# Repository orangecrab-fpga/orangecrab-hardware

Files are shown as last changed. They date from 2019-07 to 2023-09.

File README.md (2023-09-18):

# OrangeCrab
[OrangeCrab Web site](https://orangecrab-fpga.github.io/orangecrab-hardware/)

## ECP5 FPGA Feather development board.
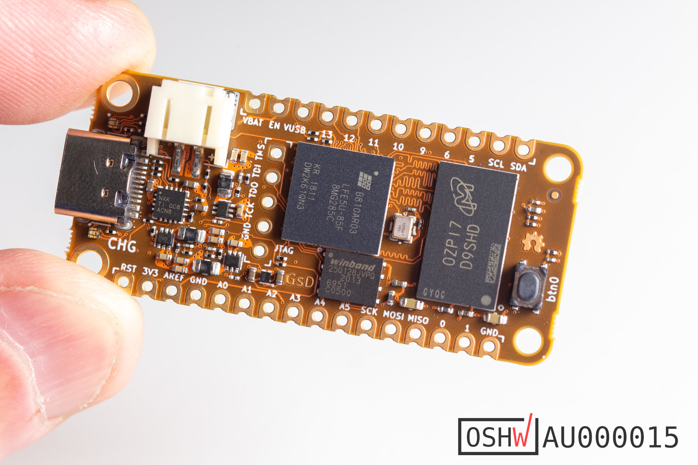
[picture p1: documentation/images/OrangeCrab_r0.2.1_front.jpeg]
Front Photo


## Latest Revision: 
* [OrangeCrab r0.2.1](hardware/orangecrab_r0.2.1/)

Previous Revisions:
* [OrangeCrab r0.2](hardware/orangecrab_r0.2/)
* [OrangeCrab r0.1](hardware/orangecrab_r0.1/)

---

## What is it?
There aren't many OSHW ECP5 boards available. Given that this FPGA is fully supported by an open source toolchain I decided to create one. In order to make use of the DDR3L support the ECP5 has, I've added some DDR3L memory. The board matches the feather format

## Hardware Overview
* Lattice ECP5-25F or ECP5-85F FPGA in csfBGA285 package
    * 24 K - Look Up Tables
    * 1008 Kb - Embedded Block RAM
    * 194 Kb - Distributed RAM
    * 28 - 18x18 Multipliers
    * PLLs: 2
    * Internal oscillator
    * Flexible I/O for DDR3 Memory Support
* DDR3L Memory
    * 128 Mbytes (1Gbit) or 512Mbytes (4Gbit)
    * x16 data width to FPGA
    * 1.35V low voltage operation
* USB-C connection
    * Full-speed (12Mbit) USB with direct connection to FPGA
* Non-volatile Storage
    * 128Mbit QSPI FLASH Memory 
        * Bootloader (First 4Mbits)
        * User Bitstream
        * User storage (Firmware/MSC backend/etc)
        * QSPI compatible
    * MicroSD socket
        * 4bit SD interface (CK, CMD, DAT0-3)
* Power supply
    * High efficiency DCDC for main supplies
    * Battery charger (100mA), with charge indicator LED
    * LiPo battery connector (PH type) (1-cell: 3.7-4.2V)
* 48MHz onboard oscillator
* Accessible 0.1" JTAG breakout
* User I/O
    * 1x Button 
    * 1x RGB LED
    * 20x I/O on 0.1" headers
* Analog System
    * Analog Mux
    * SAR ADC, external RC / input comparator of FPGA
    * Digital bypass
    * Internal channels for supply monitor
    * Battery voltage sensing
* Feather Format Board
    * Dimensions: 22.86mm x 50.8mm (0.9" x 2.0")
    * Castellated I/O edges
---

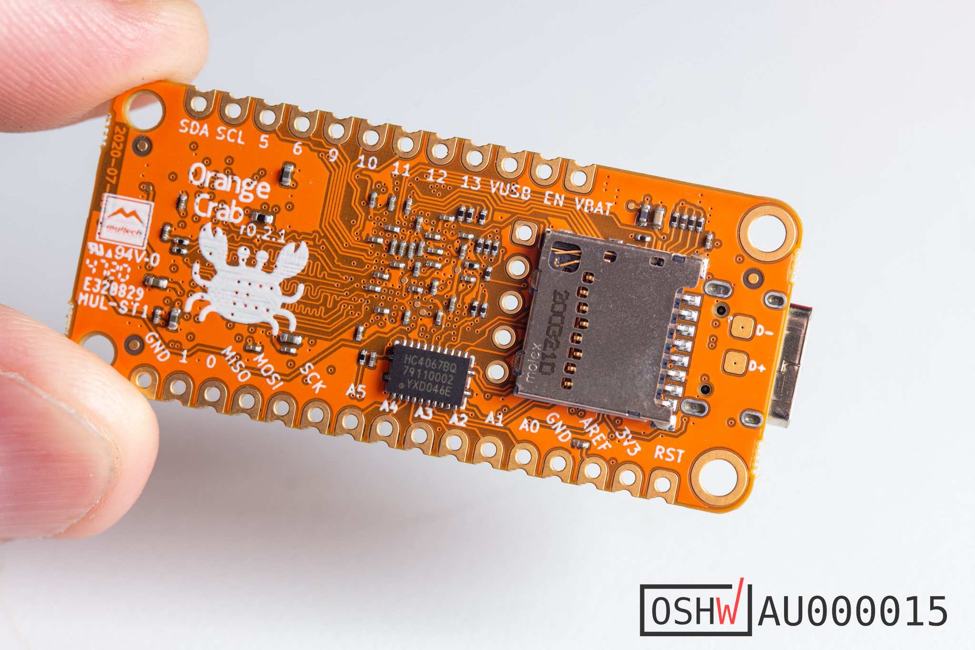
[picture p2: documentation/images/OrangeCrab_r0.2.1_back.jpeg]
Back Photo


## Example code
Example code for Verilog, Litex, And RiscV can be found here:

* [Orange Crab Examples](https://github.com/orangecrab-fpga/orangecrab-examples)

## Community

We have an OrangeCrab group on the 1BitSquared Discord 

 * https://discord.gg/c4Dnr3b

## Licence

 * Hardware in this repository is licensed under CERN OHL v1.2
 * Gateware/Software/Firmware in this repository is licensed under MIT unless otherwise indicated

 ## Open Source Hardware
This board is an OSHWA approved design: [AU000015](https://certification.oshwa.org/au000015.html)

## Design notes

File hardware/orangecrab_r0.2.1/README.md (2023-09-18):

# OrangeCrab r0.2.1
## ECP5 Feather development board.

Front Photo

	Hardware r0.2.1 has run through a production run and available at GroupGets, element14.
    
---

## What is it?
There aren't many OSHW ECP5 boards available. Given that this FPGA is fully supported by an open source toolchain I decided to create one. In order to make use of the DDR3L support the ECP5 has, I've added some DDR3L memory. The board matches the feather format

## Hardware Overview
* Lattice ECP5-25F or ECP5-85F FPGA in csfBGA285 package
    * 24 K - Look Up Tables
    * 1008 Kb - Embedded Block RAM
    * 194 Kb - Distributed RAM
    * 28 - 18x18 Multipliers
    * PLLs: 2
    * Internal oscillator
    * Flexible I/O for DDR3 Memory Support
* DDR3L Memory
    * 128 Mbytes (1Gbit) or 512Mbytes (4Gbit)
    * x16 data width to FPGA
    * 1.35V low voltage operation
* USB-C connection
    * Full-speed (12Mbit) USB with direct connection to FPGA
* Non-volatile Storage
    * 128Mbit QSPI FLASH Memory 
        * Bootloader (First 4Mbits)
        * User Bitstream
        * User storage (Firmware/MSC backend/etc)
        * QSPI compatible
    * MicroSD socket
        * 4bit SD interface (CK, CMD, DAT0-3)
* Power supply
    * High effeciency DCDC for main supplies
    * Battery charger (100mA), with charge indicator LED
    * LiPo battery connector (PH type) (1-cell: 3.7-4.2V)
* 48MHz onboard oscillator
* Accesible 0.1" JTAG breakout
* User I/O
    * 1x Button 
    * 1x RGB LED
    * 20x I/O on 0.1" headers
* Analog System
    * Analog Mux
    * SAR ADC, external RC / input comparator of FPGA
    * Digital bypass
    * Internal channels for supply monitor
    * Battery voltage sensing
* Feather Format Board
    * Dimensions: 22.86mm x 50.8mm (0.9" x 2.0")
    * Castellated I/O edges

---

Back Photo

## Licence

 * Hardware in this repository is licensed under CERN OHL v1.2
 * Gateware/Software/Firmware in this repository is licensed under MIT unless otherwise indicated

 ## Open Source Hardware
This board is an OSHWA approved design: [AU000015](https://certification.oshwa.org/au000015.html)

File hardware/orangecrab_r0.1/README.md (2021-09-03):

# Orange Crab r0.1

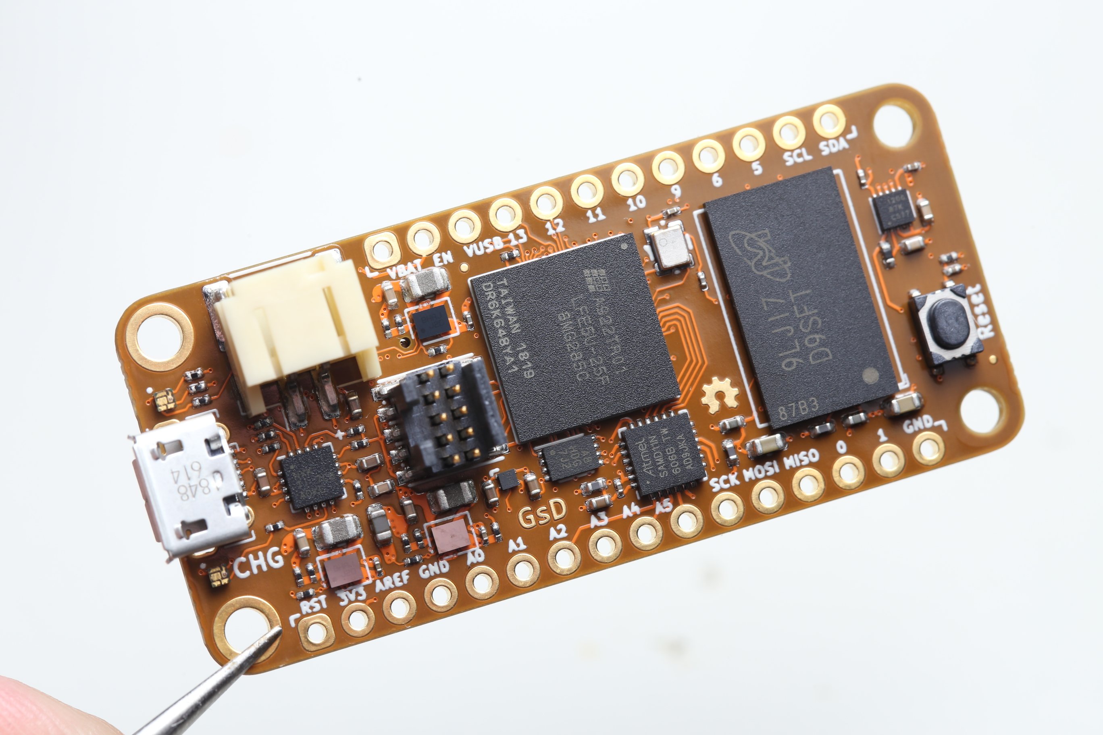
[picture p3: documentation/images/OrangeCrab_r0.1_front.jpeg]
Front


## ECP5 DDR3 memory in a Feather form-factor.

	Hardware r0.1 is not the latest hrdware version. There are some bugs listed below.

## What is it
Project goal: "Make a simple ECP5 breakout board with DDR3L memory". As that was the only design goal I also decide it might be nice to keep the overal size small and make it an adafruit feather compatible dev board.

## Hardware Overview
* Lattice ECP5 25 (With limited support for 45/85 variants)
* DDR3L Memory upto 1Gbit (64Mbit x16)
* Micro USB connection
* Full-speed (12Mbit) USB direct connection to FPGA
* Battery charger, with charge indicator LED (1-cell: 3.7-4.2V)
* Reset Button 
* 16Mbit QSPI FLASH Memory (Bitstream + User storage)
* 4bit MicroSD socket
* 48MHz Oscillator (Used by USB system)
* ATSAMD10/11 Co-processor planned mainly for the ADC/DAC
* Spare 3.3V I/O's broken out onto a 30pin low profile connector
  * 7 diff pairs
  * 1 single ended only

## Errata
 1. FLASH footprint only supports devices upto 16Mbit in size, This is enough for a bootloader and user gateware on the 25/45F parts, but not enough for a fully loaded 85F design.
 2. DDR3 traces are quite close, violating the recommended 6mil clearance. Tests appear to indicate this isn't a huge deal on this design.
 3. No firmware was ever written for the SAMD11 co-precessor, so A0-A5 don't do anything.
 4. LED resistor values are not tuned very well, resulting in very bright USB-Present LED.
 5. The button is tied directly to `PROGRAMN` pin on the FPGA, this means pressing the button resets the device. (Which is used to toggle between user/bootloader gateware)

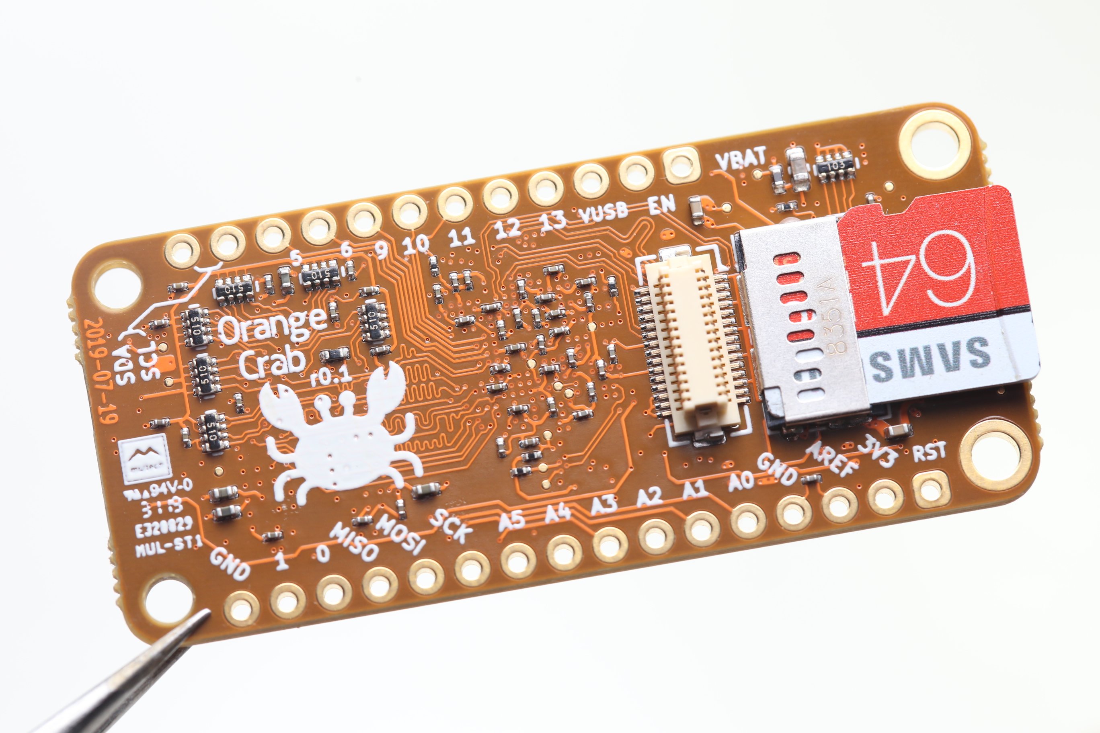
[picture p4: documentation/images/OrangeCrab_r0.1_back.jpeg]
Back Photo Back


## Licence

 * Hardware in this repository is licenced under CERN OHL v1.2
 * Gateware/Software/Firmware in this repository is licenced under MIT unless otherise indicated

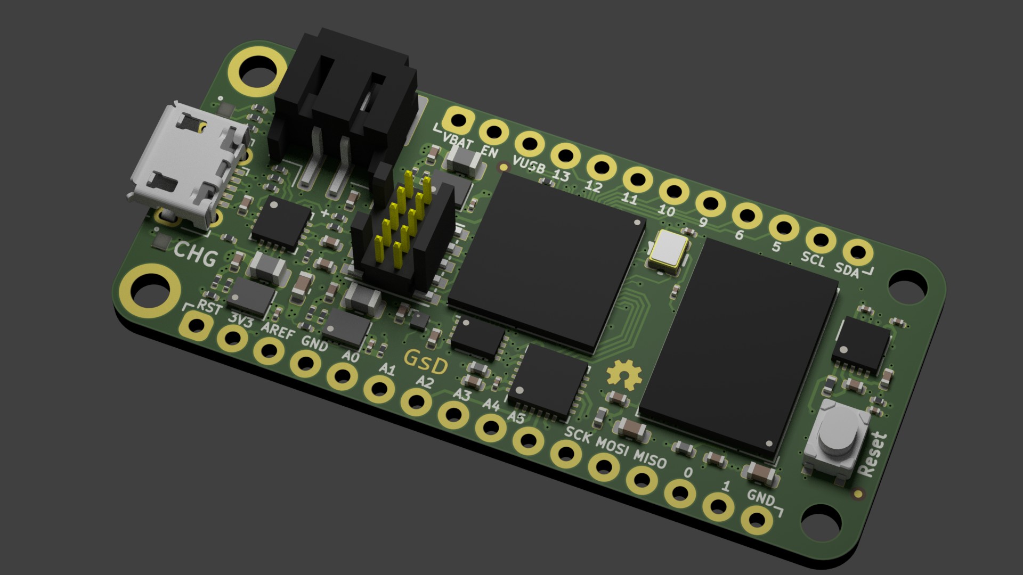
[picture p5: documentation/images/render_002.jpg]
Front Render


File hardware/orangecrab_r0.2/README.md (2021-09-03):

# OrangeCrab r0.2
## ECP5 Feather development board.

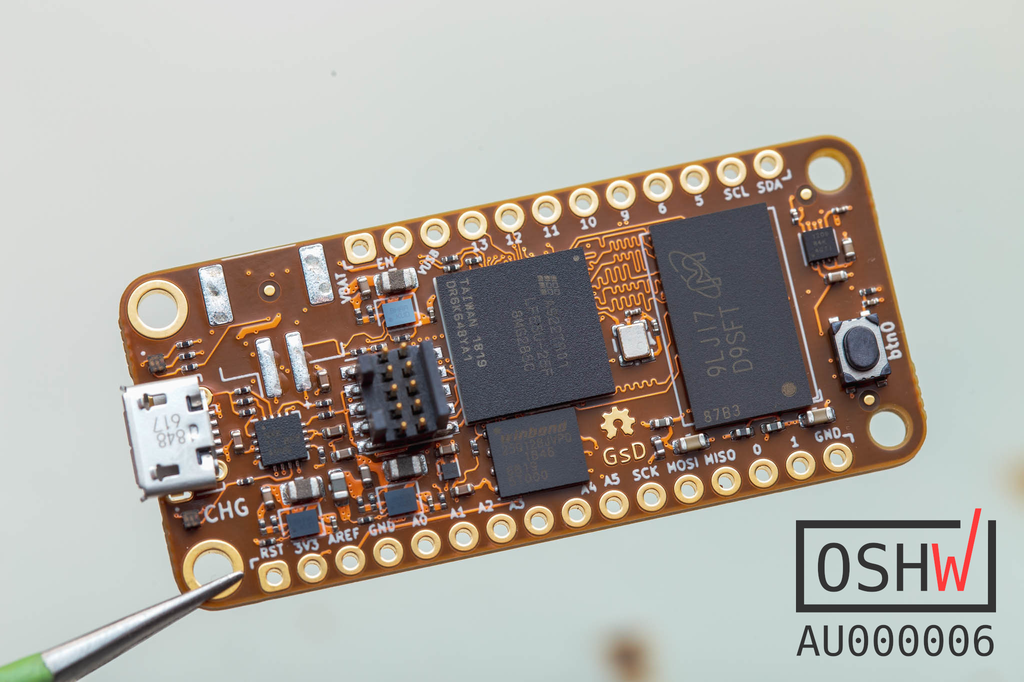
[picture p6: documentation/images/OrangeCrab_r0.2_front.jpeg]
Front Photo


	Hardware r0.2 will go though a short production run soon™
    
---

## What is it?
There aren't many OSHW ECP5 boards available. Given that this FPGA is fully supported by an open source toolchain I decided to create one. In order to make use of the DDR3L support the ECP5 has, I've added some DDR3L memory. The board matches the feather format

## Hardware Overview
* Lattice ECP5-25F FPGA in csfBGA285 package
    * 24 K - Look Up Tables
    * 1008 Kb - Embedded Block RAM
    * 194 Kb - Distributed RAM
    * 28 - 18x18 Multipliers
    * PLLs: 2
    * Internal oscillator
    * Flexible I/O for DDR3 Memory Support
* DDR3L Memory
    * 128 Mbytes (1Gbit)
    * 64M x16
    * 1.35V low voltage operation
* Micro USB connection
    * Full-speed (12Mbit) USB with direct connection to FPGA
* Non-volatile Storage
    * 128Mbit QSPI FLASH Memory 
        * Bootloader (First 4Mbits)
        * User Bitstream
        * User storage (Firmware/MSC backend/etc)
        * QSPI compatible
    * MicroSD socket
        * 4bit SD interface (CK, CMD, DAT0-3)
* Power supply
    * High effeciency DCDC for main supplies
    * Battery charger (100mA), with charge indicator LED
    * LiPo battery connector (PH type) (1-cell: 3.7-4.2V)
* 48MHz onboard oscillator
* Standard 0.05" JTAG connector
* User I/O
    * 1x Button 
    * 1x RGB LED
    * 20x I/O on 0.1" headers
* Analog System
    * Analog Mux
    * SAR ADC, external RC / input comparator of FPGA
    * Digital bypass
    * Internal channels for supply monitor
    * Battery voltage sensing
* Feather Format Board
    * Dimensions: 22.86mm x 50.8mm (0.9" x 2.0")

---

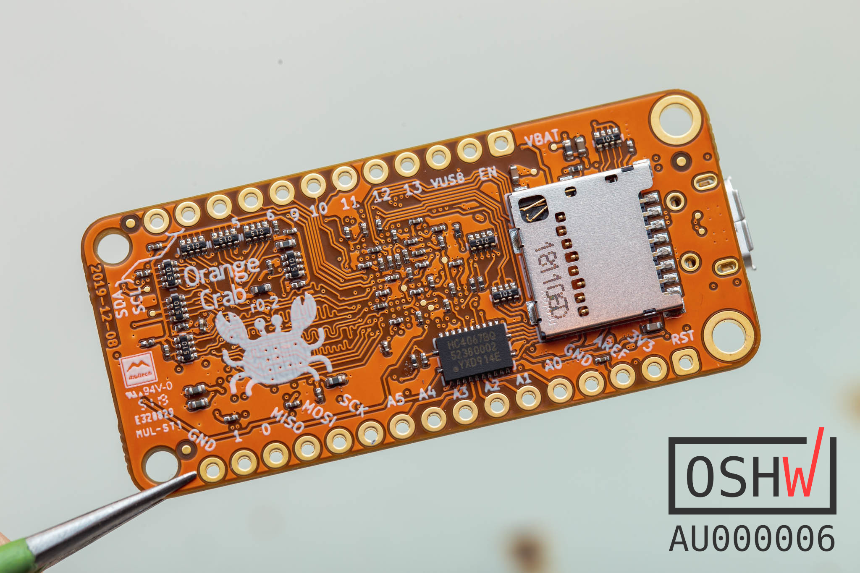
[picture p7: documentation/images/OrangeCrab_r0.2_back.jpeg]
Back Photo


## Licence

 * Hardware in this repository is licenced under CERN OHL v1.2
 * Gateware/Software/Firmware in this repository is licenced under MIT unless otherise indicated

 ## OSHW
This board is an OSHWA approved design: [AU000006](https://certification.oshwa.org/au000006.html)

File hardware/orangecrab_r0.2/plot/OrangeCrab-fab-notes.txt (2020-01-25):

Part number:        OrangeCrab-r0.2

General fabrication notes

    * Boards are to be panelised with tab/route, 5 by 1 pattern.
    * Board material is S1000-2
    * Orange solder mask (Colour reference: #FF8000) on both sides of board. All vias to be tented.
    * High DPI White LPI legend on both sides of board.
    * Pad finish is ENIG.
    * Finished board thickness is 1.6 mm.
    * Place UL mark and date code on legend on backside of board.

Impedances

    Control to within 10%.

    Layer 1 microstrip (ref to layer 2 Ground)
        121 μm trace = 50 ohm single ended

    Layer 3 microstrip (ref to layer 2 Ground / 4 Power)
        121 μm trace = 50 ohm single ended
        105 μm trace / 150 μm space = 100 ohm differential
        130 μm trace / 150 μm space = 90 ohm differential

    Layer 6 microstrip (ref to layer 5 Ground)
        121 μm trace = 50 ohm single ended
        105 μm trace / 150 μm space = 100 ohm differential

Suggested stackup Adjust to meet impedances
    1   35 μm (1 oz) copper         Signal
        0.075mm prepreg
    2   35 μm (1 oz) copper         Ground
        0.075mm prepreg
    3   35 μm (1oz) copper          Signal
        Core(s) and prepregs as needed for 1.6mm finished PCB thickness
    4   35 μm (1 oz) copper         Power
        0.075mm prepreg
    5   35 μm (1 oz) copper         Ground
        0.075mm prepreg
    6   35 μm (1 oz) copper         Signal

File naming
    OrangeCrab-Edge_Cuts.gbr        Board outline
    OrangeCrab-PTH.drl              Through-board plated holes
    OrangeCrab-NPTH.drl             Through-board unplated holes
    OrangeCrab-SilkTop.gbr          Front silkscreen
    OrangeCrab-MaskTop.gbr          Front solder mask
    OrangeCrab-CuTop.gbr            Layer 1 copper (Front)
    OrangeCrab-inner1.gbr           Layer 2 copper
    OrangeCrab-inner2.gbr           Layer 3 copper
    OrangeCrab-inner3.gbr           Layer 4 copper
    OrangeCrab-inner4.gbr           Layer 5 copper
    OrangeCrab-CuBottom.gbr         Layer 6 copper (Back)
    OrangeCrab-MaskBottom.gbr       Back solder mask
    OrangeCrab-SilkBottom.gbr       Back silkscreen

    OrangeCrab-PTH-drl_map.pdf      Drill Map Reference plated
    OrangeCrab-NPTH-drl_map.pdf     Drill Map Reference non-plated

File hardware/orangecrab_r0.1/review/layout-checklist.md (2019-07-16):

# Layout review checklist

## General

* [X] [Schematic review](schematic-checklist.md) complete and signed off, including pin swaps done during layout
* [X] Layout DRC 100% clean

## Decoupling

* [X] Decoupling caps as close to power pins as possible
* [X] Low inductance mounting used for decoupling (prefer ViP if available, otherwise "[]8" shaped side vias
   * No ViP available. Larger tracks used to help reduce inductance.

## DFM / yield enhancement

* [X] All design rules within manufacturer's capability
* [X] Minimize use of vias/traces that push fab limits
    * 0.15mm vias are un-avoidable. Design has been Checked by manufacturer
* [X] Controlled impedance specified in fab notes if applicable
    * Using values based on my suggested stackup and from ciPCB
* [-] Stackup verified with manufacturer and specified in fab notes
    * Still to be validated by Fab engineers.
* [X] Board finish specified in fab notes
* [X] If panelizing, add panel location indicators for identifying location-specific reflow issues
* [NA] (recommended) Layer number markers specified to ensure correct assembly
    * Lack of physical space :(
* [X] Fiducials present (on both sides of board) if targeting automated assembly
* [X] Fiducial pattern asymmetric to detect rotated or flipped boards
* [X] Soldermask/copper clearance on fiducials respected
* [X] Panelization specified if required
    * Fab has created panelisation

## Footprints

* [X] Confirm components are available in the selected package
* [X] Verify schematic symbol matches the selected package
* [X] Confirm pinout diagram is from top vs bottom of package
* [-] (recommended) PCB printed 1:1 on paper and checked against physical parts
    * TODO
* [X] 3D models obtained (if available) and checked against footprints
    * And rendered!
* [X] Soldermask apertures on all SMT lands and PTH pads

## Differential pairs
* [X] Routed differentially
* [X] Skew matched
* [-] Correct clearance to non-coupled nets
    * Tricky to do with space contraints. 

## High-speed signals

* [X] Sufficient clearance to potential aggressors
* [X] Length matched if required
* [X] Minimize crossing reference plane splits/slots or changing layers, use caps/stitching vias if unavoidable
* [NA] Confirm fab can do copper to edge of PCB for edge launch connectors
* [NA] Double-check pad width on connectors and add plane cutouts if needed to minimize impedance discontinuities

## Power
* [X] Minimal slots in planes from via antipads
* [X] Sufficient width for planes/traces for required current

## Sensitive analog
* [NA] Guard ring / EMI cages provided if needed
* [NA] Physically separated from high current SMPS or other noise sources
* [NA] Consider microphone effect on MLCCs if near strong sound sources

## Mechanical
* [X] LEDs, buttons, and other UI elements on outward-facing side of board
* [X] Keep-outs around PCB perimeter, card guides, panelization mouse-bites, etc respected
* [X] Stress-sensitive components (MLCC) sufficiently clear from V-score or mouse bite locations, and oriented to reduce bending stress
* [NA] Clearance around large ICs for heatsinks/fans if required
* [X] Clearance around pluggable connectors for mating cable/connector
* [X] Clearance around mounting holes for screws
* [NA] Plane keepouts and clearance provided for shielded connectors, magnetics, etc
* [X] Confirm PCB dimensions and mounting hole size/placement against enclosure or card rack design
* [X] Verify mounting hole connection/isolation
* [X] Components not physically overlapping/colliding
* [NA] Clearance provided around solder-in test points for probe tips

## Thermal

* [X] Thermal reliefs used for plane connections (unless via is used for heatsinking)
* [X] Solid connections used to planes if heatsinking
* [X] Ensure thermal balance on SMT chip components to minimize risk of tombstoning

## Solder paste

* [X] No uncapped vias in pads (except low-power QFNs where some voiding is acceptable)
* [ ] QFN paste prints segmented
* [ ] Small pads 100% size, larger pads reduced to avoid excessive solder volume

## Solder mask

* [X] Confirm SMD vs NSMD pad geometry
* [X] Adequate clearance around pads (typ. 50 um)

## Silkscreen

* [X] Text size within fab limits
* [X] Text not overlapping drills or component pads
* [X] Text removed entirely in, or moved outside of, high component/via density areas
* [X] Traceability markings (rev, date, name, etc) provided
* [NA] Silkscreen box provided for writing/sticking serial number
* [X] Text mirrored properly on bottom layer

## Flex specific
* [NA] Components oriented to reduce bending forces
* [ ] Teardrops on all wire-to-pad connections

## CAM production
* [ ] KiCAD specific: rerun DRC and zone fills before exporting CAM files to ensure proper results
* [ ] Export gerber/drill files at the same time to ensure consistency
* [ ] Visually verify final CAM files to ensure no obvious misalignments

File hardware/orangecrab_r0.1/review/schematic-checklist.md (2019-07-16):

# Schematic review checklist

## General

- [NA] CAD ERC 100% clean. If some errors are invalid due to toolchain quirks, each exception must be inspected and signed off as invalid.
- [X] Verify pin numbers of all schematic symbols against datasheet (if not yet board proven).
- [X] Schematic symbol matches chosen component package
- [X] Thermal pads are connected to correct power rail (may not always be ground)
- [x] Debug interfaces are not power gated in sleep mode

## Passive components
* [X] Power/voltage/tolerance ratings specified as required
* [X] Ceramic capacitors appropriately de-rated for C/V curve
* [X] Polarized components specified in schematic if using electrolytic caps etc

## Power supply

### System power input

* [NA] Fusing and/or reverse voltage protection at system power inlet
* [x] Check total input capacitance and add inrush limiter if needed

### Regulators

* [NA] Under/overvoltage protection configured correctly if used
* [X] Verify estimated power usage per rail against regulator rating
* [NA] Current-sense resistors on power rails after regulator output caps, not in switching loop
 * To reduce BOM this have been omitted, will cut traces during board bringup to validate power supplies.
* [NA] Remote sense used on low voltage or high current rails
* [X] Linear regulators are stable with selected output cap ESR
* [X] Confirm power rail sequencing against device datasheets

### Decoupling
* [X] Decoupling present for all ICs
* [X] Decoupling meets/exceeds vendor recommendations if specified
* [X] Bulk decoupling present at PSU

### General
* [X] All power inputs fed by correct voltage
* [NA] Check high-power discrete semiconductors and passives to confirm they can handle expected load
* [X] Analog rails filtered/isolated from digital circuitry as needed

## Signals

### Digital

* [X] Signals are correct logic level for input pin
* [X] Pullups on all open-drain outputs
* [NA] Pulldowns on all PECL outputs
* [X] Termination on all high-speed signals
* [NA] AC coupling caps on gigabit transceivers
* [X] TX/RX paired correctly for UART, SPI, MGT, etc
* [X] Differential pair polarity / pairing correct
* [X] Active high/low enable signal polarity correct
* [X] I/O banking rules met on FPGAs etc

### Analog

* [NA] RC time constant for attenuators sane given ADC sampling frequency
* [NA] Verify frequency response of RF components across entire operating range. Don't assume a "1-100 MHz" amplifier has the same gain across the whole range.

### Clocks

* [X] All oscillators meet required jitter / frequency tolerance. Be extra cautious with MEMS oscillators as these tend to have higher jitter.
* [NA] Correct load caps provided for discrete crystals
* [X] Crystals only used if IC has an integrated crystal driver
* [X] Banking / clock capable input rules met for clocks going to FPGAs

### Strap/init pins
* [ ] Pullup/pulldowns on all signals that need defined state at boot
* [X] Strap pins connected to correct rail for desired state
* [x] JTAG/ICSP connector provided for all programmable devices
    * GsD: SAMD has test pads exposed via test-points
* [x] Config/boot flash provided for all FPGAs or MPUs without internal flash
* [NA] Reference resistors correct value and reference rail

### External interface protection

* [NA] Power outputs (USB etc) current limited
* [NA] ESD protection on data lines going off board

### Debugging / reworkability

* [NA] Use 0-ohm resistors vs direct hard-wiring for strap pins when possible
* [X] Provide multiple ground clips/points for scope probes
* [x] Dedicated ground in close proximity to analog test points
* [X] Test points on all power rails
* [x] Test points on interesting signals which may need probing for bringup/debug
 * Added bottom test points to JTAG
 * DDR3 has termination on all Address lines, Upper byte traces are accesible on back layer.
 * Added USB Test pads

## Thermal

* [X] Power estimates for all large / high power ICs
    * ECP5 (@ 20% utilisation) 1/4W
* [NA] Thermal calculations for all large / high power ICs
* [NA] Specify heatsinks as needed

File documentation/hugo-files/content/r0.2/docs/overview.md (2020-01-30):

---
title: Overview
type: docs
rev: r0.2
---

# Overview

The OrangeCrab is a small pocket sized development board in the Adafruit feather format. While small in size it packs a punch! The standard version is equiped with a Lattice ECP5 FPGA, and DDR3L memory. Paired with the FPGA is a FLASH chip, with enough memory to store multiple bitstreams.

## FPGA
The FPGA used on the OrangeCrab is an ECP5 from Lattice Semiconductor. The ECP5 series is a medium tier, low power, low cost FPGA product line. This device supports various DDR3 memory interfaces, because of this the board features DDR3L memory. The ECP5 is also one of the platforms that is fully supported by the Open Source Synthesis flow.

## DDR3
There is DDR3L memory attached to the FPGA. The hardware is configured by default for DDR3L (1.35V). There are enough address lines wired to the memory to support upto 8Gbit parts. (Twin-die is not supported) The standard OrangeCrab configulation makes use of 1Gbit. This is connected to the FPGA using a 16-bit data bus. 

## USB
The micro usb connector is wired directly into the FPGA. Just as a microprocessor can emulate UART or SPI using standard I/O pins the FPGA can do the same for USB. By using some of the FPGA logic to create a USB core, we can use the I/O pins on the FPGA to act as a USB device. This will operate at USB 2.0 full-speed rates (12Mbit/s). Operating at High Speed rates (480Mbit/s) is not possible with the OrangeCrab hardware.

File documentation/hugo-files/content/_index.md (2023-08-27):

---
title: Introduction
type: docs
rev: r0.2
---

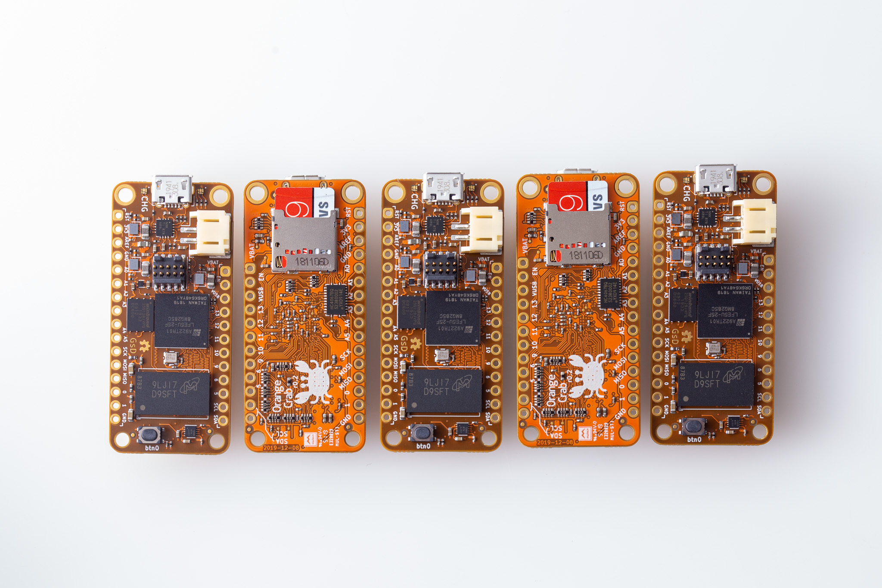
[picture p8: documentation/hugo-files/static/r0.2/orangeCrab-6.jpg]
OrangeCrab Photo


# Introduction

The OrangeCrab is a small pocket sized development board in the Adafruit feather format. While small in size it packs a punch! The standard version is equipped with a Lattice ECP5 FPGA, and DDR3L memory. Paired with the FPGA is a FLASH chip, with enough memory to store multiple bitstreams.

## FPGA
The FPGA used on the OrangeCrab is an ECP5 from Lattice Semiconductor. The ECP5 series is a medium tier, low power, low cost FPGA product line. This device supports various DDR3 memory interfaces, because of this the board features DDR3L memory. The ECP5 is also one of the platforms that is fully supported by the Open Source Synthesis flow.

## DDR3
There is DDR3L memory attached to the FPGA. The hardware is configured by default for DDR3L (1.35V). There are enough address lines wired to the memory to support upto 8Gbit parts. (Twin-die is not supported) The standard OrangeCrab configuration makes use of 1Gbit. This is connected to the FPGA using a 16-bit data bus. 

## USB
The micro usb connector is wired directly into the FPGA. Just as a microprocessor can emulate UART or SPI using standard I/O pins the FPGA can do the same for USB. By using some of the FPGA logic to create a USB core, we can use the I/O pins on the FPGA to act as a USB device. This will operate at USB 2.0 full-speed rates (12Mbit/s). Operating at High Speed rates (480Mbit/s) is not possible with the OrangeCrab hardware.

## Hardware Versions

There are currently 3 released version of the board:

{{< hint info >}}
### [Hardware r0.2.1]({{< relref "/docs/r0.2.1.md" >}})
Status: Currently produced design
        
#### Changes from r0.2:
- Changed USB micro-b to USB-C
- Swapped DCDC devices
- Added support for ECP5 85F-5G
- Added Castellated I/O pins 
{{< /hint >}}

{{< hint warning >}}
### [Hardware r0.2]({{< relref "/docs/r0.2.md" >}})
Status: Superseded

#### Changes from r0.1:
- Added FPGA I/O based ADC
- Add User Button and self-reset
- Larger FLASH 2MBytes -> 16MBytes
{{< /hint >}}

{{< hint warning >}}
### [Hardware r0.1]({{< relref "/docs/r0.1.md" >}})
Status: Prototype only

#### Standout Features:
- 2MByte FLASH 2x3mm USON part
- ATSAMD10/11 Co-processor planned mainly for the ADC/DAC (fw never written)
- Expansion port on the bottom of the feather breaking out extra I/O differential pairs.
{{< /hint >}}

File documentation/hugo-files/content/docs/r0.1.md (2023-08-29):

---
title: Introduction
type: docs
rev: r0.1
---

Front Photo

## Description

Initial version of the OrangeCrab, an electronics development board featuring a Lattice ECP5 FPGA, and DDR3 memory. Primarily designed to prototype RISCV SoC and evaluate custom peripherals.

## Technical details

* Lattice ECP5 25 (With limited support for 45/85 variants)
* DDR3L Memory upto 1Gbit (64Mbit x16)
* Micro USB connection
* Full-speed (12Mbit) USB direct connection to FPGA
* Battery charger, with charge indicator LED
* Reset Button 
* 16Mbit QSPI FLASH Memory (Bitstream + User storage)
* 4bit MicroSD socket
* 48MHz Oscillator (Used by USB system)
* ATSAMD10/11 Co-processor planned mainly for the ADC/DAC
* Spare 3.3V I/O's broken out onto a 30pin low profile connector
  * 7 diff pairs
  * 1 single ended only

## Photos
Front Photo
Back Photo

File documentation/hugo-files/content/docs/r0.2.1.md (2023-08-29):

---
title: Introduction
type: docs
rev: r0.2
---

Front Photo

## Description

Updated version of the OrangeCrab, an electronics development board featuring a Lattice ECP5 FPGA, and DDR3 memory. Primarily designed to prototype RISCV SoC and evaluate custom peripherals.

This updated version switched to USB-C, removed excessive DDR3 termination, changed the power supplies and added castellated edges to the I/O.

This version is in production by GroupGets, and available from GroupGets, 1BitSquared, and element14. 

## Technical details

Here are the main details for the OrangeCrab (25F/85F)
* Lattice ECP5-25F or ECP5-85F FPGA in csfBGA285 package
    * 24 K - Look Up Tables
    * 1008 Kb - Embedded Block RAM
    * 194 Kb - Distributed RAM
    * 28 - 18x18 Multipliers
    * PLLs: 2
    * Internal oscillator
    * Flexible I/O for DDR3 Memory Support
* DDR3L Memory
    * 128 Mbytes (1Gbit) or 512Mbytes (4Gbit)
    * x16 data width to FPGA
    * 1.35V low voltage operation
* USB-C connection
    * Full-speed (12Mbit) USB with direct connection to FPGA
* Non-volatile Storage
    * 128Mbit QSPI FLASH Memory 
        * Bootloader (First 4Mbits)
        * User Bitstream
        * User storage (Firmware/MSC backend/etc)
        * QSPI compatible
    * MicroSD socket
        * 4bit SD interface (CK, CMD, DAT0-3)
* Power supply
    * High effeciency DCDC for main supplies
    * Battery charger (100mA), with charge indicator LED
    * LiPo battery connector (PH type) (1-cell: 3.7-4.2V)
* 48MHz onboard oscillator
* Accesible 0.1" JTAG breakout
* User I/O
    * 1x Button 
    * 1x RGB LED
    * 20x I/O on 0.1" headers
* Analog System
    * Analog Mux
    * SAR ADC, external RC / input comparator of FPGA
    * Digital bypass
    * Internal channels for supply monitor
    * Battery voltage sensing
* Feather Format Board
    * Dimensions: 22.86mm x 50.8mm (0.9" x 2.0")
    * Castellated I/O edges

## Pinouts

### DDR3 (IOVCC=1.35V)

{{< columns >}}

| Name | Pad |
|--:|:--:|
| ADDR[0] | C4 |
| ADDR[1] | D2 |
| ADDR[2] | D3 |
| ADDR[3] | A3 |
| ADDR[4] | A4 |
| ADDR[5] | D4 |
| ADDR[6] | C3 |
| ADDR[7] | B2 |
| ADDR[8] | B1 |
| ADDR[9] | D1 |
| ADDR[10] | A7 |
| ADDR[11] | C2 |
| ADDR[12] | B6 |
| ADDR[13] | C1 |
| ADDR[14] | A2 |
| ADDR[15] | C7 |
| ODT | C13 |
| RESETn | L18 |
{.table-fill}

<---> <!-- magic separator, between columns -->

| Name | Pad |
|--:|:--:|
| BA[0] | D6 |
| BA[1] | B7 |
| BA[2] | A6 |
| RAS | C12 |
| CAS | D13 |
| WEn | B12 |
| CSn | A12 |
| DM[0] | D16 |
| DM[1] | G16 |
| DQ[0] | C17 |
| DQ[1] | D15 |
| DQ[2] | B17 |
| DQ[3] | C16 |
| DQ[4] | A15 |
| DQ[5] | B13 |
| DQ[6] | A17 |
| DQ[7] | A13 |
| DQ[8] | F17 |
{.table-fill}

<---> <!-- magic separator, between columns -->

| Name | Pad |
|--:|:--:|
| DQ[9] | F16 |
| DQ[10] | G15 |
| DQ[11] | F15 |
| DQ[12] | J16 |
| DQ[13] | C18 |
| DQ[14] | H16 |
| DQ[15] | F18 |
| DQS_n[0] | B15 |
| DQS_p[1] | G18 |
| CLK_p | J18 |
| CKE | D18 |
| *virtual_vccio[0] | K16 |
| *virtual_vccio[1] | D17 |
| *virtual_vccio[2] | K15 |
| *virtual_vccio[3] | K17 |
| *virtual_vccio[4] | B18 |
| *virtual_vccio[5] | C6 |
| *virtual_gnd[0] | L15 |
| *virtual_gnd[1] | L16 |
{.table-fill}

{{< /columns >}}

{{< hint info >}}
* Virtual VCCIO and GND are connected to VCCIO and GND on the PCB. They should be driven HIGH and LOW respectively to reduce SSO noise on the DDR3 I/O bank.
{{< /hint >}}

### General (IOVCC=3.3V)

{{< columns >}}

| Name | Pad |
|--:|:--:|
| GPIO0 | N17 |
| GPIO1 | M18 |
| GPIO5 | B10 |
| GPIO6 | B9 |
| GPIO9 | C8 |
| GPIO10 | B8 |
| GPIO11 | A8 |
| GPIO12 | H2 |
| GPIO13 | J2 |
| GPIOA0 | L4 |
| GPIOA1 | N3 |
| GPIOA2 | N4 |
| GPIOA3 | H4 |
{.table-fill}

<---> <!-- magic separator, between columns -->

| Name | Pad |
|--:|:--:|
| clk48 | A9 |
| rgb_led0_r | K4 |
| rgb_led0_g | M3 |
| rgb_led0_b | J3 |
| BTN | J17 |
| RSTn | V17 |
| USB_p | N1 |
| USB_n | M2 |
| USB_pu | N2 |
| QSPI_CSn | U17 |
| QSPI_CLK | U16 |
| QSPI_DQ[0] | U18 |
| QSPI_DQ[1] | T18 |
| QSPI_DQ[2] | R18 |
| QSPI_DQ[3] | N18 |
{.table-fill}

<---> <!-- magic separator, between columns -->

| Name | Pad |
|--:|:--:|
| SD_DAT[0] | J1 |
| SD_DAT[1] | K3 |
| SD_DAT[2] | L3 |
| SD_DAT[3] | M1 |
| SD_CMD | K2 |
| SD_CLK | K1 |
| SD_CD | L1 |
| ANA_MUX[0] | F4 |
| ANA_MUX[0] | F3 |
| ANA_MUX[0] | F2 |
| ANA_MUX[0] | H1 |
| ANA_SENSE_L | G3 |
| ANA_SENSE_H | H3 |
| ANA_CTRL[0] | G1 |
| ANA_CTRL[1] | F1 |
{.table-fill}

{{< /columns >}}

## Photos
Front Photo
Back Photo

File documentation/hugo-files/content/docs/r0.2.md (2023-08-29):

---
title: Introduction
type: docs
rev: r0.2
---

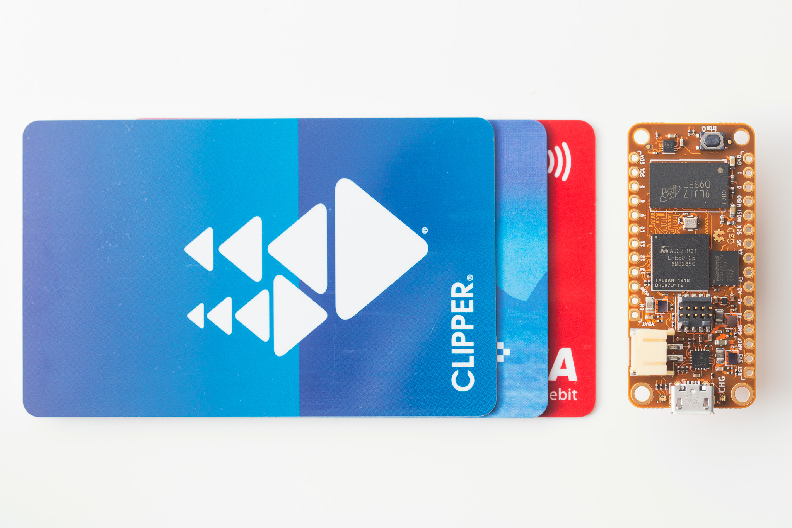
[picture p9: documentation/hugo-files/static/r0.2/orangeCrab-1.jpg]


## Description

Updated version of the OrangeCrab, an electronics development board featuring a Lattice ECP5 FPGA, and DDR3 memory. Primarily designed to prototype RISCV SoC and evaluate custom peripherals.

This updated version improved the multiboot experience by connecting an FPGA I/O to the reset line.

This version was produced as a small batch for a GroupGets campaign.

## Technical details

Here are the main details for the OrangeCrab (25F)
* Lattice ECP5-25F FPGA in csfBGA285 package
    * 24 K - Look Up Tables
    * 1008 Kb - Embedded Block RAM
    * 194 Kb - Distributed RAM
    * 28 - 18x18 Multipliers
    * PLLs: 2
    * Internal oscillator
    * Flexible I/O for DDR3 Memory Support
* DDR3L Memory
    * 128 Mbytes (1Gbit)
    * 64M x16
    * 1.35V low voltage operation
* Micro USB connection
    * Full-speed (12Mbit) USB with direct connection to FPGA
* Non-volatile Storage
    * 128Mbit QSPI FLASH Memory 
        * Bootloader (First 4Mbits)
        * User Bitstream
        * User storage (Firmware/MSC backend/etc)
        * QSPI compatible
    * MicroSD socket
        * 4bit SD interface (CK, CMD, DAT0-3)
* Power supply
    * High effeciency DCDC for main supplies
    * Battery charger (100mA), with charge indicator LED
    * LiPo battery connector (PH type)
* 48MHz onboard oscillator
* Standard 0.05" JTAG connector
* User I/O
    * 1x Button 
    * 1x RGB LED
    * 20x I/O on 0.1" headers
* Analog System
    * Analog Mux
    * SAR ADC, external RC / input comparator of FPGA
    * Digital bypass
    * Internal channels for supply monitor
    * Battery voltage sensing
* Feather Format Board
    * Dimensions: 22.86mm x 50.8mm (0.9" x 2.0")

## Pinouts

### DDR3 (IOVCC=1.35V)

{{< columns >}}

| Name | Pad |
|--:|:--:|
| ADDR[0] | C4 |
| ADDR[1] | D2 |
| ADDR[2] | D3 |
| ADDR[3] | A3 |
| ADDR[4] | A4 |
| ADDR[5] | D4 |
| ADDR[6] | C3 |
| ADDR[7] | B2 |
| ADDR[8] | B1 |
| ADDR[9] | D1 |
| ADDR[10] | A7 |
| ADDR[11] | C2 |
| ADDR[12] | B6 |
| ADDR[13] | C1 |
| ADDR[14] | A2 |
| ADDR[15] | C7 |
| ODT | C13 |
| RESETn | L18 |
{.table-fill}

<---> <!-- magic separator, between columns -->

| Name | Pad |
|--:|:--:|
| BA[0] | D6 |
| BA[1] | B7 |
| BA[2] | A6 |
| RAS | C12 |
| CAS | D13 |
| WEn | B12 |
| CSn | A12 |
| DM[0] | D16 |
| DM[1] | G16 |
| DQ[0] | C17 |
| DQ[1] | D15 |
| DQ[2] | B17 |
| DQ[3] | C16 |
| DQ[4] | A15 |
| DQ[5] | B13 |
| DQ[6] | A17 |
| DQ[7] | A13 |
| DQ[8] | F17 |
{.table-fill}

<---> <!-- magic separator, between columns -->

| Name | Pad |
|--:|:--:|
| DQ[9] | F16 |
| DQ[10] | G15 |
| DQ[11] | F15 |
| DQ[12] | J16 |
| DQ[13] | C18 |
| DQ[14] | H16 |
| DQ[15] | F18 |
| DQS_n[0] | B15 |
| DQS_p[1] | G18 |
| CLK_p | J18 |
| CKE | D18 |
| *virtual_vccio[0] | K16 |
| *virtual_vccio[1] | D17 |
| *virtual_vccio[2] | K15 |
| *virtual_vccio[3] | K17 |
| *virtual_vccio[4] | B18 |
| *virtual_vccio[5] | C6 |
| *virtual_gnd[0] | L15 |
| *virtual_gnd[1] | L16 |
{.table-fill}

{{< /columns >}}

{{< hint info >}}
* Virtual VCCIO and GND are connected to VCCIO and GND on the PCB. They should be driven HIGH and LOW respectively to reduce SSO noise on the DDR3 I/O bank.
{{< /hint >}}

### General (IOVCC=3.3V)

{{< columns >}}

| Name | Pad |
|--:|:--:|
| GPIO0 | N17 |
| GPIO1 | M18 |
| GPIO5 | B10 |
| GPIO6 | B9 |
| GPIO9 | C8 |
| GPIO10 | B8 |
| GPIO11 | A8 |
| GPIO12 | H2 |
| GPIO13 | J2 |
| GPIOA0 | L4 |
| GPIOA1 | N3 |
| GPIOA2 | N4 |
| GPIOA3 | H4 |
{.table-fill}

<---> <!-- magic separator, between columns -->

| Name | Pad |
|--:|:--:|
| clk48 | A9 |
| rgb_led0_r | K4 |
| rgb_led0_g | M3 |
| rgb_led0_b | J3 |
| BTN | J17 |
| RSTn | V17 |
| USB_p | N1 |
| USB_n | M2 |
| USB_pu | N2 |
| QSPI_CSn | U17 |
| QSPI_CLK | U16 |
| QSPI_DQ[0] | U18 |
| QSPI_DQ[1] | T18 |
| QSPI_DQ[2] | R18 |
| QSPI_DQ[3] | N18 |
{.table-fill}

<---> <!-- magic separator, between columns -->

| Name | Pad |
|--:|:--:|
| SD_DAT[0] | J1 |
| SD_DAT[1] | K3 |
| SD_DAT[2] | L3 |
| SD_DAT[3] | M1 |
| SD_CMD | K2 |
| SD_CLK | K1 |
| SD_CD | L1 |
| ANA_MUX[0] | F4 |
| ANA_MUX[0] | F3 |
| ANA_MUX[0] | F2 |
| ANA_MUX[0] | H1 |
| ANA_SENSE_L | G3 |
| ANA_SENSE_H | H3 |
| ANA_CTRL[0] | G1 |
| ANA_CTRL[1] | F1 |
{.table-fill}

{{< /columns >}}

## Photos
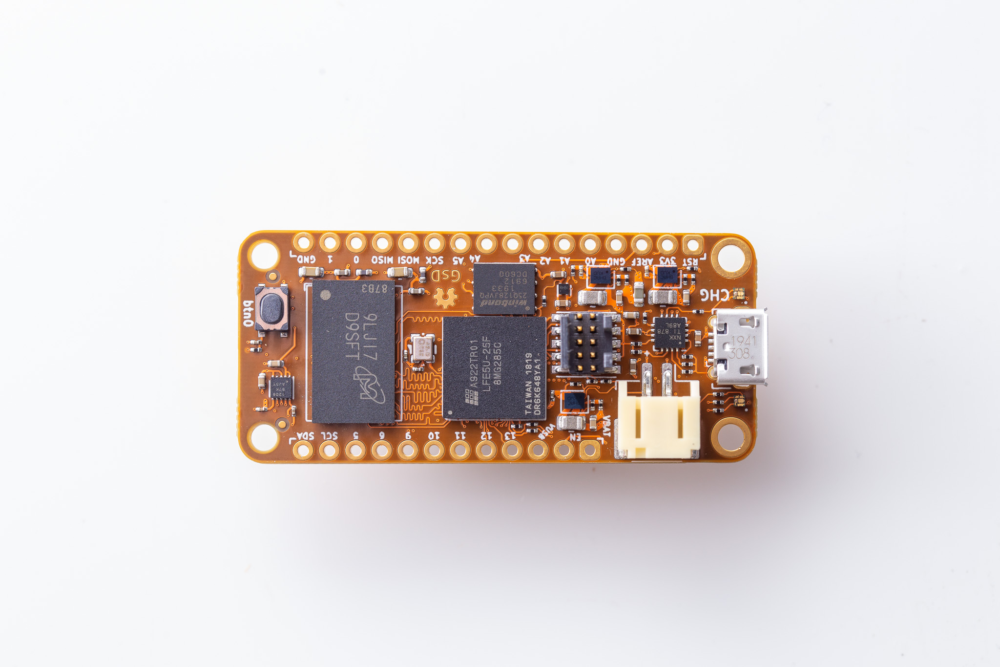
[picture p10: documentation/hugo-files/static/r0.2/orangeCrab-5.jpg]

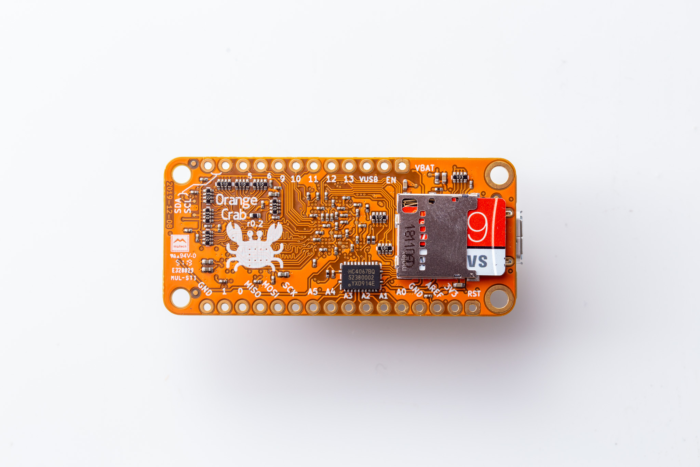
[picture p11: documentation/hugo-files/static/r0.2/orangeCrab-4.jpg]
Back Photo


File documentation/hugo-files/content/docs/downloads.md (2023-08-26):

---
title: Downloads
type: docs
rev: r0.2
---

# Downloads
---

## KiCad Sources
[OrangeCrab GitHub Repository](http://github.com/gregdavill/OrangeCrab)

## Other
 * [Interactive HTML Bill Of Materials](../r0.2/OrangeCrab-r0.2-ibom.html)

 * [Schematic (PDF)](https://github.com/gregdavill/OrangeCrab/raw/main/hardware/orangecrab_r0.2/Production/OrangeCrab-r0.2-sch.pdf)

 * [Board CAD model (STEP)](https://github.com/gregdavill/OrangeCrab/raw/main/hardware/orangecrab_r0.2/Production/OrangeCrab-r0.2.step)

 * [Production Gerbers (ZIP)](https://github.com/gregdavill/OrangeCrab/raw/main/hardware/orangecrab_r0.2/Production/OrangeCrab-r0.2-gerbers-20200126_122805.zip)

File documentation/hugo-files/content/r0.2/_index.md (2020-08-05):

---
title: Introduction
type: docs
rev: r0.2
---

# Introduction

The OrangeCrab is an electronics development board. It is FPGA based featuring an ECP5 from Lattice. The board follows the slim [feather board specification](https://learn.adafruit.com/adafruit-feather/feather-specification) from Adafruit. The FPGA is compatible with all opensource toolchains and is perfect for experimenting with RISC-V cores. There aren't many FPGA boards available that make use of the ECP5, but here are some distinct features that set this broad apart:

* Small Compact size (Take it anywhere!)
* Direct USB connection to the FPGA (Operate as a DFU, MSC, CDC, or composite device!)
* Onboard DDR3 Memory (1Gbit!)
* Preloaded DFU bootloader (No external programmer required!)
* It's Orange!

Front Photo

## Technical details

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

## Photos
Front Photo
Back Photo

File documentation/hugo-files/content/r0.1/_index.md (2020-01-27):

---
title: Introduction
type: docs
rev: r0.1
---

# Introduction

The OrangeCrab is an FPGA development board based around the Lattice ECP5 FPGA. The OrangeCrab features a direct USB connection to the FPGA and comes loaded with a DFU bootloader so you can get started without the need of an external programmer.

The OrangeCrab makes use of the logic inside the ECP5 to support DDR3L memory. In it's minimal configuration this adds 128Mbytes of memory to the FPGA. Example gateware is provided that creates a System-On-Chip inside the FPGA with this RAM memory mapped.

## Technical details

Here are the main details for the OrangeCrab

* Lattice ECP5 25 (With limited support for 45/85 variants)
* DDR3L Memory upto 1Gbit (64Mbit x16)
* Micro USB connection
* Full-speed (12Mbit) USB direct connection to FPGA
* Battery charger, with charge indicator LED
* Reset Button 
* 16Mbit QSPI FLASH Memory (Bitstream + User storage)
* 4bit MicroSD socket
* 48MHz Oscillator (Used by USB system)
* ATSAMD10/11 Co-processor planned mainly for the ADC/DAC
* Spare 3.3V I/O's broken out onto a 30pin low profile connector
  * 7 diff pairs
  * 1 single ended only

## Photos
Front Photo
Back Photo

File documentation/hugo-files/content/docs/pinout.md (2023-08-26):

---
title: Pinout
type: docs
rev: r0.2
---

# Pinout

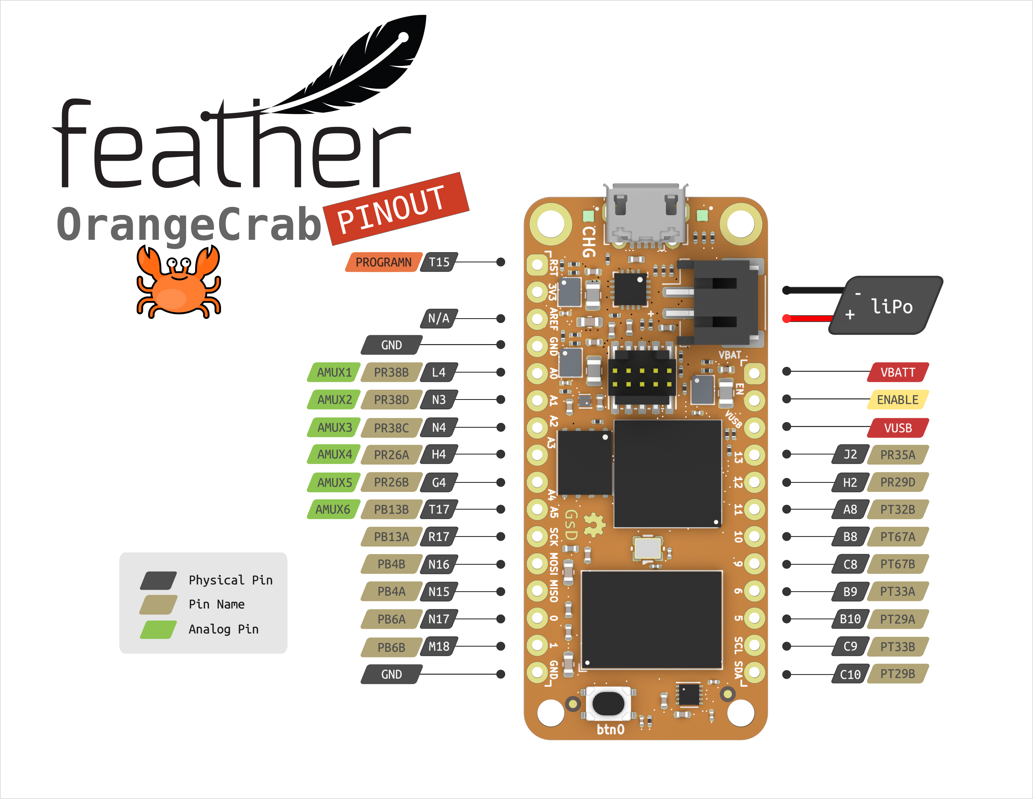
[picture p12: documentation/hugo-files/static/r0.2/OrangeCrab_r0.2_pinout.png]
Pinout

Click for larger version

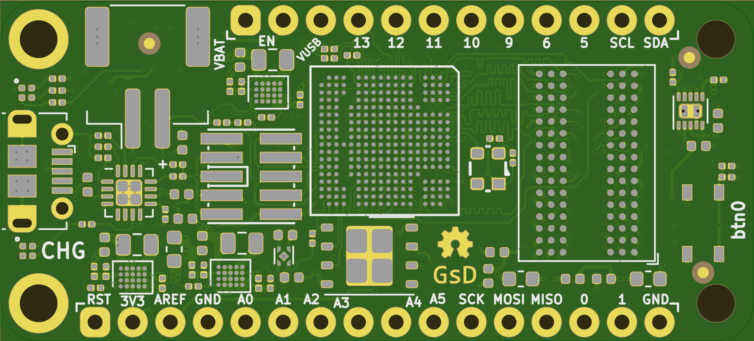
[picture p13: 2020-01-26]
hardware/orangecrab_r0.2/Production/OrangeCrab-Front.png

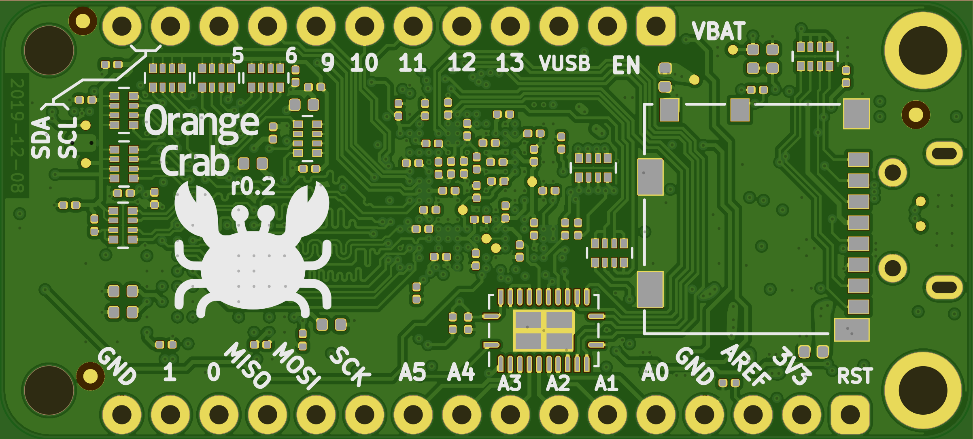
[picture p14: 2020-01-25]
hardware/orangecrab_r0.2/Production/OrangeCrab-Back.png

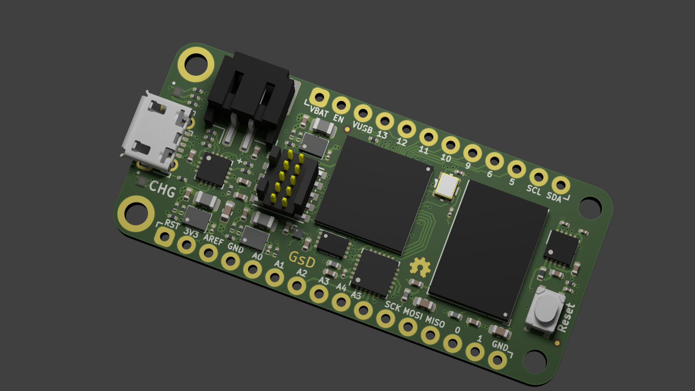
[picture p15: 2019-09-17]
documentation/images/render_001.png

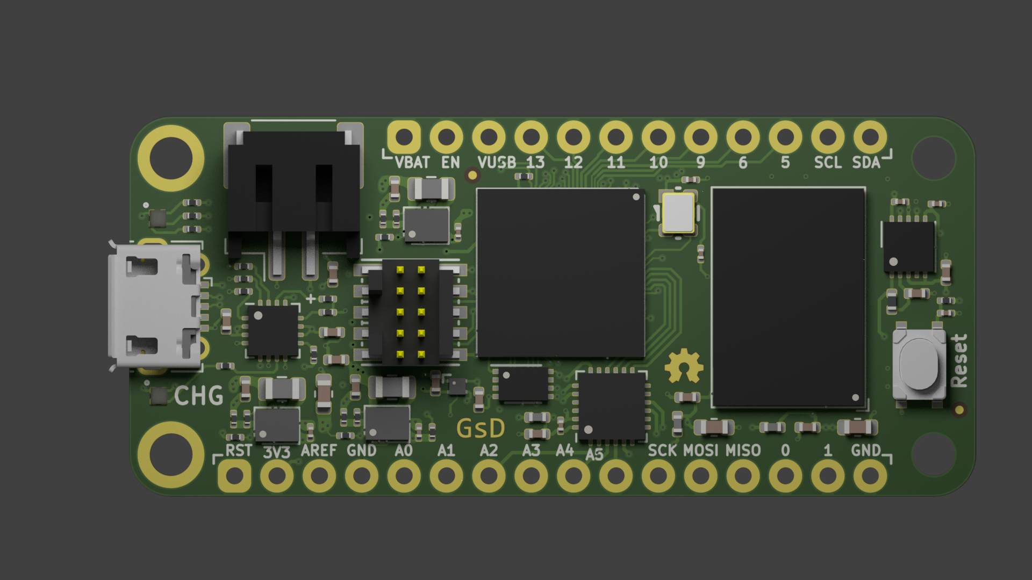
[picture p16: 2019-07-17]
documentation/images/top_render_001.png

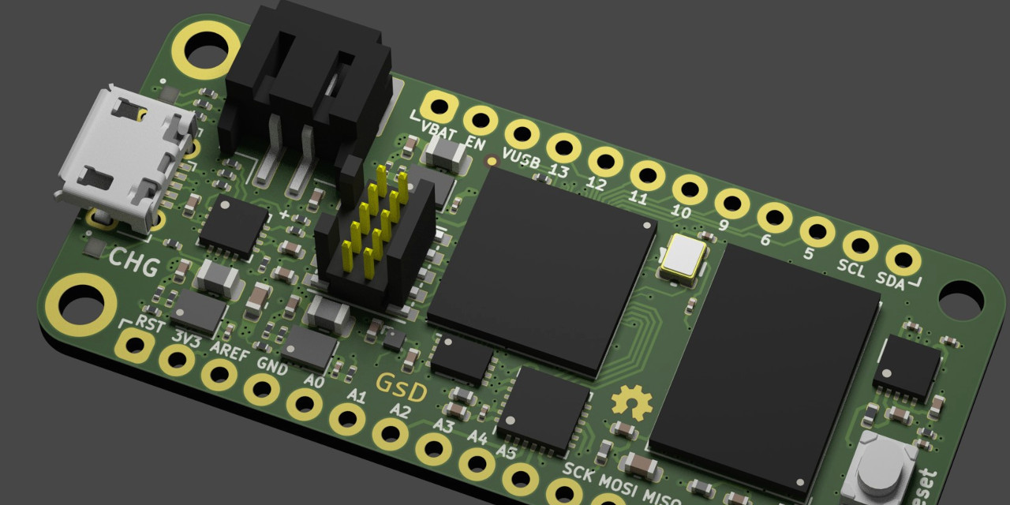
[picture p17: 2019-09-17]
documentation/images/render_003.jpg

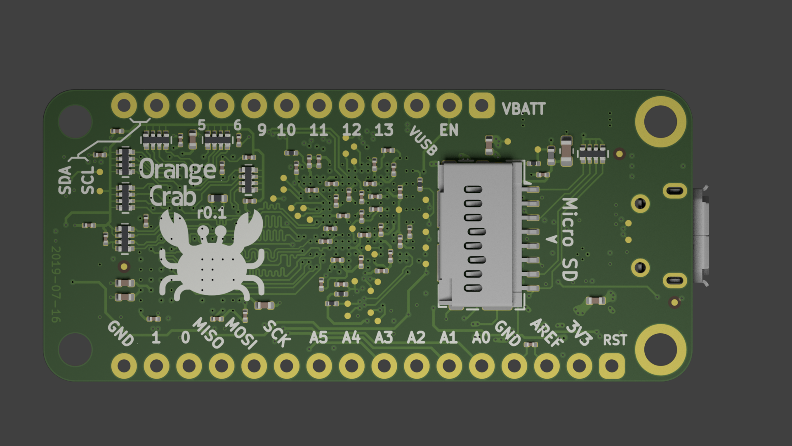
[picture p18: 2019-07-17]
documentation/images/bot_render_001.png

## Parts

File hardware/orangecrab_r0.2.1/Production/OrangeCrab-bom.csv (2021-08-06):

Item | Qty | Reference(s) | Value | LibPart | Footprint | Datasheet | Info | Mfg | Mfg_1 | PN | PN_1 | mfg_product-variant:85F/4G | pn_product-variant: 85F/4G
1 | 16 | C1, C19, C25, C48, C49, C52, C53, C56, C58, C60, C62, C63, C66, C67, C74, C76 | 10nF | Device:C | gkl_dipol:C_0201_0603Metric | ~ |  | Samsung Electro-Mechanics | YAGEO | CL03B103KP3NNNC | CC0201KRX5R7BB103
2 | 24 | C2, C4, C20, C26, C27, C28, C30, C31, C32, C33, C50, C51, C54, C55, C57, C59, C61, C64, C65, C68, C69, C70, C71, C75 | 100nF | Device:C | gkl_dipol:C_0201_0603Metric | ~ |  | Samsung Electro-Mechanics | YAGEO | CL03A104KQ3NNNC | CC0201KRX5R7BB104
3 | 7 | C3, C21, C22, C34, C35, C36, C37 | 1uF | Device:C | Capacitor_SMD:C_0402_1005Metric | ~ |  | Taiyo Yuden | YAGEO | JMK105C6105KV-F | CC0402KRX5R7BB105
4 | 3 | C5, C10, C18 | 10pF | Device:C | gkl_dipol:C_0201_0603Metric | ~ |  | Samsung Electro-Mechanics | YAGEO | CL03C100JA3GNNC | CC0201DRNPO8BN100
5 | 10 | C6, C7, C8, C9, C11, C14, C15, C16, C17, C29 | 10uF | Device:C | Capacitor_SMD:C_0402_1005Metric | ~ |  | Murata Electronics North America | YAGEO | GRM155R60J106ME15D | CC0402MRX5R5BB106
6 | 5 | C12, C13, C46, C47, C77 | 4.7uF | Device:C | Capacitor_SMD:C_0402_1005Metric | ~ | 10V, X5R | Murata Electronics North America | YAGEO | GRM155R61A475MEAAD | CC0402KRX5R6BB475
7 | 2 | C23, C24 | 22uF | Device:C | Capacitor_SMD:C_0603_1608Metric | ~ |  | Murata Electronics North America | YAGEO | GRM188R60J226MEA0D | CC0603MRX5R5BB226
8 | 2 | D1, D2 | LED_ARGB | Device:LED_ARGB | gkl_led:0404LED_RGB | ~ |  | OSRAM Opto Semiconductors Inc. | MEIHUA | LRTB R48G-P9Q7-1+R7S5-26+N5P-68-ZB | MHPA1010RGBDT
9 | 1 | FB1 | 600R | Device:Ferrite_Bead_Small | Inductor_SMD:L_0402_1005Metric | ~ |  | Murata Electronics North America | TDK | BLM15AG601SN1D | MMZ1005S601ET000
10 | 2 | FB2, FB3 | 600R | Device:L_Small | Inductor_SMD:L_0402_1005Metric | ~ |  | Murata Electronics North America | TDK | BLM15AG601SN1D | MMZ1005S601ET000
11 | 6 | FID1, FID2, FID3, FID4, FID5, FID6 | Fiducial | Mechanical:Fiducial | Fiducial:Fiducial_0.75mm_Mask1.5mm | ~ |  |  |  | DNP
12 | 2 | H1, H2 | MountingHole | Mechanical:MountingHole | MountingHole:MountingHole_2.2mm_M2_Pad | ~ |  |  |  | DNP
13 | 2 | H3, H4 | MountingHole | Mechanical:MountingHole | MountingHole:MountingHole_2.1mm | ~ |  |  |  | DNP
14 | 1 | J1 | Conn_01x12_Male | Connector:Conn_01x12_Male | gkl_conn:Feather_PinHeader_1x12 | ~ |  |  |  | DNP
15 | 1 | J2 | Conn_01x16_Male | Connector:Conn_01x16_Male | gkl_conn:Feather_PinHeader_1x16 | ~ |  |  |  | DNP
16 | 1 | J3 | USB_C_Receptacle_USB2.0 | Connector:USB_C_Receptacle_USB2.0 | Connector_USB:USB_C_Receptacle_HRO_TYPE-C-31-M-12 | https://www.usb.org/sites/default/files/documents/usb_type-c.zip |  | GCT | Jing Extension of the Electronic Co. | USB4105-GF-A | C167321
17 | 1 | J4 | MicroSd | Connector_Generic_MountingPin:Conn_01x09_MountingPin | gkl_conn:molex_microsd_1040310811 | ~ |  | Molex |  | 1040310811
18 | 1 | J5 | JST | Connector_Generic_MountingPin:Conn_01x02_MountingPin | gkl_conn:JST_PH_B2B-PH-SM4-TB_1x02-1MP_P2.00mm_Vertical | ~ |  | JST Sales America Inc. |  | S2B-PH-SM4-TB(LF)(SN)
19 | 1 | J6 | Conn_01x05_Male | Connector:Conn_01x05_Male | Connector_PinHeader_2.54mm:PinHeader_1x05_P2.54mm_Vertical | ~ |  |  |  | DNP
20 | 3 | L1, L2, L3 | 2.2uH | Device:L_Small | Inductor_SMD:L_0805_2012Metric | ~ |  | Murata Electronics | Sunltech Tech | LQM21PN2R2NGCD | SLM20122R2MIT
21 | 1 | OSC1 | KC2520B48.0000C10E00 | gkl_time:TYETBCSANF-32.000000 | gkl_time:Oscilator_2.5x2.0 |  |  | ECS Inc. | Yangxing Tech | ECS-2520MV-480-BN-TR | OT252048MJBA4SL
22 | 2 | R1, R2 | 1k | Device:R | gkl_dipol:R_0201_0603Metric | ~ |  | ‎Yageo‎ | UNI-ROYAL(Uniroyal Elec) | RC0201FR-071KL | 0201WMF1001TCE
23 | 8 | R3, R5, R6, R13, R48, R49, R50, R51 | 51R | Device:R | gkl_dipol:R_0201_0603Metric | ~ |  | ‎Yageo‎ | UNI-ROYAL(Uniroyal Elec) | RC0201FR-0751RL | 0201WMF510JTCE
24 | 6 | R4, R8, R23, R27, R30, R39 | 4.7k | Device:R | gkl_dipol:R_0201_0603Metric | ~ |  | ‎Yageo‎ | UNI-ROYAL(Uniroyal Elec) | RC0201FR-074K7L | 0201WMF4701TCE
25 | 12 | R7, R25, R26, R28, R32, R33, R40, R41, R42, R43, R44, R45 | 10k | Device:R | gkl_dipol:R_0201_0603Metric | ~ |  | ‎Yageo‎ | UNI-ROYAL(Uniroyal Elec) | RC0201FR-0710KL | 0201WMF1002TCE
26 | 2 | R9, R24 | 3.57k | Device:R | gkl_dipol:R_0201_0603Metric | ~ |  | ‎Yageo‎ | UNI-ROYAL(Uniroyal Elec) | RC0201FR-073K57L | 0201WMF3571TCE
27 | 1 | R10 | 56.2k | Device:R | gkl_dipol:R_0201_0603Metric | ~ |  | ‎Yageo‎ | UNI-ROYAL(Uniroyal Elec) | RC0201FR-0756K2L | 0201WMF5622TCE
28 | 1 | R11 | 3.09k | Device:R | gkl_dipol:R_0201_0603Metric | ~ |  | ‎Yageo‎ | UNI-ROYAL(Uniroyal Elec) | RC0201FR-073K09L | 0201WMF3091TCE
29 | 1 | R12 | 4.32k | Device:R | gkl_dipol:R_0201_0603Metric | ~ |  | ‎Yageo‎ | UNI-ROYAL(Uniroyal Elec) | RC0201FR-074K32L | 0201WMF4321TCE
30 | 3 | R14, R16, R46 | 5.1k | Device:R | gkl_dipol:R_0201_0603Metric | ~ |  | ‎Yageo‎ | UNI-ROYAL(Uniroyal Elec) | RC0201FR-075K1L | 0201WMF5101TCE
31 | 2 | R15, R35 | 120k | Device:R | gkl_dipol:R_0201_0603Metric | ~ |  | ‎Yageo‎ | UNI-ROYAL(Uniroyal Elec) | RC0201FR-07120KL | 0201WMF1203TCE
32 | 1 | R17 | 100k | Device:R | gkl_dipol:R_0201_0603Metric | ~ |  | ‎Yageo‎ | UNI-ROYAL(Uniroyal Elec) | RC0201FR-07100KL | 0201WMF1003TCE
33 | 2 | R18, R36 | DNP | Device:R | gkl_dipol:R_0201_0603Metric | ~ |  |  |  | DNP
34 | 1 | R19 | 240R | Device:R | Resistor_SMD:R_0402_1005Metric | ~ |  | ‎Yageo‎ | UNI-ROYAL(Uniroyal Elec) | RC0402FR-07240RL | 0402WGF2400TCE
35 | 3 | R20, R22, R31 | 1.5k | Device:R | gkl_dipol:R_0201_0603Metric | ~ |  | ‎Yageo‎ | UNI-ROYAL(Uniroyal Elec) | RC0201FR-071K5L | 0201WMF1501TCE
36 | 2 | R21, R29 | 20R | Device:R | gkl_dipol:R_0201_0603Metric | ~ |  | ‎Yageo‎ | UNI-ROYAL(Uniroyal Elec) | RC0201FR-0720RL | 0201WMF200JTCE
37 | 1 | R34 | 150k | Device:R | gkl_dipol:R_0201_0603Metric | ~ |  | ‎Yageo‎ | UNI-ROYAL(Uniroyal Elec) | RC0201FR-07150KL | 0201WMF1503TCE
38 | 1 | R37 | 360k | Device:R | gkl_dipol:R_0201_0603Metric | ~ |  | ‎Yageo‎ | UNI-ROYAL(Uniroyal Elec) | RC0201FR-07360KL | 0201WMF3603TCE
39 | 1 | R38 | 82k | Device:R | gkl_dipol:R_0201_0603Metric | ~ |  | ‎Yageo‎ | UNI-ROYAL(Uniroyal Elec) | RC0201FR-0782KL | 0201WMF8202TCE
40 | 1 | SW1 | SW_Push | Switch:SW_Push | gkl_misc:PTS_810_SMT_Switch | ~ |  | C&K | ALPS Electric | PTS810 SJM 250 SMTR LFS | SKRPACE010
41 | 3 | U1, U2, U7 | TLV62569DRL | Regulator_Switching:TLV62569DRL | Package_TO_SOT_SMD:SOT-563 | http://www.ti.com/lit/ds/symlink/tlv62569.pdf |  | Texas Instruments |  | TLV62569DRLR
42 | 1 | U3 | LFE5U-25F-8MG285C | gkl_lattice:ECP5U25-MG285 | gkl_housings_bga:csBGA285 |  |  | Lattice Semiconductor Corporation | Lattice Semiconductor Corporation | LFE5U-25F-8MG285C | LFE5U-25F-8MG285I | Lattice Semiconductor Corporation | LFE5U-85F-8MG285
43 | 1 | U4 | MT41K64M16TW-107_J-TR | gkl_mem:MT41K64M16TW-107_J-TR | Package_BGA:BGA-96_9.0x13.0mm_Layout2x3x16_P0.8mm |  |  | Micron Technology Inc. |  | MT41K64M16TW-107:J TR |  | Micron Technology Inc. | MT41K256M16TW
44 | 1 | U5 | BQ24232 | gkl_pmic:BQ24230 | Package_DFN_QFN:QFN-16-1EP_3x3mm_P0.5mm_EP1.75x1.75mm |  |  | Texas Instruments |  | BQ24232RGTR
45 | 1 | U6 | W25Q128JVP | gkl_mem:AT25SF081 | Package_SON:WSON-8-1EP_6x5mm_P1.27mm_EP3.4x4mm |  |  | Winbond Electronics |  | W25Q128JVPIQ
46 | 1 | U9 | 74HC4067BQ | 74xx:CD74HC4067M | Package_DFN_QFN:Texas_RGY_R-PVQFN-N24_EP2.05x3.1mm | http://www.ti.com/lit/ds/symlink/cd74hc4067.pdf |  | Nexperia USA Inc. |  | 74HC4067BQ\,118
47 | 1 | U10 | NCP115-2.5 | gkl_pmic:NCP167 | Package_SON:Texas_X2SON-4_1x1mm_P0.65mm | http://www.onsemi.com/pub/Collateral/NCP167-D.PDF |  | ON Semiconductor |  | NCP115CMX250TCG

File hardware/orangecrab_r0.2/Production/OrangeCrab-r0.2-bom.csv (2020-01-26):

Source: | /home/greg/projects/OrangeCrab/hardware/orangecrab_r0.2/OrangeCrab.sch
Date: | Sun 26 Jan 2020 12:26:21 ACDT
Tool: | Eeschema 5.1.5-52549c5~84~ubuntu18.04.1
Generator: | /usr/share/kicad/plugins/bom_csv_grouped_by_value.py
Component Count: | 154
Individual Components:
Item | Qty | Reference(s) | Value | LibPart | Footprint | Datasheet | Info | Mfg | PN | SN-DK
 |  | C1 | 10nF | Device:C | Capacitor_SMD:C_0201_0603Metric | ~ |  | Samsung Electro-Mechanics | CL03B103KP3NNNC
 |  | C2 | 10nF | Device:C | Capacitor_SMD:C_0201_0603Metric | ~ |  | Samsung Electro-Mechanics | CL03B103KP3NNNC
 |  | C3 | 10uF | Device:C | Capacitor_SMD:C_0603_1608Metric | ~ |  | Taiyo Yuden | LMK107BBJ106MALT
 |  | C4 | 100nF | Device:C | Capacitor_SMD:C_0201_0603Metric | ~ |  | Samsung Electro-Mechanics | CL03A104KQ3NNNC
 |  | C5 | 10nF | Device:C | Capacitor_SMD:C_0201_0603Metric | ~ |  | Samsung Electro-Mechanics | CL03B103KP3NNNC
 |  | C6 | 10uF | Device:C | Capacitor_SMD:C_0402_1005Metric | ~ |  | Murata Electronics North America | GRM155R60J106ME15D
 |  | C7 | 10uF | Device:C | Capacitor_SMD:C_0402_1005Metric | ~ |  | Murata Electronics North America | GRM155R60J106ME15D
 |  | C8 | 10uF | Device:C | Capacitor_SMD:C_0402_1005Metric | ~ | 6.3V, X5R | Murata Electronics North America | GRM155R60J106ME15D
 |  | C9 | 100nF | Device:C | Capacitor_SMD:C_0201_0603Metric | ~ |  | Samsung Electro-Mechanics | CL03A104KQ3NNNC
 |  | C10 | 0.22uF | Device:C | Capacitor_SMD:C_0201_0603Metric | ~ |  | Samsung Electro-Mechanics | CL03A224MQ3NNNC
 |  | C11 | 10uF | Device:C | Capacitor_SMD:C_0402_1005Metric | ~ | 6.3V, X5R | Murata Electronics North America | GRM155R60J106ME15D
 |  | C12 | 4.7uF | Device:C | Capacitor_SMD:C_0402_1005Metric | ~ | 10V, X5R | Murata Electronics North America | GRM155R61A475MEAAD
 |  | C13 | 4.7uF | Device:C | Capacitor_SMD:C_0402_1005Metric | ~ | 10V, X5R | Murata Electronics North America | GRM155R61A475MEAAD
 |  | C14 | 10nF | Device:C | Capacitor_SMD:C_0201_0603Metric | ~ |  | Samsung Electro-Mechanics | CL03B103KP3NNNC
 |  | C15 | 10uF | Device:C | Capacitor_SMD:C_0402_1005Metric | ~ |  | Murata Electronics North America | GRM155R60J106ME15D
 |  | C16 | 10uF | Device:C | Capacitor_SMD:C_0402_1005Metric | ~ |  | Murata Electronics North America | GRM155R60J106ME15D
 |  | C17 | 10uF | Device:C | Capacitor_SMD:C_0402_1005Metric | ~ |  | Murata Electronics North America | GRM155R60J106ME15D
 |  | C18 | 10uF | Device:C | Capacitor_SMD:C_0402_1005Metric | ~ |  | Murata Electronics North America | GRM155R60J106ME15D
 |  | C19 | 10nF | Device:C | Capacitor_SMD:C_0201_0603Metric | ~ |  | Samsung Electro-Mechanics | CL03B103KP3NNNC
 |  | C20 | 100nF | Device:C | Capacitor_SMD:C_0201_0603Metric | ~ |  | Samsung Electro-Mechanics | CL03A104KQ3NNNC
 |  | C21 | 1uF | Device:C | Capacitor_SMD:C_0402_1005Metric | ~ |  | Taiyo Yuden | JMK105C6105KV-F
 |  | C22 | 1uF | Device:C | Capacitor_SMD:C_0402_1005Metric | ~ |  | Taiyo Yuden | JMK105C6105KV-F
 |  | C23 | 22uF | Device:C | Capacitor_SMD:C_0603_1608Metric | ~ |  | Murata Electronics North America | GRM188R60J226MEA0D
 |  | C24 | 22uF | Device:C | Capacitor_SMD:C_0603_1608Metric | ~ |  | Murata Electronics North America | GRM188R60J226MEA0D
 |  | C25 | 10nF | Device:C | Capacitor_SMD:C_0201_0603Metric | ~ |  | Samsung Electro-Mechanics | CL03B103KP3NNNC
 |  | C26 | 100nF | Device:C | Capacitor_SMD:C_0201_0603Metric | ~ |  | Samsung Electro-Mechanics | CL03A104KQ3NNNC
 |  | C27 | 10nF | Device:C | Capacitor_SMD:C_0201_0603Metric | ~ |  | Samsung Electro-Mechanics | CL03B103KP3NNNC
 |  | C28 | 100nF | Device:C | Capacitor_SMD:C_0201_0603Metric | ~ |  | Samsung Electro-Mechanics | CL03A104KQ3NNNC
 |  | C29 | 10uF | Device:C | Capacitor_SMD:C_0402_1005Metric | ~ |  | Murata Electronics North America | GRM155R60J106ME15D
 |  | C30 | 100nF | Device:C | Capacitor_SMD:C_0201_0603Metric | ~ |  | Samsung Electro-Mechanics | CL03A104KQ3NNNC
 |  | C31 | 100nF | Device:C | Capacitor_SMD:C_0201_0603Metric | ~ |  | Samsung Electro-Mechanics | CL03A104KQ3NNNC
 |  | C32 | 100nF | Device:C | Capacitor_SMD:C_0201_0603Metric | ~ |  | Samsung Electro-Mechanics | CL03A104KQ3NNNC
 |  | C33 | 100nF | Device:C | Capacitor_SMD:C_0201_0603Metric | ~ |  | Samsung Electro-Mechanics | CL03A104KQ3NNNC
 |  | C34 | 1uF | Device:C | Capacitor_SMD:C_0402_1005Metric | ~ |  | Taiyo Yuden | JMK105C6105KV-F
 |  | C35 | 1uF | Device:C | Capacitor_SMD:C_0402_1005Metric | ~ |  | Taiyo Yuden | JMK105C6105KV-F
 |  | C36 | 1uF | Device:C | Capacitor_SMD:C_0402_1005Metric | ~ |  | Taiyo Yuden | JMK105C6105KV-F
 |  | C37 | 1uF | Device:C | Capacitor_SMD:C_0402_1005Metric | ~ |  | Taiyo Yuden | JMK105C6105KV-F
 |  | C38 | 10nF | Device:C | Capacitor_SMD:C_0201_0603Metric | ~ |  | Samsung Electro-Mechanics | CL03B103KP3NNNC
 |  | C39 | 100nF | Device:C | Capacitor_SMD:C_0201_0603Metric | ~ |  | Samsung Electro-Mechanics | CL03A104KQ3NNNC
 |  | C40 | 10nF | Device:C | Capacitor_SMD:C_0201_0603Metric | ~ |  | Samsung Electro-Mechanics | CL03B103KP3NNNC
 |  | C41 | 100nF | Device:C | Capacitor_SMD:C_0201_0603Metric | ~ |  | Samsung Electro-Mechanics | CL03A104KQ3NNNC
 |  | C42 | 10nF | Device:C | Capacitor_SMD:C_0201_0603Metric | ~ |  | Samsung Electro-Mechanics | CL03B103KP3NNNC
 |  | C43 | 100nF | Device:C | Capacitor_SMD:C_0201_0603Metric | ~ |  | Samsung Electro-Mechanics | CL03A104KQ3NNNC
 |  | C44 | 10nF | Device:C | Capacitor_SMD:C_0201_0603Metric | ~ |  | Samsung Electro-Mechanics | CL03B103KP3NNNC
 |  | C45 | 10nF | Device:C | Capacitor_SMD:C_0201_0603Metric | ~ |  | Samsung Electro-Mechanics | CL03B103KP3NNNC
 |  | C46 | 4.7uF | Device:C | Capacitor_SMD:C_0402_1005Metric | ~ | 10V, X5R | Murata Electronics North America | GRM155R61A475MEAAD
 |  | C47 | 4.7uF | Device:C | Capacitor_SMD:C_0402_1005Metric | ~ | 10V, X5R | Murata Electronics North America | GRM155R61A475MEAAD
 |  | C48 | 10nF | Device:C | Capacitor_SMD:C_0201_0603Metric | ~ |  | Samsung Electro-Mechanics | CL03B103KP3NNNC
 |  | C49 | 10nF | Device:C | Capacitor_SMD:C_0201_0603Metric | ~ |  | Samsung Electro-Mechanics | CL03B103KP3NNNC
 |  | C50 | 100nF | Device:C | Capacitor_SMD:C_0201_0603Metric | ~ |  | Samsung Electro-Mechanics | CL03A104KQ3NNNC
 |  | C51 | 100nF | Device:C | Capacitor_SMD:C_0201_0603Metric | ~ |  | Samsung Electro-Mechanics | CL03A104KQ3NNNC
 |  | C52 | 10nF | Device:C | Capacitor_SMD:C_0201_0603Metric | ~ |  | Samsung Electro-Mechanics | CL03B103KP3NNNC
 |  | C53 | 10nF | Device:C | Capacitor_SMD:C_0201_0603Metric | ~ |  | Samsung Electro-Mechanics | CL03B103KP3NNNC
 |  | C54 | 100nF | Device:C | Capacitor_SMD:C_0201_0603Metric | ~ |  | Samsung Electro-Mechanics | CL03A104KQ3NNNC
 |  | C55 | 100nF | Device:C | Capacitor_SMD:C_0201_0603Metric | ~ |  | Samsung Electro-Mechanics | CL03A104KQ3NNNC
 |  | C56 | 10nF | Device:C | Capacitor_SMD:C_0201_0603Metric | ~ |  | Samsung Electro-Mechanics | CL03B103KP3NNNC
 |  | C57 | 100nF | Device:C | Capacitor_SMD:C_0201_0603Metric | ~ |  | Samsung Electro-Mechanics | CL03A104KQ3NNNC
 |  | C58 | 10nF | Device:C | Capacitor_SMD:C_0201_0603Metric | ~ |  | Samsung Electro-Mechanics | CL03B103KP3NNNC
 |  | C59 | 100nF | Device:C | Capacitor_SMD:C_0201_0603Metric | ~ |  | Samsung Electro-Mechanics | CL03A104KQ3NNNC
 |  | C60 | 10nF | Device:C | Capacitor_SMD:C_0201_0603Metric | ~ |  | Samsung Electro-Mechanics | CL03B103KP3NNNC
 |  | C61 | 100nF | Device:C | Capacitor_SMD:C_0201_0603Metric | ~ |  | Samsung Electro-Mechanics | CL03A104KQ3NNNC
 |  | C62 | 10nF | Device:C | Capacitor_SMD:C_0201_0603Metric | ~ |  | Samsung Electro-Mechanics | CL03B103KP3NNNC
 |  | C63 | 10nF | Device:C | Capacitor_SMD:C_0201_0603Metric | ~ |  | Samsung Electro-Mechanics | CL03B103KP3NNNC
 |  | C64 | 100nF | Device:C | Capacitor_SMD:C_0201_0603Metric | ~ |  | Samsung Electro-Mechanics | CL03A104KQ3NNNC
 |  | C65 | 100nF | Device:C | Capacitor_SMD:C_0201_0603Metric | ~ |  | Samsung Electro-Mechanics | CL03A104KQ3NNNC
 |  | C66 | 10nF | Device:C | Capacitor_SMD:C_0201_0603Metric | ~ |  | Samsung Electro-Mechanics | CL03B103KP3NNNC
 |  | C67 | 10nF | Device:C | Capacitor_SMD:C_0201_0603Metric | ~ |  | Samsung Electro-Mechanics | CL03B103KP3NNNC
 |  | C68 | 100nF | Device:C | Capacitor_SMD:C_0201_0603Metric | ~ |  | Samsung Electro-Mechanics | CL03A104KQ3NNNC
 |  | C69 | 100nF | Device:C | Capacitor_SMD:C_0201_0603Metric | ~ |  | Samsung Electro-Mechanics | CL03A104KQ3NNNC
 |  | C70 | 100nF | Device:C | Capacitor_SMD:C_0201_0603Metric | ~ |  | Samsung Electro-Mechanics | CL03A104KQ3NNNC
 |  | C71 | 100nF | Device:C | Capacitor_SMD:C_0201_0603Metric | ~ |  | Samsung Electro-Mechanics | CL03A104KQ3NNNC
 |  | C74 | 10nF | Device:C | Capacitor_SMD:C_0201_0603Metric | ~ |  | Samsung Electro-Mechanics | CL03B103KP3NNNC
 |  | C75 | 100nF | Device:C | Capacitor_SMD:C_0201_0603Metric | ~ |  | Samsung Electro-Mechanics | CL03A104KQ3NNNC
 |  | C76 | 10nF | Device:C | Capacitor_SMD:C_0201_0603Metric | ~ |  | Samsung Electro-Mechanics | CL03B103KP3NNNC
 |  | C77 | 4.7uF | Device:C | Capacitor_SMD:C_0402_1005Metric | ~ | 10V, X5R | Murata Electronics North America | GRM155R61A475MEAAD
 |  | D1 | LED_ARGB | Device:LED_ARGB | gkl_led:0404LED_RGB | ~ |  | ‎Wurth Electronics Inc.‎ | 150044M155260
 |  | D2 | LED_ARGB | Device:LED_ARGB | gkl_led:0404LED_RGB | ~ |  | ‎Wurth Electronics Inc.‎ | 150044M155260
 |  | FB1 | 600R | Device:Ferrite_Bead_Small | Inductor_SMD:L_0402_1005Metric | ~ |  | Murata Electronics North America | BLM15AG601SN1D
 |  | FB2 | 600R | Device:L_Small | Inductor_SMD:L_0402_1005Metric | ~ |  | Murata Electronics North America | BLM15AG601SN1D
 |  | FB3 | 600R | Device:L_Small | Inductor_SMD:L_0402_1005Metric | ~ |  | Murata Electronics North America | BLM15AG601SN1D
 |  | FID1 | Fiducial | Mechanical:Fiducial | Fiducial:Fiducial_0.75mm_Mask1.5mm | ~
 |  | FID2 | Fiducial | Mechanical:Fiducial | Fiducial:Fiducial_0.75mm_Mask1.5mm | ~
 |  | FID3 | Fiducial | Mechanical:Fiducial | Fiducial:Fiducial_0.75mm_Mask1.5mm | ~
 |  | FID4 | Fiducial | Mechanical:Fiducial | Fiducial:Fiducial_0.75mm_Mask1.5mm | ~
 |  | FID5 | Fiducial | Mechanical:Fiducial | Fiducial:Fiducial_0.75mm_Mask1.5mm | ~
 |  | FID6 | Fiducial | Mechanical:Fiducial | Fiducial:Fiducial_0.75mm_Mask1.5mm | ~
 |  | H1 | MountingHole | Mechanical:MountingHole | MountingHole:MountingHole_2.2mm_M2_Pad | ~
 |  | H2 | MountingHole | Mechanical:MountingHole | MountingHole:MountingHole_2.2mm_M2_Pad | ~
 |  | H3 | MountingHole | Mechanical:MountingHole | MountingHole:MountingHole_2.1mm | ~
 |  | H4 | MountingHole | Mechanical:MountingHole | MountingHole:MountingHole_2.1mm | ~
 |  | J1 | Conn_01x12_Male | Connector:Conn_01x12_Male | gkl_conn:Feather_PinHeader_1x12 | ~
 |  | J2 | Conn_01x16_Male | Connector:Conn_01x16_Male | gkl_conn:Feather_PinHeader_1x16 | ~
 |  | J3 | USB_B_Micro | Connector:USB_B_Micro | Connector_USB:USB_Micro-B_Molex-105017-0001 | ~ |  | Molex | 1050170001
 |  | J4 | MicroSd | Connector_Generic_MountingPin:Conn_01x09_MountingPin | gkl_conn:molex_microsd_1040310811 | ~ |  | Molex | 1040310811
 |  | J5 | JST | Connector_Generic_MountingPin:Conn_01x02_MountingPin | gkl_conn:JST_PH_B2B-PH-SM4-TB_1x02-1MP_P2.00mm_Vertical | ~ |  | JST Sales America Inc. | S2B-PH-SM4-TB(LF)(SN)
 |  | J6 | JTAG | Connector_Generic:Conn_02x05_Odd_Even | gkl_conn:FTSH-105-XX-X-DV | ~ |  | Samtec Inc. | FTSH-105-01-F-DV-K-TR
 |  | L1 | 0.47uH | Device:L_Small | Inductor_SMD:L_0805_2012Metric | ~ |  | Samsung Electro-Mechanics | CIGT201210UHR47MNE
 |  | L2 | 0.47uH | Device:L_Small | Inductor_SMD:L_0805_2012Metric | ~ |  | Samsung Electro-Mechanics | CIGT201210UHR47MNE
 |  | L3 | 0.47uH | Device:L_Small | Inductor_SMD:L_0805_2012Metric | ~ |  | Samsung Electro-Mechanics | CIGT201210UHR47MNE
 |  | OSC1 | KC2520B48.0000C10E00 | gkl_time:TYETBCSANF-32.000000 | gkl_time:Oscilator_2.5x2.0 |  |  | Kyocera International Inc. Electronic Components | KC2520B48.0000C10E00
 |  | R1 | 100k | Device:R | Resistor_SMD:R_0201_0603Metric | ~ |  | ‎Yageo‎ | RC0201FR-07100KL
 |  | R2 | 31.6k | Device:R | Resistor_SMD:R_0201_0603Metric | ~ |  | ‎Yageo‎ | RC0201FR-0731K6L
 |  | R3 | 50R | Device:R | Resistor_SMD:R_0201_0603Metric | ~ |  | ‎Yageo‎ | RC0201FR-0750RL
 |  | R4 | 4.7k | Device:R | Resistor_SMD:R_0201_0603Metric | ~ |  | ‎Yageo‎ | RC0201FR-074K7L
 |  | R5 | 100k | Device:R | Resistor_SMD:R_0201_0603Metric | ~ |  | ‎Yageo‎ | RC0201FR-07100KL
 |  | R6 | 50R | Device:R | Resistor_SMD:R_0201_0603Metric | ~ |  | ‎Yageo‎ | RC0201FR-0750RL
 |  | R7 | 10k | Device:R | Resistor_SMD:R_0201_0603Metric | ~ |  | ‎Yageo‎ | RC0201FR-0710KL
 |  | R8 | 4.7k | Device:R | Resistor_SMD:R_0201_0603Metric | ~ |  | ‎Yageo‎ | RC0201FR-074K7L
 |  | R9 | 3.57k | Device:R | Resistor_SMD:R_0201_0603Metric | ~ |  | ‎Yageo‎ | RC0201FR-073K57L
 |  | R10 | 56.2k | Device:R | Resistor_SMD:R_0201_0603Metric | ~ |  | ‎Yageo‎ | RC0201FR-0756K2L
 |  | R11 | 3.06k | Device:R | Resistor_SMD:R_0201_0603Metric | ~ |  | ‎Yageo‎ | RC0201FR-073K09L
 |  | R12 | 4.32k | Device:R | Resistor_SMD:R_0201_0603Metric | ~ |  | ‎Yageo‎ | RC0201FR-074K32L
 |  | R13 | 100k | Device:R | Resistor_SMD:R_0201_0603Metric | ~ |  | ‎Yageo‎ | RC0201FR-07100KL
 |  | R14 | 100k | Device:R | Resistor_SMD:R_0201_0603Metric | ~ |  | ‎Yageo‎ | RC0201FR-07100KL
 |  | R15 | 267k | Device:R | Resistor_SMD:R_0201_0603Metric | ~ |  | ‎Yageo‎ | RC0201FR-07267KL
 |  | R16 | 147k | Device:R | Resistor_SMD:R_0201_0603Metric | ~ |  | ‎Yageo‎ | RC0201FR-07147KL
 |  | R17 | 100k | Device:R | Resistor_SMD:R_0201_0603Metric | ~ |  | ‎Yageo‎ | RC0201FR-07100KL
 |  | R18 | 100k | Device:R | Resistor_SMD:R_0201_0603Metric | ~ |  | ‎Yageo‎ | RC0201FR-07100KL
 |  | R19 | 240R | Device:R | Resistor_SMD:R_0402_1005Metric | ~ |  | ‎Yageo‎ | RC0402FR-07240RL
 |  | R20 | 1.5k | Device:R | Resistor_SMD:R_0201_0603Metric | ~ |  | ‎Yageo‎ | RC0201FR-071K5L
 |  | R21 | 20R | Device:R | Resistor_SMD:R_0201_0603Metric | ~ |  | ‎Yageo‎ | RC0201FR-0720RL
 |  | R22 | 1.5k | Device:R | Resistor_SMD:R_0201_0603Metric | ~ |  | ‎Yageo‎ | RC0201FR-071K5L
 |  | R23 | 4.7k | Device:R | Resistor_SMD:R_0201_0603Metric | ~ |  | ‎Yageo‎ | RC0201FR-074K7L
 |  | R24 | 3.57k | Device:R | Resistor_SMD:R_0201_0603Metric | ~ |  | ‎Yageo‎ | RC0201FR-073K57L
 |  | R25 | 100k | Device:R | Resistor_SMD:R_0201_0603Metric | ~ |  | ‎Yageo‎ | RC0201FR-07100KL
 |  | R26 | 10k | Device:R | Resistor_SMD:R_0201_0603Metric | ~ |  | ‎Yageo‎ | RC0201FR-0710KL
 |  | R27 | 4.7k | Device:R | Resistor_SMD:R_0201_0603Metric | ~ |  | ‎Yageo‎ | RC0201FR-074K7L
 |  | R28 | 10k | Device:R | Resistor_SMD:R_0201_0603Metric | ~ |  | ‎Yageo‎ | RC0201FR-0710KL
 |  | R29 | 20R | Device:R | Resistor_SMD:R_0201_0603Metric | ~ |  | ‎Yageo‎ | RC0201FR-0720RL
 |  | R30 | 4.7k | Device:R | Resistor_SMD:R_0201_0603Metric | ~ |  | ‎Yageo‎ | RC0201FR-074K7L
 |  | R31 | 1.5k | Device:R | Resistor_SMD:R_0201_0603Metric | ~ |  | ‎Yageo‎ | RC0201FR-071K5L
 |  | R32 | 10k | Device:R | Resistor_SMD:R_0201_0603Metric | ~ |  | ‎Yageo‎ | RC0201FR-0710KL
 |  | R33 | 10k | Device:R | Resistor_SMD:R_0201_0603Metric | ~ |  | ‎Yageo‎ | RC0201FR-0710KL
 |  | RN1 | 50R | Device:R_Pack04 | Resistor_SMD:R_Array_Convex_4x0402 | ~ |  | Stackpole Electronics Inc | RAVF104DJT51R0
 |  | RN2 | 50R | Device:R_Pack04 | Resistor_SMD:R_Array_Convex_4x0402 | ~ |  | Stackpole Electronics Inc | RAVF104DJT51R0
 |  | RN3 | 50R | Device:R_Pack04 | Resistor_SMD:R_Array_Convex_4x0402 | ~ |  | Stackpole Electronics Inc | RAVF104DJT51R0
 |  | RN4 | 50R | Device:R_Pack04 | Resistor_SMD:R_Array_Convex_4x0402 | ~ |  | Stackpole Electronics Inc | RAVF104DJT51R0
 |  | RN5 | 50R | Device:R_Pack04 | Resistor_SMD:R_Array_Convex_4x0402 | ~ |  | Stackpole Electronics Inc | RAVF104DJT51R0
 |  | RN6 | 50R | Device:R_Pack04 | Resistor_SMD:R_Array_Convex_4x0402 | ~ |  | Stackpole Electronics Inc | RAVF104DJT51R0
 |  | RN7 | 10K | Device:R_Pack04 | Resistor_SMD:R_Array_Convex_4x0402 | ~ |  | Stackpole Electronics Inc | RAVF104DJT10K0
 |  | RN8 | 50R | Device:R_Pack04 | Resistor_SMD:R_Array_Convex_4x0402 | ~ |  | Stackpole Electronics Inc | RAVF104DJT51R0
 |  | RN9 | 10K | Device:R_Pack04 | Resistor_SMD:R_Array_Convex_4x0402 | ~ |  | Stackpole Electronics Inc | RAVF104DJT10K0
 |  | RN10 | 50R | Device:R_Pack04 | Resistor_SMD:R_Array_Convex_4x0402 | ~ |  | Stackpole Electronics Inc | RAVF104DJT51R0
 |  | SW1 | SW_Push | Switch:SW_Push | gkl_misc:PTS_810_SMT_Switch | ~ |  | C&K | PTS810 SJM 250 SMTR LFS
 |  | U1 | FAN53541 | gkl_pmic:FAN53541 | Package_CSP:WLCSP-20_1.934x2.434mm_Layout4x5_P0.4mm |  |  | ON Semiconductor | FAN53541UCX
 |  | U2 | FAN53541 | gkl_pmic:FAN53541 | Package_CSP:WLCSP-20_1.934x2.434mm_Layout4x5_P0.4mm |  |  | ON Semiconductor | FAN53541UCX
 |  | U3 | LFE5U-25F-8MG285C | gkl_lattice:ECP5U25-MG285 | gkl_housings_bga:csBGA285 |  |  | Lattice Semiconductor Corporation | LFE5U-25F-8MG285C | LFE5UM-25F-6MG285C-ND
 |  | U4 | MT41K64M16TW-107_J-TR | gkl_mem:MT41K64M16TW-107_J-TR | Package_BGA:BGA-96_9.0x13.0mm_Layout2x3x16_P0.8mm |  |  | Micron Technology Inc. | MT41K64M16TW-107:J TR
 |  | U5 | BQ24232 | gkl_pmic:BQ24230 | Package_DFN_QFN:QFN-16-1EP_3x3mm_P0.5mm_EP1.75x1.75mm |  |  | Texas Instruments | BQ24232RGTR
 |  | U6 | W25Q128JVP | gkl_mem:AT25SF081 | Package_SON:WSON-8-1EP_6x5mm_P1.27mm_EP3.4x4mm |  |  | Winbond Electronics- | W25Q128JVPIQ TR
 |  | U7 | FAN53541 | gkl_pmic:FAN53541 | Package_CSP:WLCSP-20_1.934x2.434mm_Layout4x5_P0.4mm |  |  | ON Semiconductor | FAN53541UCX
 |  | U8 | TPS51206 | gkl_pmic:TPS51206 | gkl_housings_dfn:WSON-10-1EP_2x2mm_P0.4mm |  |  | Texas Instruments | TPS51206DSQR
 |  | U9 | 74HC4067BQ | 74xx:CD74HC4067M | Package_DFN_QFN:Texas_RGY_R-PVQFN-N24_EP2.05x3.1mm | http://www.ti.com/lit/ds/symlink/cd74hc4067.pdf |  | Nexperia USA Inc. | 74HC4067BQ\,118
 |  | U10 | NCP115-2.5 | gkl_pmic:NCP167 | Package_SON:Texas_X2SON-4_1x1mm_P0.65mm | http://www.onsemi.com/pub/Collateral/NCP167-D.PDF |  | ON Semiconductor | NCP115CMX250TCG
Collated Components:
Item | Qty | Reference(s) | Value | LibPart | Footprint | Datasheet | Info | Mfg | PN | SN-DK
1 | 25 | C1, C2, C5, C14, C19, C25, C27, C38, C40, C42, C44, C45, C48, C49, C52, C53, C56, C58, C60, C62, C63, C66, C67, C74, C76 | 10nF | Device:C | Capacitor_SMD:C_0201_0603Metric | ~ |  | Samsung Electro-Mechanics | CL03B103KP3NNNC
2 | 1 | C3 | 10uF | Device:C | Capacitor_SMD:C_0603_1608Metric | ~ |  | Taiyo Yuden | LMK107BBJ106MALT
3 | 26 | C4, C9, C20, C26, C28, C30, C31, C32, C33, C39, C41, C43, C50, C51, C54, C55, C57, C59, C61, C64, C65, C68, C69, C70, C71, C75 | 100nF | Device:C | Capacitor_SMD:C_0201_0603Metric | ~ |  | Samsung Electro-Mechanics | CL03A104KQ3NNNC
4 | 9 | C6, C7, C8, C11, C15, C16, C17, C18, C29 | 10uF | Device:C | Capacitor_SMD:C_0402_1005Metric | ~ | 6.3V, X5R | Murata Electronics North America | GRM155R60J106ME15D
5 | 1 | C10 | 0.22uF | Device:C | Capacitor_SMD:C_0201_0603Metric | ~ |  | Samsung Electro-Mechanics | CL03A224MQ3NNNC
6 | 5 | C12, C13, C46, C47, C77 | 4.7uF | Device:C | Capacitor_SMD:C_0402_1005Metric | ~ | 10V, X5R | Murata Electronics North America | GRM155R61A475MEAAD
7 | 6 | C21, C22, C34, C35, C36, C37 | 1uF | Device:C | Capacitor_SMD:C_0402_1005Metric | ~ |  | Taiyo Yuden | JMK105C6105KV-F
8 | 2 | C23, C24 | 22uF | Device:C | Capacitor_SMD:C_0603_1608Metric | ~ |  | Murata Electronics North America | GRM188R60J226MEA0D
9 | 2 | D1, D2 | LED_ARGB | Device:LED_ARGB | gkl_led:0404LED_RGB | ~ |  | ‎Wurth Electronics Inc.‎ | 150044M155260
10 | 1 | FB1 | 600R | Device:Ferrite_Bead_Small | Inductor_SMD:L_0402_1005Metric | ~ |  | Murata Electronics North America | BLM15AG601SN1D
11 | 2 | FB2, FB3 | 600R | Device:L_Small | Inductor_SMD:L_0402_1005Metric | ~ |  | Murata Electronics North America | BLM15AG601SN1D
12 | 6 | FID1, FID2, FID3, FID4, FID5, FID6 | Fiducial | Mechanical:Fiducial | Fiducial:Fiducial_0.75mm_Mask1.5mm | ~
13 | 2 | H1, H2 | MountingHole | Mechanical:MountingHole | MountingHole:MountingHole_2.2mm_M2_Pad | ~
14 | 2 | H3, H4 | MountingHole | Mechanical:MountingHole | MountingHole:MountingHole_2.1mm | ~
15 | 1 | J1 | Conn_01x12_Male | Connector:Conn_01x12_Male | gkl_conn:Feather_PinHeader_1x12 | ~
16 | 1 | J2 | Conn_01x16_Male | Connector:Conn_01x16_Male | gkl_conn:Feather_PinHeader_1x16 | ~
17 | 1 | J3 | USB_B_Micro | Connector:USB_B_Micro | Connector_USB:USB_Micro-B_Molex-105017-0001 | ~ |  | Molex | 1050170001
18 | 1 | J4 | MicroSd | Connector_Generic_MountingPin:Conn_01x09_MountingPin | gkl_conn:molex_microsd_1040310811 | ~ |  | Molex | 1040310811
19 | 1 | J5 | JST | Connector_Generic_MountingPin:Conn_01x02_MountingPin | gkl_conn:JST_PH_B2B-PH-SM4-TB_1x02-1MP_P2.00mm_Vertical | ~ |  | JST Sales America Inc. | S2B-PH-SM4-TB(LF)(SN)
20 | 1 | J6 | JTAG | Connector_Generic:Conn_02x05_Odd_Even | gkl_conn:FTSH-105-XX-X-DV | ~ |  | Samtec Inc. | FTSH-105-01-F-DV-K-TR
21 | 3 | L1, L2, L3 | 0.47uH | Device:L_Small | Inductor_SMD:L_0805_2012Metric | ~ |  | Samsung Electro-Mechanics | CIGT201210UHR47MNE
22 | 1 | OSC1 | KC2520B48.0000C10E00 | gkl_time:TYETBCSANF-32.000000 | gkl_time:Oscilator_2.5x2.0 |  |  | Kyocera International Inc. Electronic Components | KC2520B48.0000C10E00
23 | 7 | R1, R5, R13, R14, R17, R18, R25 | 100k | Device:R | Resistor_SMD:R_0201_0603Metric | ~ |  | ‎Yageo‎ | RC0201FR-07100KL
24 | 1 | R2 | 31.6k | Device:R | Resistor_SMD:R_0201_0603Metric | ~ |  | ‎Yageo‎ | RC0201FR-0731K6L
25 | 2 | R3, R6 | 50R | Device:R | Resistor_SMD:R_0201_0603Metric | ~ |  | ‎Yageo‎ | RC0201FR-0750RL
26 | 5 | R4, R8, R23, R27, R30 | 4.7k | Device:R | Resistor_SMD:R_0201_0603Metric | ~ |  | ‎Yageo‎ | RC0201FR-074K7L
27 | 5 | R7, R26, R28, R32, R33 | 10k | Device:R | Resistor_SMD:R_0201_0603Metric | ~ |  | ‎Yageo‎ | RC0201FR-0710KL
28 | 2 | R9, R24 | 3.57k | Device:R | Resistor_SMD:R_0201_0603Metric | ~ |  | ‎Yageo‎ | RC0201FR-073K57L
29 | 1 | R10 | 56.2k | Device:R | Resistor_SMD:R_0201_0603Metric | ~ |  | ‎Yageo‎ | RC0201FR-0756K2L
30 | 1 | R11 | 3.06k | Device:R | Resistor_SMD:R_0201_0603Metric | ~ |  | ‎Yageo‎ | RC0201FR-073K09L
31 | 1 | R12 | 4.32k | Device:R | Resistor_SMD:R_0201_0603Metric | ~ |  | ‎Yageo‎ | RC0201FR-074K32L
32 | 1 | R15 | 267k | Device:R | Resistor_SMD:R_0201_0603Metric | ~ |  | ‎Yageo‎ | RC0201FR-07267KL
33 | 1 | R16 | 147k | Device:R | Resistor_SMD:R_0201_0603Metric | ~ |  | ‎Yageo‎ | RC0201FR-07147KL
34 | 1 | R19 | 240R | Device:R | Resistor_SMD:R_0402_1005Metric | ~ |  | ‎Yageo‎ | RC0402FR-07240RL
35 | 3 | R20, R22, R31 | 1.5k | Device:R | Resistor_SMD:R_0201_0603Metric | ~ |  | ‎Yageo‎ | RC0201FR-071K5L
36 | 2 | R21, R29 | 20R | Device:R | Resistor_SMD:R_0201_0603Metric | ~ |  | ‎Yageo‎ | RC0201FR-0720RL
37 | 8 | RN1, RN2, RN3, RN4, RN5, RN6, RN8, RN10 | 50R | Device:R_Pack04 | Resistor_SMD:R_Array_Convex_4x0402 | ~ |  | Stackpole Electronics Inc | RAVF104DJT51R0
38 | 2 | RN7, RN9 | 10K | Device:R_Pack04 | Resistor_SMD:R_Array_Convex_4x0402 | ~ |  | Stackpole Electronics Inc | RAVF104DJT10K0
39 | 1 | SW1 | SW_Push | Switch:SW_Push | gkl_misc:PTS_810_SMT_Switch | ~ |  | C&K | PTS810 SJM 250 SMTR LFS
40 | 3 | U1, U2, U7 | FAN53541 | gkl_pmic:FAN53541 | Package_CSP:WLCSP-20_1.934x2.434mm_Layout4x5_P0.4mm |  |  | ON Semiconductor | FAN53541UCX
41 | 1 | U3 | LFE5U-25F-8MG285C | gkl_lattice:ECP5U25-MG285 | gkl_housings_bga:csBGA285 |  |  | Lattice Semiconductor Corporation | LFE5U-25F-8MG285C | LFE5UM-25F-6MG285C-ND
42 | 1 | U4 | MT41K64M16TW-107_J-TR | gkl_mem:MT41K64M16TW-107_J-TR | Package_BGA:BGA-96_9.0x13.0mm_Layout2x3x16_P0.8mm |  |  | Micron Technology Inc. | MT41K64M16TW-107:J TR
43 | 1 | U5 | BQ24232 | gkl_pmic:BQ24230 | Package_DFN_QFN:QFN-16-1EP_3x3mm_P0.5mm_EP1.75x1.75mm |  |  | Texas Instruments | BQ24232RGTR
44 | 1 | U6 | W25Q128JVP | gkl_mem:AT25SF081 | Package_SON:WSON-8-1EP_6x5mm_P1.27mm_EP3.4x4mm |  |  | Winbond Electronics- | W25Q128JVPIQ TR
45 | 1 | U8 | TPS51206 | gkl_pmic:TPS51206 | gkl_housings_dfn:WSON-10-1EP_2x2mm_P0.4mm |  |  | Texas Instruments | TPS51206DSQR
46 | 1 | U9 | 74HC4067BQ | 74xx:CD74HC4067M | Package_DFN_QFN:Texas_RGY_R-PVQFN-N24_EP2.05x3.1mm | http://www.ti.com/lit/ds/symlink/cd74hc4067.pdf |  | Nexperia USA Inc. | 74HC4067BQ\,118
47 | 1 | U10 | NCP115-2.5 | gkl_pmic:NCP167 | Package_SON:Texas_X2SON-4_1x1mm_P0.65mm | http://www.onsemi.com/pub/Collateral/NCP167-D.PDF |  | ON Semiconductor | NCP115CMX250TCG

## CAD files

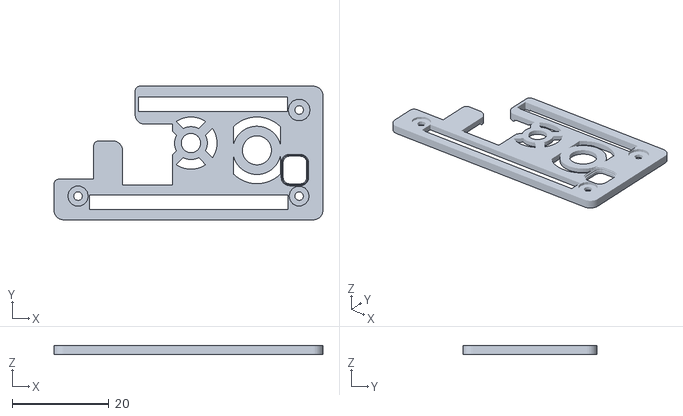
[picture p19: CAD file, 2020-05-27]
enclosure/Orange_Crabe_Case_Top_v4.stl
55.6 x 27.7 x 1.80

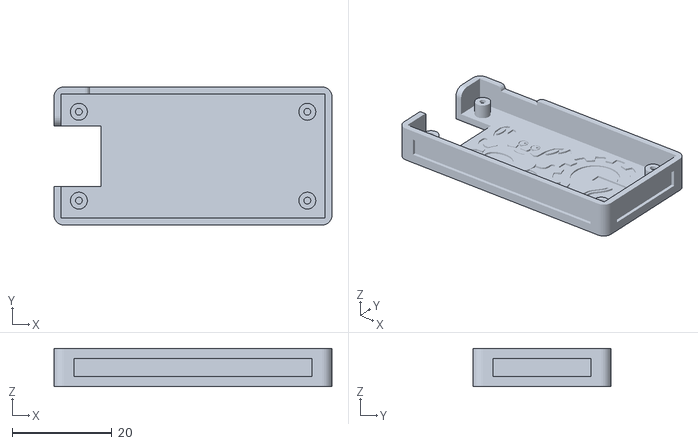
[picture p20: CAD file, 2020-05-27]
enclosure/Orange_Crab_Case_Bottom_v3.stl
55.6 x 27.7 x 7.67

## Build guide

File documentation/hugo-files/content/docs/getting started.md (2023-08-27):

---
title: Getting Started
type: docs
rev: r0.2
---

# Getting Started

First time using an FPGA? This guide should cover everything you need to get the example verilog project built and loaded up on the OrangeCrab.

## Toolchain Setup
---

This guide will make use of the Open Source FPGA toolchain. It is possible to build and install these from scratch, but the whole process takes around 30 minutes, and can be a bit tricky if you're just getting started. 

It's advised to use an automated build from [YosysHQ/oss-cad-suite-build](https://github.com/YosysHQ/oss-cad-suite-build)

The guide will use Ubuntu Linux for a command reference.

---

Grab the [latest](https://github.com/YosysHQ/oss-cad-suite-build/releases/latest) build for your platform, extract them somewhere on your PC, and add the `oss-cad-suite/bin` folder to your path:

```
$ tar -xvf oss-cad-suite-linux-x64-[version].tgz
$ export PATH=$(pwd)/oss-cad-suite/bin:$PATH
```

```
 - MacOS:              export PATH=[path-to-bin]:$PATH
 - Linux:              export PATH=[path-to-bin]:$PATH
 - Windows Powershell: $ENV:PATH = "[path-to-bin];" + $ENV:PATH
 - Windows cmd.exe:    PATH=[path-to-bin];%PATH%
```

Check that they've been correctly installed by running:

```
$ yosys -V
Yosys 0.32+63 (git sha1 de54cf1a0, clang 10.0.0-4ubuntu1 -fPIC -Os)$ nextpnr-ecp5 -V
"nextpnr-ecp5" -- Next Generation Place and Route (Version nextpnr-0.6-46-ge08471df)
```

{{< hint warning >}}
The above steps only set the PATH variable for the current terminal session. Depending on your platform there are options to ensure the tools are kept in your path. 
{{< /hint >}}

---

On linux based systems you may also need to add a udev rule to enable user access to the usb device, once added you'll need to reload the rules or un-plug and reconnect the OrangeCrab for it to take effect
```
$ echo "ATTRS{idVendor}==\"1209\", ATTRS{idProduct}==\"5af0\", MODE=\"0666\", GROUP=\"plugdev\", TAG+=\"uaccess\"" | sudo tee /etc/udev/rules.d/99-orangecrab.rules
$ sudo udevadm trigger
```

You can check the connection and permissions using `dfu-util`

```
$ dfu-util --list
dfu-util 0.11-dev

Copyright 2005-2009 Weston Schmidt, Harald Welte and OpenMoko Inc.
Copyright 2010-2021 Tormod Volden and Stefan Schmidt
This program is Free Software and has ABSOLUTELY NO WARRANTY
Please report bugs to http://sourceforge.net/p/dfu-util/tickets/

Found DFU: [1209:5af0] ver=0101, devnum=53, cfg=1, intf=0, path="1-1", alt=0, name="0x00080000 Bitstream", serial="UNKNOWN"
Found DFU: [1209:5af0] ver=0101, devnum=53, cfg=1, intf=0, path="1-1", alt=1, name="0x00100000 RISC-V Firmware", serial="UNKNOWN"
```

## Build Verilog Example
---
Download the [example](https://github.com/orangecrab-fpga/orangecrab-examples) repository. We'll build the verilog/blink example to test that everything is working.

```
$ git clone https://github.com/orangecrab-fpga/orangecrab-examples
$ cd OrangeCrab-examples/verilog/blink
$ make

    ... snip ...

Info: [ 81336,  81410) |* 
Info: [ 81410,  81484) | 
Info: [ 81484,  81558) | 
Info: [ 81558,  81632) |* 
ecppack --compress --freq 38.8 --input blink_out.config --bit blink.bit
cp blink.bit blink.dfu
dfu-suffix -v 1209 -p 5af0 -a blink.dfu
dfu-suffix (dfu-util) 0.11

Copyright 2011-2012 Stefan Schmidt, 2013-2014 Tormod Volden
This program is Free Software and has ABSOLUTELY NO WARRANTY
Please report bugs to http://sourceforge.net/p/dfu-util/tickets/

Suffix successfully added to file
```

{{< hint info >}}
If you have an OrangeCrab with a ECP5-85F installed then add the DENSITY flag when making

```bash
$ make DENSITY=85F
```
{{< /hint >}}

**🥳 Congratulations you've successfully compiled gateware for the ECP5 on the orangecrab!**

## Upload Verilog Example
---

Next, while holding the button on the OrangeCrab, plug it in. This enters the bootloader and enables you to upload new gateware. 
The LED should be smoothly fading through different colours.

```
$ make dfu
dfu-util -D blink.dfu
dfu-util 0.11

Copyright 2005-2009 Weston Schmidt, Harald Welte and OpenMoko Inc.
Copyright 2010-2016 Tormod Volden and Stefan Schmidt
This program is Free Software and has ABSOLUTELY NO WARRANTY
Please report bugs to http://sourceforge.net/p/dfu-util/tickets/

Match vendor ID from file: 1209
Match product ID from file: 5af0
Opening DFU capable USB device...
ID 1209:5af0
Run-time device DFU version 0101
Claiming USB DFU Interface...
Setting Alternate Setting #0 ...
Determining device status: state = dfuIDLE, status = 0
dfuIDLE, continuing
DFU mode device DFU version 0101
Device returned transfer size 4096
Copying data from PC to DFU device
Download	[=========================] 100%        99314 bytes
Download done.
state(7) = dfuMANIFEST, status(0) = No error condition is present
state(8) = dfuMANIFEST-WAIT-RESET, status(0) = No error condition is present
Done!
```

You should now see the LED blinking through colours!

**🥳 Congratulations you've successfully loaded this gateware onto the ECP5 on the OrangeCrab!**

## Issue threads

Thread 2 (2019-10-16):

Swap Flash footprint

gregdavill, 2019-10-16:
The Flash on r0.1 boards is too small to fit a dual-boot 85F bitstream on without compression. Since compression doesn't give you a guaranteed size it's difficult to say if we can work around this on r0.1

Additionally we are at the maximum Flash density for the package chosen, USON8 2x3, which is 16Mb

By switching the feetprint from USON to WSON or SOIC-8 we can support 128Mb devices, which additionally opens support for devices supporting DDR QSPI, which can be very useful as program space for an SoC.

gregdavill, 2019-12-08:
Complete in the new r0.2 design files.

Closed 2019-12-08.

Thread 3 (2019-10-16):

DDR3 Layout Changes

gregdavill, 2019-10-16:
A design review of the DDR3L layout was performed (Unfortunately after I'd ordered r0.1 prototypes). It identified some points that should be easy to address.

> The pinout of the DDR3 IC schematic symbol is confusing.
One pin represents 9(!) pads in the real package

I want to avoid having hundreds of GND/PWR connections on the schematic, so I'm thinking if we re-name the pins using "KiPart" notation GND [9] to denote 9 physical pins are connected to the 1 schematic pin.

 > The tracerouting is too tight. The space between RAM_A0 and RAM_A3 is only 3.54 mil (see the attachment "tight_tracerouting.png")
The document "TN-46-14: Hardware Tips for Point-to-Point System Design Introduction" suggests space between address traces at least 6 mil.
(Please take a look at the "Trace Width (S3) Design Guidelines" chapter)

To achieve this spacing we can route signals on L1 and L3, which share L2 as a reference ground plane.

> The power delivery network could be optimized. (see the attachment "power_delivery_network.png")
The trace shown in the attachment is to narrow, and could be at least 1.5 times wider.
The same rule could/should be applied to all the power/ground nets on the top layer.

This can be done a new hardware rev.

Additionally adding 3 more address pins means we can support upto 8Gb DDR3L chips, right now due to address routing we only support 1Gb parts.

gregdavill, 2019-10-16:
In summary:

- [ ] Update DDR3L schematic symbol
- [ ] Reroute all DDR3L Signals with 6mil minimum trace spacing. (Okay to use different layers that reference the same plane)
- [ ] Increase all Power and ground traces on the top layer to reduce resistance/inductance.
- [ ] Add 3 more address lines, potentially move control signals to different I/O block to accommodate.

gregdavill, 2019-12-08:
I've done most of these changes on the r0.2 design files.

The 6mil clearance will need to be checked manually, as the traces neck down to 3.5mil clearance at the FPGA end. There might be violations of the clearance in some places, I attempted to swap to 6mil clearance when performing length matching.

gregdavill, 2020-01-28:
All of this has been implemented in r0.2 hardware: https://github.com/gregdavill/OrangeCrab/commit/53f69f118d76b69a3f14699b70452e668943a0a0

Closed 2020-01-28.

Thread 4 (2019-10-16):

ECP5 Reset tests

gregdavill, 2019-10-16:
The ECP5 has two different resets mechanisms.

- Power on Reset
- Device Refresh

Using device refresh we can make use of the ECP5's "multi-boot" feature to load "User gateware" and "Bootloader gateware". We need to investigate if the two different reset mechanisms result in switching between these different gatewares in the same manner.

Ideally I'd like the reset button to reset the User gateware when pressed, and then invoke the Bootloader when held down (2-3s).

If required we can make use of the Microchip ARM processor on board as a "FPGA supervisor".

et-tommythorn, 2019-12-01:
FWIW, I find it too easy to accidentally reset. I have seen lower profile/harder to press switches but I don’t know if they are small enough. Or just make the switch a user button instread.

gregdavill, 2019-12-02:
I wonder if we just make it a user accessible button...

The loaded gateware can determine if it's been held for awhile and trigger a reset.
Worst case power cycling the USB cable while holding it down can force a DFU mode.

gregdavill, 2019-12-08:
r0.2 design now includes this button as a user_button. So it's accessible to the gateware.

It will be used by the bootloader to determine if the bootloader should stay active of the user gateware will run.

Closed 2019-12-08.

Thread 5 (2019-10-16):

User/Charge LED brightness

gregdavill, 2019-10-16:
Brightness for all the LEDs needs to be tuned.

Currently the charge LED is much brighter than the user LED.

gregdavill, 2020-01-28:
Fixed in: https://github.com/gregdavill/OrangeCrab/commit/53f69f118d76b69a3f14699b70452e668943a0a0

Closed 2020-01-28.

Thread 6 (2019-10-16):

Example gateware

gregdavill, 2019-10-16:
To get people up and running quickly some examples should be included.

- [x] Gateware controlled RGB LED pulse/cycle.
- [x] SoC Controlled RGB LED pulse/cycle.
- [x] SoC with DDR3L memory mapped terminal over USB CDC.
- [x] Bootloader

tommythorn, 2019-10-16:
FWIW, my project #0 is the simplest possible "blink LED" (optionally with button controlled speed).
Project #1 is RS232 In/Out example (typically map lower case to upper case and visa versa).

My point being that building on this is easy.  The trivial examples are valuable to pipe clean flow.  I find that most dev kits neglect the simple stuff and rush into very complicated examples with a lot of setup.

I hope to contribute simple examples :)

olofk, 2019-10-16:
I would love to see OrangeCrab in project [LED to Believe](https://github.com/fusesoc/blinky) as well

gregdavill, 2019-10-16:
I agree, but maybe my "basic" example is still to advanced. A simple blink LED is a good idea!

It may be difficult to change the speed with the onboard button, as it designed for reset only...

gregdavill, 2019-10-16:
@olofk I should be able to do that! ^_^

gregdavill, 2020-02-24:
Example projects and code are in a new repo: https://github.com/gregdavill/OrangeCrab-examples

I've already put up a few completely standalone applications for the SoC and pure verilog.

Closed 2021-08-06.

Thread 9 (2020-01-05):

Wrong value for DDR IO regulator in the CSV BOM

smunaut, 2020-01-05:
See:
https://github.com/gregdavill/OrangeCrab/blob/01f993c3d79f494dfd4e837c9e83c070aad83b74/hardware/orangecrab_r0.1/bom/OrangeCrab.csv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

This should be 147k to set the regulator to 1.35v and be consistent with the schematic.

gregdavill, 2020-01-05:
Yes, 147k is the correct value.

On Commit: 215b7bc I changed the schematic and ibom to reflect this, but did not regenerate the csv file.

Running Micron DDR3L parts at 1.5V is possible according to the datasheet, but the timing might be different. In my limited testing I could not get the standard LiteDRAM to work when the DDR3 was running at 1.5V

gregdavill, 2020-01-06:
This has been fixed in 1321707

Also updated some part numbers and swaped to the non-SerDes ECP5.

Closed 2020-01-06.

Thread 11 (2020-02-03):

Better Docs

gregdavill, 2020-02-03:
I've started working on some Docs, but these need to be improved/extended.

https://gregdavill.github.io/OrangeCrab/r0.2/

- [ ] Geting started guide, (tool-chain install to first blinky?)
- [ ] What Next (example projects/ideas)
- [ ] Step-by-Step Guide to installing Linux on the Crab.
- [ ] Get microPython/Circuit python working. (Branch from Fomu port?)

Docs are setup to use Hugo, source files are held in master, but get published to gh-pages branch. Is there a way to have them auto-generate on a new commit to master?

Anything else I'm missing?

gregdavill, 2020-07-10:
Getting Started guide now up: https://gregdavill.github.io/OrangeCrab/r0.2/docs/getting-started/

dramoz, 2021-08-13:
Hi,

@gregdavill the link to  https://gregdavill.github.io is broken.

Regards,
Danilo.

gregdavill, 2021-08-14:
Whoops, this was a byproduct of moving the repo that I'd forgot would happen.

I'm still keen on having all the OrangeCrab repos in their own org, so I've setup a redirect from the old URL to the new one.

shenki, 2021-11-29:
While Greg works on that redirect, here's the current location of the documents:

 https://orangecrab-fpga.github.io/orangecrab-hardware/r0.2/docs/getting-started/

gregdavill, 2021-11-29:
Doh. I did have this fixed. But then I started to move my blog over to my personal github.io page.

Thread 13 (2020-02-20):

Readme has space in 'Orange Crab"

CarlFK, 2020-02-20:
I care because I am writing up promo material.

I'm assuming no space because this has no space:

https://github.com/gregdavill/OrangeCrab/blob/master/documentation/hugo-files/content/r0.1/_index.md

gregdavill, 2020-02-22:
Thanks Carl. Yep that should be changed to not have a space, just to remain consistent.

Everywhere else I've not used a space, and kept it one word.

gregdavill, 2020-03-02:
Fixed in: https://github.com/gregdavill/OrangeCrab/commit/76b73c0cee7ae94dbd78d5746ec94f7d27d54ec4

Closed 2020-03-02.

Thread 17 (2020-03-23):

RISC-V and 128MB memory

salmansheikh, 2020-03-23:
Do you think this board/FPGA could fit a RISC-V and a memory controller to use the 128MB memory?

gregdavill, 2020-03-23:
Yep, that's exactly how I've been using it!

I've been using LiteX (https://github.com/enjoy-digital/litex) + LiteDRAM (https://github.com/enjoy-digital/litedram).
This makes it easy to create a Vexriscv + Memory Mapped DDR3 memory controller + cache.

I'll be publishing an example of how this all works.

salmansheikh, 2020-03-24:
Cool thanks.

salmansheikh, 2020-03-24:
You mention 0.2 going under a short production run soon. Does that mean you will be willing to sell assembled boards? I could make pcbs but soldering those bga and other chips at home is a challenge to say the least.

gregdavill, 2020-03-24:
Ahh, yes.

You can now join a groupbuy for boards here: https://groupgets.com/campaigns/710-orangecrab
The boards will be fully assembled by a assembly house in the US.

salmansheikh, 2020-03-25:
That's a little pricey..

On Tue, Mar 24, 2020 at 7:09 PM Gregory Davill <notifications@github.com>
wrote:

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

--
Even a Smile is charity :)
- Prophet Muhammad

Closed 2020-03-24.

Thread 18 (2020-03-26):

USB-C instead of micro USB

jmi2k, 2020-03-26:
**Pros:**

* It's the new standard, and as time passes, Type C cables will be more common than micro USB
* It has better mechanical properties than micro USB
* Reversible!

**Cons:**

* It can confuse users, as the board is wired to make use of at most USB 1.1 (even High Speed is not possible according to the docs). Although not related, people usually assume Type-C => USB 3.0.
* microUSB cables are cheaper (though that might change).

Feather format allows for Type-C connectors to be used instead of micro USB, so it would remain Feather-compatible.

rowanG077, 2020-03-26:
USB 3.0 is possible using the ECP5-5G variant.

gregdavill, 2020-03-26:
It's a good idea. Swapping in a USB2.0 only USBC connector would be a quite easy change, and not effect any other hardware one the board.

While USB3.0 is technically possible with the SERDES that the ECP5/ECP5-5G has (3.2Gbits/5Gbits) I've not seen this working yet. So I'm hesitant to rush to put that in a r0.3 hardware version.
That said @enjoy-digital is making good progress on that front here: https://github.com/enjoy-digital/usb3_pipe

Routing SERDES into the USB3 lines does not automatically guarantee we can operate in alternate modes (DisplayPort/HDMI) that's another can of worms using the USB billboard system, and might mean we need to include a dedicated USBC PD controller.

jmi2k, 2020-03-26:
I was more concerned about the connector itself more than the protocol. It's awesome to see that you like the idea of putting an Type-C connector while keeping the underlying USB 2.0 system, and I would love to receive my board with it.

About the protocol, I prefer a simple and clean board design (as there are alternative boards which already offer more capabilities, including USB 3.0). In fact, I was astonished when I saw the schematics because there is little hidden: it's a FPGA attached to some DRAM and little else. It's a really understandable system. However I can understand the appeal of a full-featured USB-C connector...

gregdavill, 2020-03-26:
I am open to changing it. Unfortunately, at-least at the time of writing this, we already have the design locked in for the group-buy. So it's not possible to alter those designs as they're already in the pipeline.

So this change would likely come on a r0.3 board release.

jmi2k, 2020-03-26:
It's fine, I hope there is a group-buy for r0.3 too

gregdavill, 2020-09-21:
Implemented in r0.2.1: https://github.com/gregdavill/OrangeCrab/issues/25

ddiss, 2024-09-01:
> While USB3.0 is technically possible with the SERDES that the ECP5/ECP5-5G has (3.2Gbits/5Gbits) I've not seen this working yet. So I'm hesitant to rush to put that in a r0.3 hardware version. That said @enjoy-digital is making good progress on that front here: https://github.com/enjoy-digital/usb3_pipe

Not sure whether this is still of interest, but @ktemkin proposed an alternative USB3 LFPS implementation using the ECP5 SerDes:
https://lab.ktemkin.com/post/serdes-lfps/

Closed 2020-09-21.

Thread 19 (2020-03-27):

DDR3/board gets hot when running an SoC using LiteDRAM.

gregdavill, 2020-03-27:
@pdp7 has commented on the prototype r0.2 board he's got:

> the crab gets quite hot to the touch when running litex vexriscv... is that expected?

I've noticed this too with my testing, the SDRAM seems to run ~10-20°C above ambient. This can make for a very toasty board, although this shouldn't cause any part failures. I'm curious if this is just normal for DDR3L, or if LiteDRAM is keeping the bus in an active state during times of inactivity.

I will throw a unit under a thermal camera to see exactly where the heat is coming from, I suspect the DDR3/ECP5 I/O drivers, the memory has On-Device-Termination. Which pulls the DQ pins to VDD/2 via ~60Ohms. And also all the Address and Control lines have 50Ohm termination to VDD/2. I suspect this is what's heating up.

Lots of devices make use DDR memory, and they're not burning hot while idle, so maybe there is a way we can tri-state the bus while idle in LiteDRAM to avoid this power wastage/heat.

benvanik, 2020-05-27:
Reading FPGA-TN-02032 section 4.11.9 it looks like the termination pull-up is dynamically disabled when a particular I/O is acting as a receiver and tri-stated:
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

In theory then if the LiteDRAM controller can set the bus to tri-state things should get better.

gregdavill, 2020-05-28:
Adding this here because it is related.

On @benvanik's suggestion I took the Vtt resistors off, and replaced the Vref LDO with a resistor divider. Everything still works and timing looks identical. I'll want to do actual SI measurements on the hardware samples before any new hardware changes are locked in for the next revision.

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

I'm still interested in finding out if there is any gateware changes that can aid with reducing power.

gregdavill, 2020-07-19:
I've done some current measurements.

A stock OrangeCrab board running a 48MHz VexRiscv takes around 300mA at the USB connection (1.5W)
Removing the VTT resistors saves 50mA (1.25W)
Turning off ODT saves another 50mA (1W, When combined with removing VTT resistors)

tommythorn, 2020-07-19:
Impressive drop. Do we know how much of that remaining 1W is consumed by the DRAM itself?

gregdavill, 2020-07-19:
Somewhat strange, if I disable the virtual VCC/GND the current drops by another 60mA. Maybe they're wired up incorrectly...

Which puts us at 140mA, Over half of what we started with.
I'm still not sure what the exact implications of disabling the ODT and virtual power pins.

Micron App notes suggests VTT and ODT can be pretty safely be disabled on systems that only have 1-2 DRAM chips. But I can hook a board upto my scope to look at how the eye is effected by these changes.
Lattice recommends adding the virtual power pins on DQS groups to assist in reducing IO switching noise.

gregdavill, 2020-07-19:
Once ODT is off, I'm pretty sure most of the power draw is the ECP5.

Here is what it looks like under thermal with all my changes so far.
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

The ECP5 here is at about 37C.

gregdavill, 2020-07-19:
In combination to the above steps, setting `DIFFRESISTOR=OFF` on the DQ Strobe and `TERMINATION=OFF` on the DQ groups results in 72mA from the USB. 360mW!!

benvanik, 2020-07-19:
Wow, that's impressive! I'm interested to see what the scope says!

gregdavill, 2020-08-30:
This issues has been resolved with some more investigation: https://github.com/enjoy-digital/litedram/issues/216
LiteDRAM now has an attribute to disable ODT, and we need to assign all the bits in the virtual `vccio` pins.

I'll leave this open until I've fixed the example SoC.

gregdavill, 2020-09-21:
Fixed in:
https://github.com/gregdavill/OrangeCrab-examples/commit/724265e2f07b8e275beb11e865124c5a43d4e126
https://github.com/gregdavill/OrangeCrab-test-sw/commit/712ef2183bd9de65db1b64eaf57bd19eb8191829

tommythorn, 2020-09-22:
If I understand correctly, you got the 360 mW reduction through both HW rework and litedram fixes. Are the litedram changes sufficient by themselves (for a r0.1/r0.2 board) or how much is left on the table?

gregdavill, 2020-09-22:
I think most of the improvements have come from gateware changes.

But I can certainly run a comparison between r01, r0.2, r0.2.1.
r0.2.1 does not have any VTT populated, so loading the same gateware onto these 3 subjects should be a good test.

Closed 2020-09-21.

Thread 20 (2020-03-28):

PWM control of LED in Linux

pdp7, 2020-03-28:
Please tell me if I should create this issue somewhere else.

I remember you controlled the LED with PWM driver in Linux.

Could you share the commands you used?

thanks!

gregdavill, 2020-03-29:
You need to add the `rgb-led` to the board capabilities, on this line: https://github.com/litex-hub/linux-on-litex-vexriscv/blob/master/make.py#L223

Then the 3 PWM drivers should be in the device tree, and accessed using these commands:
https://github.com/litex-hub/linux-on-litex-vexriscv/issues/44#issuecomment-539389442

pdp7, 2020-03-29:
@gregdavill does this mean I will have to load everything over UART?

Or is there a branch with your flash changes that I can use?

I have not been able to get SD card boot to work yet (I've tried different cards but no luck getting past Liftoff).

pdp7, 2020-03-29:
Not sure if this is the right place to post...
but it seems to stale at 0%
```
pdp7@x1:~/dev/enjoy/linux-on-litex-vexriscv$ lxterm --images=images.json /dev/ttyACM0 --speed=1e6 --no-crc
[LXTERM] Starting....

        __   _ __      _  __
       / /  (_) /____ | |/_/
      / /__/ / __/ -_)>  <
     /____/_/\__/\__/_/|_|
   Build your hardware, easily!

 (c) Copyright 2012-2020 Enjoy-Digital
 (c) Copyright 2007-2015 M-Labs

 BIOS built on Mar 30 2020 00:40:08
 BIOS CRC passed (5c9339f0)

 Migen git sha1: --------
 LiteX git sha1: --------

--=============== SoC ==================--
CPU:       VexRiscv @ 48MHz
ROM:       32KB
SRAM:      4KB
L2:        8KB
MAIN-RAM:  131072KB

--========== Initialization ============--
Initializing SDRAM...
SDRAM now under software control
Read leveling:
m0, b0: |11100000| delays: 01+-01
best: m0, b0 delays: 01+-01
m1, b0: |11100000| delays: 01+-01
best: m1, b0 delays: 01+-01
SDRAM now under hardware control
Memtest OK
Memspeed Writes: 82Mbps Reads: 131Mbps

--============== Boot ==================--
Booting from serial...
Press Q or ESC to abort boot completely.
sL5DdSMmkekro
[LXTERM] Received firmware download request from the device.
[LXTERM] Uploading buildroot/Image to 0x40000000 (5082532 bytes)...
|>                    | 0%

```

gregdavill, 2020-04-01:
This branch should work.
https://github.com/gregdavill/linux-on-litex-vexriscv/tree/orangecrab

Right now it's just setup for serial boot, but good to confirm that works first before adding FLASH back in. This should have a PWM enabled RGB led driver available in Linux.

pdp7, 2020-04-02:
@gregdavill thanks, I was able to load images.json with lxterm and boot Linux.

I ran this:
```
root@buildroot:~# cd /sys/class/pwm/pwmchip0
root@buildroot:/sys/devices/platform/soc/f0004000.pwm/pwm/pwmchip0# ls
device     export     npwm       subsystem  uevent     unexport
root@buildroot:/sys/devices/platform/soc/f0004000.pwm/pwm/pwmchip0# echo 0 > exp
ort
root@buildroot:/sys/devices/platform/soc/f0004000.pwm/pwm/pwmchip0# cd pwm0/
root@buildroot:/sys/devices/platform/soc/f0004000.pwm/pwm/pwmchip0/pwm0# ls
capture     duty_cycle  enable      period      polarity    uevent
root@buildroot:/sys/devices/platform/soc/f0004000.pwm/pwm/pwmchip0/pwm0# echo 10
0 > period
root@buildroot:/sys/devices/platform/soc/f0004000.pwm/pwm/pwmchip0/pwm0# echo 50
 > duty_cycle
root@buildroot:/sys/devices/platform/soc/f0004000.pwm/pwm/pwmchip0/pwm0# echo 1
> enable
root@buildroot:/sys/devices/platform/soc/f0004000.pwm/pwm/pwmchip0/pwm0# echo 75
 > duty_cycle
root@buildroot:/sys/devices/platform/soc/f0004000.pwm/pwm/pwmchip0/pwm0# echo 25
 > duty_cycle
root@buildroot:/sys/devices/platform/soc/f0004000.pwm/pwm/pwmchip0/pwm0# echo 0
> enable
root@buildroot:/sys/devices/platform/soc/f0004000.pwm/pwm/pwmchip0/pwm0#
```

but I see no change in the LEDs on board.  I am using a buildroot that I built using the linux-on-litex-vexriscv instructions.  This is the kernel:
```
Linux buildroot 5.0.13 #1 Fri Feb 14 22:37:08 CET 2020 riscv32 GNU/Linux
```
any suggestions?

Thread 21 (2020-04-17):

STL for case?

titanous, 2020-04-17:
Is there an STL for the OrangeCrab case that's listed on GroupGets? If so, can you add it to the repository?

gregdavill, 2020-05-27:
These are now added: 80cbdda

https://github.com/gregdavill/OrangeCrab/tree/master/enclosure

Closed 2020-05-27.

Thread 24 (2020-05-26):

UDQS/LDQS nets are switched on the SDRAM

benvanik, 2020-05-26:
I noticed these two differential signals were swapped in the r0.2 schematic. I've never done a DDR design and was wondering if there was a reason for this or if it snuck in during layout?

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

gregdavill, 2020-05-26:
Yes, they were switched to improve routing, You'll notice that Upper Data (UDM, UDQS) is actually paired with D0-D7 bits on the FPGA end.

Ideally these nets should be renamed, to match what they're actually connected to.

krystian-hebel, 2023-11-16:
DQSs are connected properly (although signal name is wrong), but DMs are not. As a result, when bytes are written one at a time and read back in group of 4 bytes, they are swapped. We discovered this in [this function](https://github.com/Dasharo/neorv32/blob/6e0197ea210247cbffa77e3d9da7f2c56fd36899/sw/bootloader/bootloader.c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), with debug lines added - `recv` is the data from `PRINT_GETC()` and `signature` is what the function returns:

```
Awaiting neorv32_exe.bin...
recv: 0x000000fe
recv: 0x000000ca
recv: 0x00000088
recv: 0x00000047
signature: 0x8847feca

ERR_EXE
```

The problem is somewhat hidden with cache enabled, because all accesses are at least 4 bytes long in that case.

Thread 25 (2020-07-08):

r0.2.1 DFM changes

gregdavill, 2020-07-08:
With the production run of `r0.2` boards complete. I've got some ideas for adjusting the designs to improve the test workflow, and optimise the BOM (With the goal of reducing the total unit cost)

These are ideas slated for `r0.2.1`, There shall be _no_ electrical/pin changes to the FPGA/DDR3.
With my versioning convention any gateware/examples for `r0.2` should work on `r0.2.1`.

To improve the testing procedures:
 - [x] Add larger test-points for USB connection, enabling the tests/programming to occur without plugging USB in.
 - [x] Add test-points for JTAG, so we avoid plugging in the JTAG connection every time.

BOM optimisations:
 - [x] Evaluate swapping DCDC regulators from WLCSP to DFN/SOT (Lower cost, lower assembly cost)
 - [x] Remove JTAG connector in favor of through-hole 0.05"/0.1" footprint (The Samtec 0.05" JTAG connector is quite expensive)
 - [x] Alter RGB LEDs used. (Ensure R,G,B mapping is kept identical)
 - [x] Remove VTT resistors, as they're not required for the scope of this design.
 - [x] Remove DDR VREF LDO, for 1-2 SDRAM chips a simple resistor divider is acceptable.

Other nice changes:
 - [x] USB-C? (Likely making use of a USB 2.0 type-C connector, see #18 )
 - [x] Panelisation changes to avoid any rough tabs left on board edges
 - [x] Castellated edges?

Feel free to add any extra comments or suggestions to this issue.

gregdavill, 2020-09-21:
These boards pass the same self-test that we ran on r0.2 boards! They look great too!

    Note: production boards will be in the standard Orange Colour.
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

Will need to update docs with information about various version numbers to avoid confusion.

gregdavill, 2020-09-22:
Design files are up: https://github.com/gregdavill/OrangeCrab/tree/main/hardware/orangecrab_r0.2.1

Closed 2021-08-06.

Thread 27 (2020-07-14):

SPI flash bootloader protection

DurandA, 2020-07-14:
Hi @gregdavill,

I just got my hands on OrangeCrab and am looking to use the internal SPI flash within a LiteX SoC to store the BIOS + firmware.

I was wondering if the r0.2 as sold by GroupGets has the [W25Q128JVPIQ SPI flash](https://www.winbond.com/resource-files/w25q128jv%20spi%20revc%2011162016.pdf) preconfigured with block/sector lock in order to protect the first 4Mbits of the bootloader.

gregdavill, 2020-07-14:
No, the flash hasn't been locked. That is probably something we should have done, but totally slipped my mind when setting up the production test suite.

When I update the boot-loader. Which we can setup as a .dfu update, I think it will likely unlock/lock those bits. To prevent accidental overwriting of that area.

DurandA, 2020-07-15:
Thanks for the answer. Feel free to close this issue or keep it open until you update the bootloader.

Btw, the board is awesome!

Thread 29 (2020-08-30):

U5 has symbol for bq24232, but BOM/layout for bq24230

gregdavill, 2020-08-30:
These two parts are functionally similar, but not drop in replacements.

The bq24232 has a Termination Disable, TD, pin. On the bq24230 this pin is used for Current Limit ILIM.

The schematic should be updated with the correct part number and correct pin labelling.

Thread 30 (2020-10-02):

r0.2.1: VBATT voltage divider

gregdavill, 2020-10-02:
## Issue
Voltage divider resistors were changed to 100k to reduce static power draw.

But this changes the current into the ADC circuit. Because of this different readings of the battery/charger are observed compared to the r0.2 boards.

## Suggested action
 - [ ] Change R32 and R33 to 10k

Closed 2020-10-06.

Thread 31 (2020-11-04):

rpc-hw-fix: Changes required for testing RPC-DRAM

gregdavill, 2020-11-04:
RPC DRAM from Etron reduces the pin count of DRAM interfaces by offering a serial Address/Cmd interface.

It's available in both a standard 96 ball DDR3 package, and a WLCSP. The current OrangeCrab boards should be capable of supporting the 96-ball package with some hw changes.

There is a small errata with the RPC part:
> The CS# pin (ball D-3, which is UDM for a DDR3) needs a 50 ohm termination resistor located near the dram and the other end connected to VDDQ
> Without the resistor you may get some pretty bad signal integrity / overshoot & undershoot that may possibly cause some problems

## Hardware Changes:
 - Set VDD_DRAM to 1.5V:
   - R32 <= 100k
 - Attach 51R termination between CS# (UDM pin on DDR3) and VDDQ
   - PN: RC0402FR-0751RL

### 51R suggested placement location
Note: flipped board view. (viewed from back of PCB):
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

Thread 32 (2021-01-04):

Missing pullup on PROGRAMN

gregdavill, 2021-01-04:
## Summary
Hardware revision r0.2 didn't have an external resistor on the PROGRAMN pin.
This pin is driven by the FPGA to reset the device into the bootloader.

## Observed Behavior

There has been 2-3 reports of users experiencing the the bootloader not loading their programs. Instead the device just sits with the LED on WHITE. Entering the bootloader can be done at anytime by pressing `btn0`. This behaviour indicates that the device in cycling in/out of the bootloader, since the bootloader only checks the button state once on power-up.

This seems to be related to this pin on some boards the internal resistance isn't strong enough to counteract the weak-pulldown of an I/O pin it's connected to.

## Proposed Fix

### New hardware

 - r0.2.1 features an external pull-up resistor.

### Existing r0.2 hardware

 - In gateware define the I/O pin connected to the `PROGRAMN` pin as a `HIGH` value.

```diff
diff --git a/nmigen/blink.py b/nmigen/blink.py
index a966594..cf1803c 100644
--- a/nmigen/blink.py
+++ b/nmigen/blink.py
@@ -23,6 +23,10 @@ class Blink(Elaboratable):
             blue_led.o.eq(self.count[25]),
         ]

+        # Ensure FPGA PROGRAMN pin is released.
+        program = platform.request('program')
+        m.d.sync += program.o.eq(0)
+
         return m
```
Note: in nMigen the `program` pin defined in the platform file is marked as active low, nMigen internally negates the values we assign to it.

tommythorn, 2021-01-05:
Might make a good addition to the r0.2 Errata (which I'd suggest including in the README.md lest it gets missed)

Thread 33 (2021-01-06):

OrangeCrab r0.2 DDR3 gets hot even if .pcf does not use it

tambewilliam, 2021-01-06:
Please find attached zipped .dfu file.

Below is the content of the .pcf file that was used to build the attached zipped .dfu file.

LOCATE COMP "clk48mhz_i" SITE "A9"; IOBUF PORT "clk" IO_TYPE=LVCMOS33; FREQUENCY PORT "clk48mhz" 48 MHZ;

FREQUENCY NET "clk24mhz" 24 MHZ;
FREQUENCY NET "clk96mhz" 96 MHZ;

LOCATE COMP "usr_btn_n" SITE "J17"; IOBUF PORT "usr_btn_n" IO_TYPE=SSTL135_I;

LOCATE COMP "led_red_n"   SITE "K4"; IOBUF PORT "led_red_n"   IO_TYPE=LVCMOS33;
LOCATE COMP "led_green_n" SITE "M3"; IOBUF PORT "led_green_n" IO_TYPE=LVCMOS33;
LOCATE COMP "led_blue_n"  SITE "J3"; IOBUF PORT "led_blue_n"  IO_TYPE=LVCMOS33;

LOCATE COMP "usb_d_p" SITE "N1"; IOBUF PORT "usb_d_p" IO_TYPE=LVCMOS33;
LOCATE COMP "usb_d_n" SITE "M2"; IOBUF PORT "usb_d_n" IO_TYPE=LVCMOS33;
LOCATE COMP "usb_pullup" SITE "N2"; IOBUF PORT "usb_d_n" IO_TYPE=LVCMOS33;

LOCATE COMP "sdcard_clk" SITE "K1"; IOBUF PORT "sdcard_clk" IO_TYPE=LVCMOS33;
LOCATE COMP "sdcard_di" SITE "K2"; IOBUF PORT "sdcard_di" IO_TYPE=LVCMOS33;
LOCATE COMP "sdcard_do" SITE "J1"; IOBUF PORT "sdcard_do" IO_TYPE=LVCMOS33;
LOCATE COMP "sdcard_dat1" SITE "K3"; IOBUF PORT "sdcard_dat1" IO_TYPE=LVCMOS33;
LOCATE COMP "sdcard_dat2" SITE "L3"; IOBUF PORT "sdcard_dat2" IO_TYPE=LVCMOS33;
LOCATE COMP "sdcard_cs_n" SITE "M1"; IOBUF PORT "sdcard_cs_n" IO_TYPE=LVCMOS33;

[orangecrab02.zip](https://github.com/gregdavill/OrangeCrab/files/5773583/orangecrab02.zip)

gregdavill, 2021-01-22:
I tested this code on some boards here and didn't notice any significant heat from the DDR3.

Maybe a slight 5C increase, but that's likely heat from the FPGA itself spreading into the board.

tambewilliam, 2021-01-23:
Perhaps my board has failed; because the heat is definitely coming from the DDR3 spreading quickly on PCB and can be felt while holding the board by the edges.

Would you be interested in looking at it if I shipped it to you ?

gregdavill, 2021-01-24:
Yeah, I'd be interested to take a look.

Send me an email `greg.davill@gmail.com`
I can ship you a new one.

gregdavill, 2021-03-26:
Just to wrap up this issue, here is a summary

I received the 'failed' board. It appeared that VCC_DRAM was ~2.8V. This should be 1.35V for DDR3L (or 1.5V for DDR3). It's supplied by one of the DCDC regulators.

Upon inspection of the regulator under a microscope a small crack extending through the WLCSP die was observed. This is presumed to be the culprit. of the fault.

A higher VCC_DRAM will not adversely effect the ECP5, as it's IO pins are all rated to 3.3V. However it was stressing the DDR3 part, leading to the DDR3 part becoming hot while powered, even if not being used.

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

Closed 2021-03-26.

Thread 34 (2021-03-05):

Duplicate filled zone

daglem, 2021-03-05:
Not really an issue, but one of the two identical "Zone Outline [GND] on B.Cu" may be removed.

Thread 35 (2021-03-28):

RISC-V with custom gateware

fdarling, 2021-03-28:
Are there any examples of programming an OrangeCrab using the soft RISC-V core, but with custom "gateware" for hardware accelerated peripherals? My goal is to largely program using C/assembly, but to also extend the CPU core using Verilog.

In the RISC-V blinky example, I am confused as to where the RISC-V core actually resides. Is it part of the bootloader, which simply runs the (assembly) program stored in flash rather than reconfiguring the FPGA? Or is there a RISC-V core being pulled into the blinky example that becomes part of "custom" FPGA configuration which then runs the assembly code?

I'd appreciate it if you'd shed some light on this!

tommythorn, 2021-03-29:
You don't say which blinky example (there are many), but assuming it's https://github.com/gregdavill/OrangeCrab-examples/tree/main/riscv/blink then you are right, it's executed by the RISC-V core that's part of the initial FPGA configuration.  However for example https://github.com/gregdavill/OrangeCrab-examples/tree/main/verilog/blink is a standalone logic design that would override the initial design.

If you want to extend the firmware core, then I *think* the sources are in https://github.com/gregdavill/OrangeCrab-test-sw (it's actually not clear as it appears to be a test fixture and I haven't tried it).

boxfire, 2021-09-10:
I started from the bootloader to do this: https://github.com/gregdavill/foboot/tree/OrangeCrab

boxfire, 2021-09-10:
And also: https://github.com/gregdavill/linux-on-litex-vexriscv/tree/orangecrab

francis2tm, 2022-01-17:
Hey @fdarling, I'm exactly in your situation. I pretend to add a custom peripheral into a SoC with a RISC-V core. It seems orangecrab's repos are not centrailized. So far, I've found the CircuitPython SoC (https://github.com/orangecrab-fpga/orangecrab-examples), but it seems that it doesn't have support for common peripherals like SPI, I2C etc. Whereas the SoC from https://github.com/gregdavill/OrangeCrab-test-sw/tree/main/hw looks like it is more complete. However, it is hard to know which one is more complete/updated and if they both run at maximum frequency (which is 48MHz right?) in order to use it as a baseline. Which orangecrab SoC should I start on? @gregdavill  any thoughts?

Thanks in advance

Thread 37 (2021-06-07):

dfu bootloader v3.1 does not exit cleanly

gregdavill, 2021-06-07:
Reported on the 1BitSquared/OrangeCrab discord channel:

## Summary ##
When `dfu-util` completes it throws an error

## Current Behavior ##
```
Copying data from PC to DFU device
Download    [=========================] 100%        99405 bytes
Download done.
DFU state(7) = dfuMANIFEST, status(0) = No error condition is present
dfu-util: unable to read DFU status after completion (LIBUSB_ERROR_NO_DEVICE)
```

## Expected Behavior ##

`dfu-util` should completes without error and exit cleanly

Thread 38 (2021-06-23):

Question: what version is SD interface?

ralphhipps, 2021-06-23:
any plans for 4.0 or 7.0?

gregdavill, 2021-06-23:
The SD interface is implemented in FPGA fabric, so it's not technically limited to a specific version.
However the I/O is rated at 3.3V only, which does limit the speeds at which you can acquire, that basically limits the interface to `HS` 25MHz, and means you can't use the `UHS-I` or higher speeds (Which require switching I/O to 1.8V)

Closed 2021-08-06.

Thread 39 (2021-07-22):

Documentation for r0.2.1

nicolasnoble, 2021-07-22:
I got a pair of boards from https://1bitsquared.com/products/orangecrab and what I received are in fact r0.2.1 boards, which I can't find documentation for. When connecting the boards through USB, they start the default blinking bitstream, but no usb device appears in my kernel logs, even though I'm using a data USB-C cable. I'm not too sure how to proceed without documentation about them to troubleshoot what's going on.

gregdavill, 2021-07-23:
Hey @nicolasnoble, The docs are identical to the r0.2 board, except for a connector change for the USB/JTAG, and some changes to the DC/DC circuits.

If you hold down the button while connecting the USB then the DFU bootloader will appear.

dramoz, 2021-08-14:
@gregdavill I think you should acknowledge this in the [README.md](https://github.com/orangecrab-fpga/orangecrab-hardware/blob/d53c08cea15ff8d6b18bcf5d190d7da70abeee98/README.md) file and the [OrangeCrab Web site](https://orangecrab-fpga.github.io/orangecrab-hardware/) to avoid confusions. I have to figure out the same issue.

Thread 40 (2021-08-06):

r0.2.1: R15,R35 BOM error

gregdavill, 2021-08-06:
There is currently an error in the BOM of the production files for the r0.2.1.
https://github.com/gregdavill/OrangeCrab/blob/main/hardware/orangecrab_r0.2.1/Production/OrangeCrab-bom.csv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

`R15` and `R35` are listed as:

```
R15 R35 | 2 | 120k | gkl_dipol:R_0201_0603Metric | ~ | RC0201FR-07267KL | ‎Yageo‎ | UNI-ROYAL(Uniroyal Elec) | 0201WMF2673TCE |   |   |  
```

Note the value is `120K`, but has part numbers for a `267K` part.

These resistors are used in the DCDC feedback path. The incorrect part placement has the effect of reducing 1.1v and 1.35v rails down to 0.8v and 0.9v respectively.

Closed 2021-08-06.

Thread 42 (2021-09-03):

doc: Specify battery connector voltage

gregdavill, 2021-09-03:
Current info on the README doesn't specify that the battery connector is for 1S LiPo cell.

Closed 2021-09-03.

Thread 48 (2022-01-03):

Problems with 85F

japm48, 2022-01-03:
I am having some issues with the OrangeCrab variant 85F. When I program it I get the following:
```
$ dfu-util -D blink_reset.dfu
Match vendor ID from file: 1209
Match product ID from file: 5af0
dfu-util: More than one DFU capable USB device found! Try `--list' and specify the serial number or disconnect all but one device
```
(Note: using latest `dfu-util` version 0.11, provided by `oss-cad-suite-build`)

This is the corresponding device list:
```
$ dfu-util --list
Found DFU: [1209:5af0] ver=0101, devnum=7, cfg=1, intf=0, path="3-2", alt=1, name="0x00100000 RISC-V Firmware", serial="UNKNOWN"
Found DFU: [1209:5af0] ver=0101, devnum=7, cfg=1, intf=0, path="3-2", alt=0, name="0x00080000 Bitstream", serial="UNKNOWN"
```
If I select the "alternative 0" (`dfu-util -a 0 -D blink_reset.dfu`) everything works fine (modulo the error message in #37).

Litex/nmigen/etc., all assume that there is only one "device" (`1209:5af0`), so I understand this is not intended by design. If so, is this fixed in the last DFU bootloader? I may have received a unit with an outdated version.

Possibly useful: [lsusb output](https://gist.github.com/japm48/301fd54eb6b20712e8c57aa57a85dc58).

Also, apparently, the 25F and 85F bitstreams are incompatible, but `dfu-util` will happily a bitstream, but the FPGA is stuck doing nothing until reset into DFU mode. This is especially frustrating as the toolchains hardcode `25F` in them (I'll probably post some PRs once this is sorted out).
I would suggest using a separate USB PID, but of course, it is already too late and I understand PIDs are a scarce resource; so maybe there is a way to still convince `dfu-util` to refuse to upload it? (maybe `iSerialNumber` or in the `iProduct` string).

gregdavill, 2022-01-05:
This seems like a combination of 2 issues, which I'll cover separately

## Alt interfaces
The Alt interfaces were actually added to newer boot loaders. The idea is that you can load a bitstream to one section of FLASH, and if your bitstream requires firmware or other data then this can be loaded to the second section.
However this creates the issue you've described, where you get an error asking to specify an alt interface.

This should be fixed upstream where required, basically just ensuring that `--alt 0` is passed, which will be backwards compatible with the older bootloaders. I'll take a look over LiteX/Amaranth(nmigen) implementations to fix this.

## 25F / 85F bitstream compatibility
Correct. Bitstreams generated for the 25F will not load onto the 85F, and vise-versa. I'd not considered this when we introduced the 85F OrangeCrabs.

Ideally at a minimum there should be a mechanism to alert the user that a compiled bitstream is not compatible with the board they're trying to load it onto.
There are a few ways to achieve this:
 - Assign a new PID for 85F bootloader
 - Add device type in USB descriptor
 - Add check to the bootlaoder

As you mention adding a new PID has drawbacks. We're using PIDs from pid-codes, so there isn't any extra cost, but I'd like to avoid getting new PIDs if not required.

We can add info about which FPGA is supproted in the USB descriptors, `dfu-util` lets us target alt section by name, not just number. So that might be a solution. But this would require further upstream changes.

Part of the bitstream header contains the device IDCODE, this is checked by the FPGA when it's loading and if it doesn't match the device then an error is generated. We can use this same code, the bootloader can check that the bitstream being downloaded is compatible. If it's not then it can present
```
errTARGET: File is not targeted for use by this device.
```
This should have the effect of showing this or a similar message from dfu-util. Indicating to the user that an error has occurred with the device type.

japm48, 2022-01-05:
Great, thanks for the detailed explanation!

> Part of the bitstream header contains the device IDCODE, this is checked by the FPGA when it's loading and if it doesn't match the device then an error is generated. We can use this same code, the bootloader can check that the bitstream being downloaded is compatible.

Interesting.

----

Just another question: what would you suggest for flashing the bootloader? Apparently `fomu-flash` only works on RPi.

stevecheckoway, 2022-11-29:
For future users reading this issue, in the `Makefile`s for the [orangecrab-examples](https://github.com/orangecrab-fpga/orangecrab-examples), you need to change the `dfu` target to be
```make
dfu: ${PROJ}.dfu
	dfu-util -a 0 -D $<
```
and you need to change the `%_out.config` target to be
```make
%_out.config: %.json
	nextpnr-ecp5 --json $< --textcfg $@ --85k --package CSFBGA285 --lpf ..$(PATH_SEP)orangecrab_${VERSION}.pcf
```

The two changes are adding `-a 0` as an argument to `dfu-util` and changing `--25k` to `--85k` to generate the correct bitstream for the LFE5U-85F.

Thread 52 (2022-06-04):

USB Data signals (USB_D+, USB_D-) are not connected to a pin pair on ECP5

francis2tm, 2022-06-04:
Hey!
I was checking ECP5's [datasheet](https://www.google.com/url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) and on 4.1 Signal Descriptions it says:

> PIO A and B are grouped as a pair, and PIO C and D are group as a pair. Each pair
supports true LVDS differential input buffer. Only PIO A and B pair supports true
LVDS differential output buffer.

I wonder why the USB data signals (differential) are not connected to a pin pair (for instance, to PR44C and PR44D)?

Thanks in advance

gregdavill, 2022-06-04:
Yes you're right differential output buffers are only on PIO A/B pairs. But this doesn't matter, and isn't actually possible for Full-Speed USB signals for two reasons.
 - Against popular belief, Full Speed USB is not always a differential signal. EOP symbol is low on both D+/D-. So even if USB signals were on an A/B pair you would need to use pins in single ended mode.
 - Even without the differential buffer in the PIO, adding an inverter in the FPGA fabric works,but potentially adds some skew to the signals. This would only be an issue with signals in the 200-400Mbit/s range. USB FS being 12Mbit/s this works perfectly.

Here is a photo of the low level USB signalling which shows these EOP.
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

francis2tm, 2022-06-04:
Makes sense! Thanks for the clarification

Closed 2022-06-04.

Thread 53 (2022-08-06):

LiteDRAM's ECP5 IOs

francis2tm, 2022-08-06:
Hello,
I was checking your FPGA-DDR connections and it raised me 2 questions:

1. I can see that there're multiple pads that are used by LiteDRAM as "VCCIO", these pins are connected to P1.35V. The same happens to 2 GND pads. What's really the purpose of these pins? Why are these VCCIO pins connected to K16 D17 K15 K17 B18 C6 specifically? Could the VCCIO (and the GND pins) be connected to other pads of the FPGA?
2. Besides all the differential pairs that need to be connected to a "A" and "B" or a "C" and "D" pins of the FPGA, is there any constraint to consider when choosing which pads of the FPGA will be attributed to each DDR signal?
Thanks in advance!

gregdavill, 2022-08-07:
Lattice recommends assigning spare I/Os in each bank to "Virtual I/O power". Basically configuring an I/O as an output, and tying it to 1.35V results in an additional BGA ball used to power the other switching I/Os on that bank, same is true for GND. I never ran any simulations based on the speed of the LiteDRAM controller to determine if these pins actually are required for a functional design.

Yes. Checkout Lattices app notes for DDR interfaces with the ECP5. There are a few constrains around the DQS groups, the strobes are on fixed pins, and only a handful of I/O around them can be paired with that strobe. Address/Command signals don't have any restrictions.

francis2tm, 2022-08-09:
Thanks for the useful pointers!

Closed 2022-08-09.

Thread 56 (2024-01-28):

Error compiling Verilog examples with Yosys 0.37 on Mac OS

frantic0, 2024-01-28:
Hello,

I have been trying to compile and upload with the latest [Yosys 0.37+34 oss-cad-suite-darwin-x64-20240127.tgz](https://github.com/YosysHQ/oss-cad-suite-build/releases/download/2024-01-27/oss-cad-suite-darwin-x64-20240127.tgz) on Mac OS Sonoma 14.2

I can successfully compile and upload the blink verilog examples but not the pll, pwm_rainbow, usb_acm_device examples, which are of interest.

I am adding the result of the make on pll. Any ideas of what is not working?

Thank you

```
$ make
ecppll -i 48 -o 100 -f pll.v
Pll parameters:
Refclk divisor: 12
Feedback divisor: 25
clkout0 divisor: 6
clkout0 frequency: 100 MHz
VCO frequency: 600
yosys -s "plltest.ys"

 /----------------------------------------------------------------------------\
 |                                                                            |
 |  yosys -- Yosys Open SYnthesis Suite                                       |
 |                                                                            |
 |  Copyright (C) 2012 - 2020  Claire Xenia Wolf <claire@yosyshq.com>         |
 |                                                                            |
 |  Permission to use, copy, modify, and/or distribute this software for any  |
 |  purpose with or without fee is hereby granted, provided that the above    |
 |  copyright notice and this permission notice appear in all copies.         |
 |                                                                            |
 |  THE SOFTWARE IS PROVIDED "AS IS" AND THE AUTHOR DISCLAIMS ALL WARRANTIES  |
 |  WITH REGARD TO THIS SOFTWARE INCLUDING ALL IMPLIED WARRANTIES OF          |
 |  MERCHANTABILITY AND FITNESS. IN NO EVENT SHALL THE AUTHOR BE LIABLE FOR   |
 |  ANY SPECIAL, DIRECT, INDIRECT, OR CONSEQUENTIAL DAMAGES OR ANY DAMAGES    |
 |  WHATSOEVER RESULTING FROM LOSS OF USE, DATA OR PROFITS, WHETHER IN AN     |
 |  ACTION OF CONTRACT, NEGLIGENCE OR OTHER TORTIOUS ACTION, ARISING OUT OF   |
 |  OR IN CONNECTION WITH THE USE OR PERFORMANCE OF THIS SOFTWARE.            |
 |                                                                            |
 \----------------------------------------------------------------------------/

 Yosys 0.37+34 (git sha1 80511ced7, x86_64-apple-darwin21.4-clang++ 14.0.0-1ubuntu1.1 -fPIC -Os)

-- Executing script file `plltest.ys' --
ERROR: Can't open script file `plltest.ys' for reading: No such file or directory
make: *** [plltest.json] Error 1
```

`

jrsa, 2024-04-28:
install gnu make with `brew install make` and then build using `gmake` instead of `make`

frantic0, 2024-04-28:
Thank you @jrsa

not sure why, but the makefile entry for generating the .ys files wasn't working for me.

I was able to build it with `make` by changing the makefile and replacing the following
```
%.ys: $(VERILOG_FILES)
 	$(file >$@)
 	$(foreach V,$(VERILOG_FILES),$(file >>$@,read_verilog $V))
 	$(file >>$@,synth_ecp5 -top $(TOP_MODULE)) \
 	$(file >>$@,write_json "$(basename $@).json") \
```
with this
```
%.ys: $(VERILOG_FILES)
	@echo "Generating Yosys script $@"
	@echo "read_verilog $(VERILOG_FILES)" > $@
	@echo "synth_ecp5 -top $(TOP_MODULE)" >> $@
	@echo "write_json $(basename $@).json" >> $@
```

jrsa, 2024-04-28:
it's most likely because something in the original makefile is only supported by GNU make, and not by BSD make which is what ships with OS X

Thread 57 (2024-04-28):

Restoration of DFU bootloader

jrsa, 2024-04-28:
I made the regrettable mistake of overwriting the DFU bootloader by leaving out the "offset" parameter when invoking `dfu-util` and I am trying to restore it via JTAG with an FT2232H breakout board, and the `ecpprog` tool. I have the 25F variant, revision 0.2.1.

I tried flashing the bootloader bitstream from [here](https://github.com/gregdavill/foboot/releases/tag/v3.0) and get the following output:
```
ecpprog -I B  foboot-v3.0-orangecrab-r0.2-25F.bit  -a
init..
IDCODE: 0x41111043 (LFE5U-25)
ECP5 Status Register: 0x00200100
reset..
flash ID: 0xEF 0x40 0x18
file size: 266307
erase 64kB sector at 0x000000..
erase 64kB sector at 0x010000..
erase 64kB sector at 0x020000..
erase 64kB sector at 0x030000..
erase 64kB sector at 0x040000..
programming..  266307/266307
verify..       266307/266307  VERIFY OK
rebooting ECP5...
Bye.
```
That seems... good. However after the device resets there is a red breathing pattern on the RGB LED and no DFU device shows up. I am assuming the red LED indicates an error with the bootloader. The result is the same whether I plug in the device with the button pressed or not. I am successfully able to load the blink example in this manner so I think my process for uploading a bitstream to flash is OK. My only other idea is that I am using the wrong bitstream for the hardware I have, but I don't see any on github that might be a closer match.

jrsa, 2024-04-29:
I also tried this bitstream with the same result
[https://github.com/orangecrab-fpga/production-test-sw/blob/main/prebuilt/foboot-v3.1-orangecrab-r0.2-25F.bit](https://github.com/orangecrab-fpga/production-test-sw/blob/main/prebuilt/foboot-v3.1-orangecrab-r0.2-25F.bit)

gregdavill, 2024-05-07:
That should be all that's needed to load the bootloader via JTAG.

Are you holding the button when connecting USB? That's needed to "stay" in the bootloader, otherwise it tries to run the user application.

jrsa, 2024-05-12:
yes @gregdavill I am pressing `btn0` and then inserting the USB-C. The RGB LED blinks red immediately after the cable is inserted. I looked through what I believe to be the bootloader source [here](https://github.com/gregdavill/foboot/blob/4f24c432a84b1f2ddadfc2001b087afb6176b0dc/sw/src/main.c#L49) to see why the red blinking occurs (I am assuming that I see the results of `rgb_mode_error`)
I see several calls once inside the dfu handling code, but I am assuming that is not getting reached because it never enumerates on USB. I believe USB is physically working because I am able to load and run the CDC ACM verilog example. The line I linked above is the only other `rgb_mode_error` which seems to indicate failing to reboot to the CPU (the LED state is set right before doing so). Is it possible the firmware is trying to reboot from flash memory, and failing, because I haven't written any firmware to flash? Not entirely sure how this is supposed to work, but I was expecting if this bitstream was loaded, that would be enough to do DFU bitstream uploading.

CCampbell71, 2024-12-14:
@jrsa did you figure this out? I'm planning on building a board from scratch and want to ensure i can get the bootloader functioning

jrsa, 2024-12-14:
@CCampbell71 I gave up since I have other ECP5 dev boards, but I'm guessing I bricked mine somehow while trying to fix this issue (which of course originated with _my_ mistake) Good luck with the build!

CCampbell71, 2024-12-15:
@jrsa oh no! @gregdavill on a freshly assembled board, I should be able to flash the bootloader via JTAG? The prebuilt one in your repo?

gregdavill, 2024-12-15:
It should be all that is needed. That is what's loaded onto the boards during their assembly QC. The JTAG interface is part of the FPGA and is always available to load gateware,

The bootloader project should still run and compile too, if you needed to change the behaviour around the btn0 input.

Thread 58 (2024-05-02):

Can't open 0.2.1 schematics in KiCad

wyager, 2024-05-02:
On trying to open the 0.2.1 schematics, I get `The project symbol library cache file 'OrangeCrab-cache. lib' was not found.`. Opening the schematic anyway results in broken symbols. 0.2 schematic works with no issues, besides a few things related to upgrading to a new kicad version.

Closed 2024-05-07.

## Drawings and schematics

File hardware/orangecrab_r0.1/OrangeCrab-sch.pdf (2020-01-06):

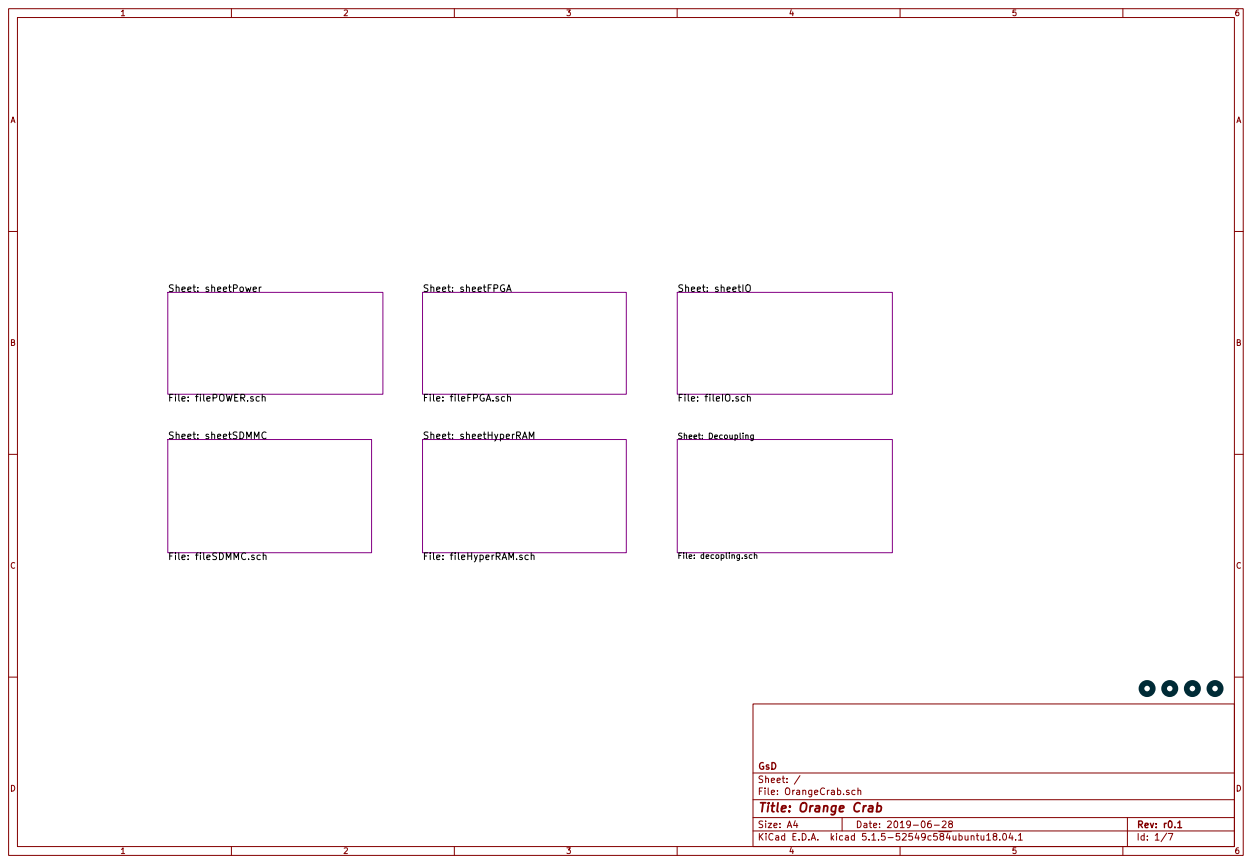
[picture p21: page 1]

File: OrangeCrab.sch Sheet: / GsD

Id: 1/7 Title: Orange Crab

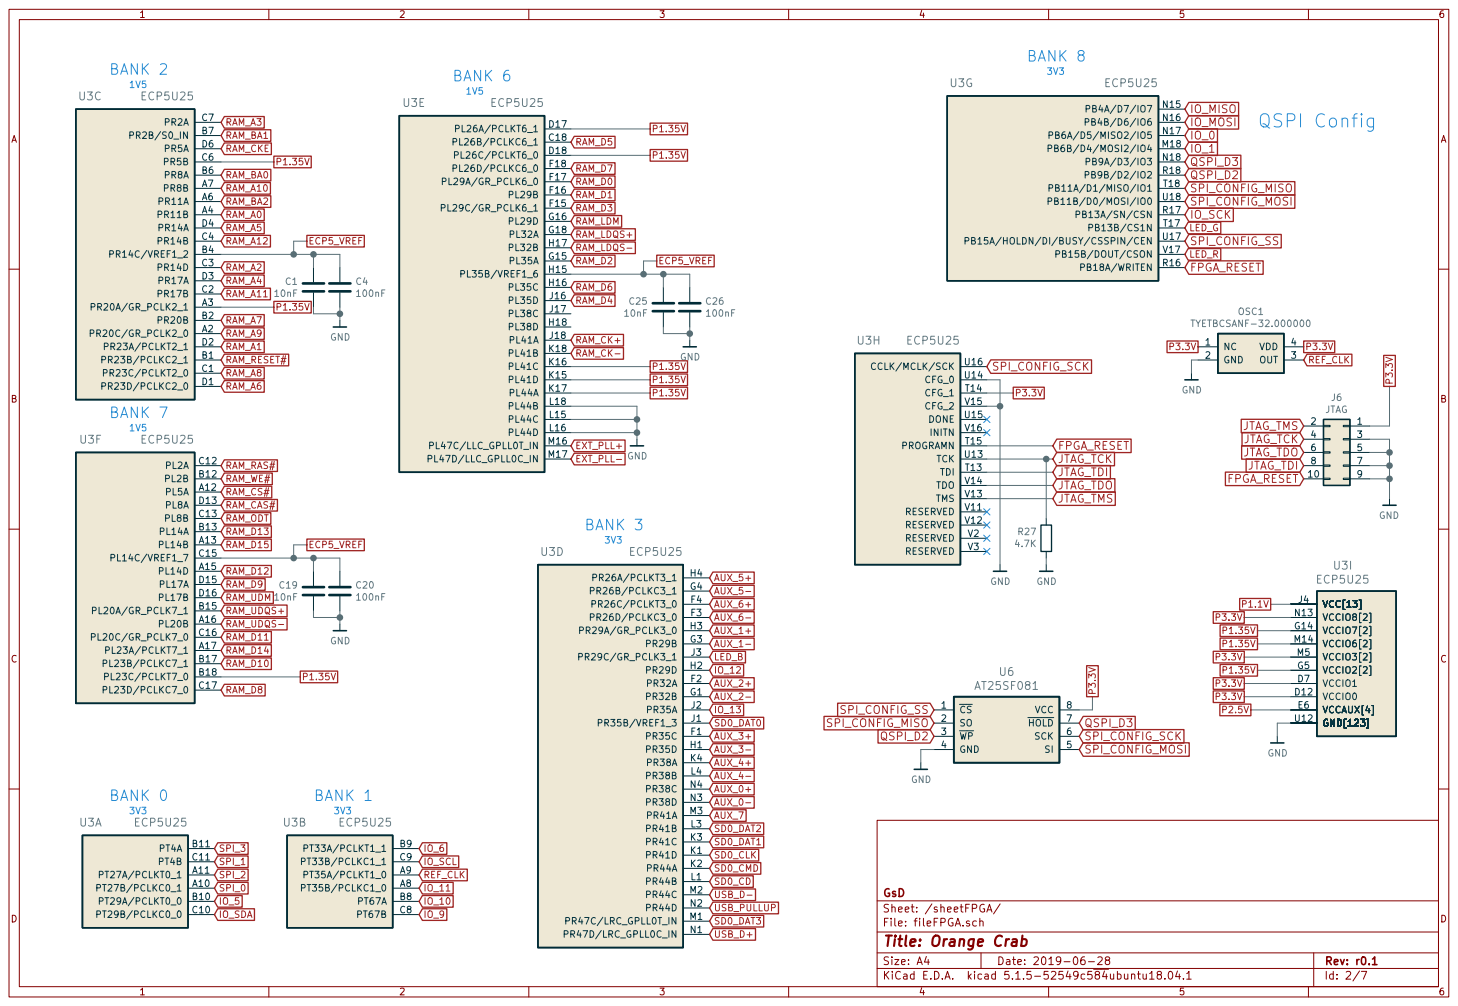
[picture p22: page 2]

File: fileFPGA.sch Sheet: /sheetFPGA/ GsD

Id: 2/7 Title: Orange Crab

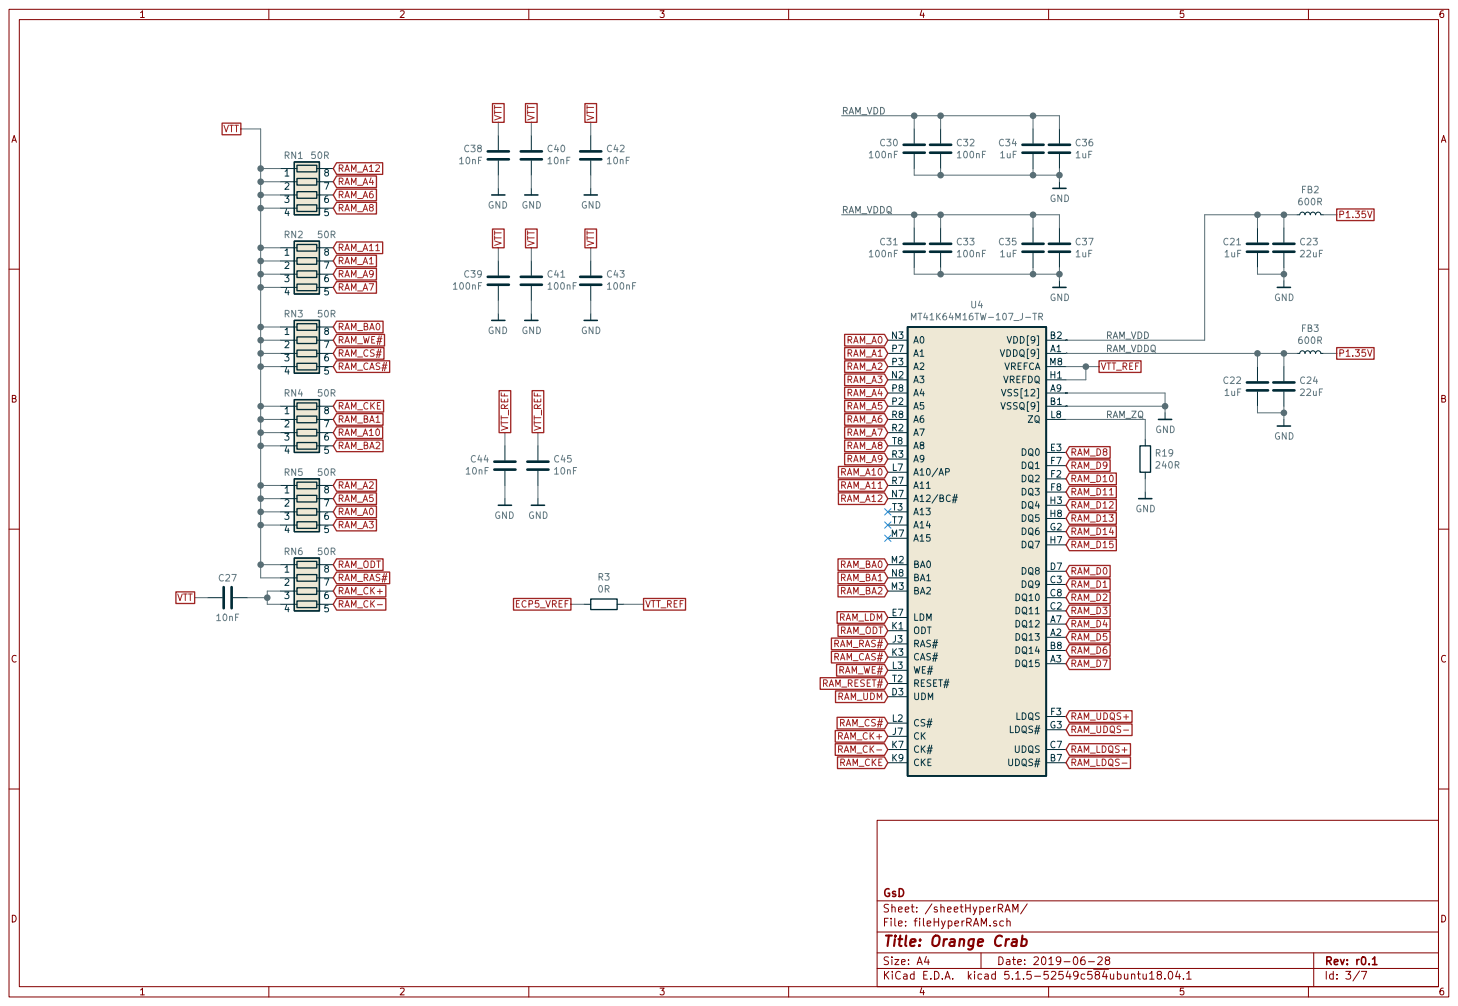
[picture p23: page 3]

File: fileHyperRAM.sch
Id: 3/7 Title: Orange Crab

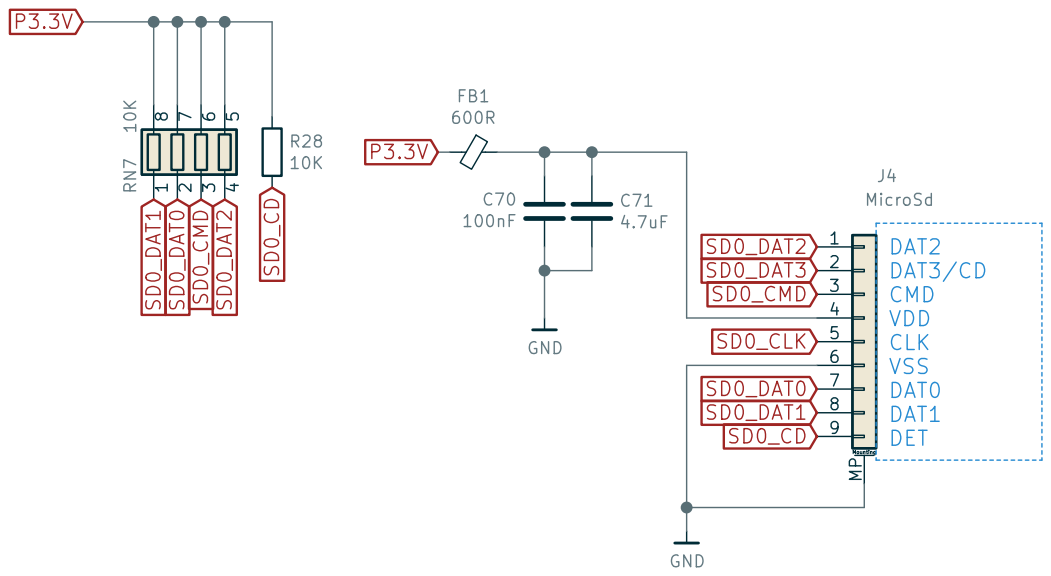
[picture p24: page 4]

File: fileSDMMC.sch Sheet: /sheetSDMMC/ GsD

Id: 4/7 Title: Orange Crab

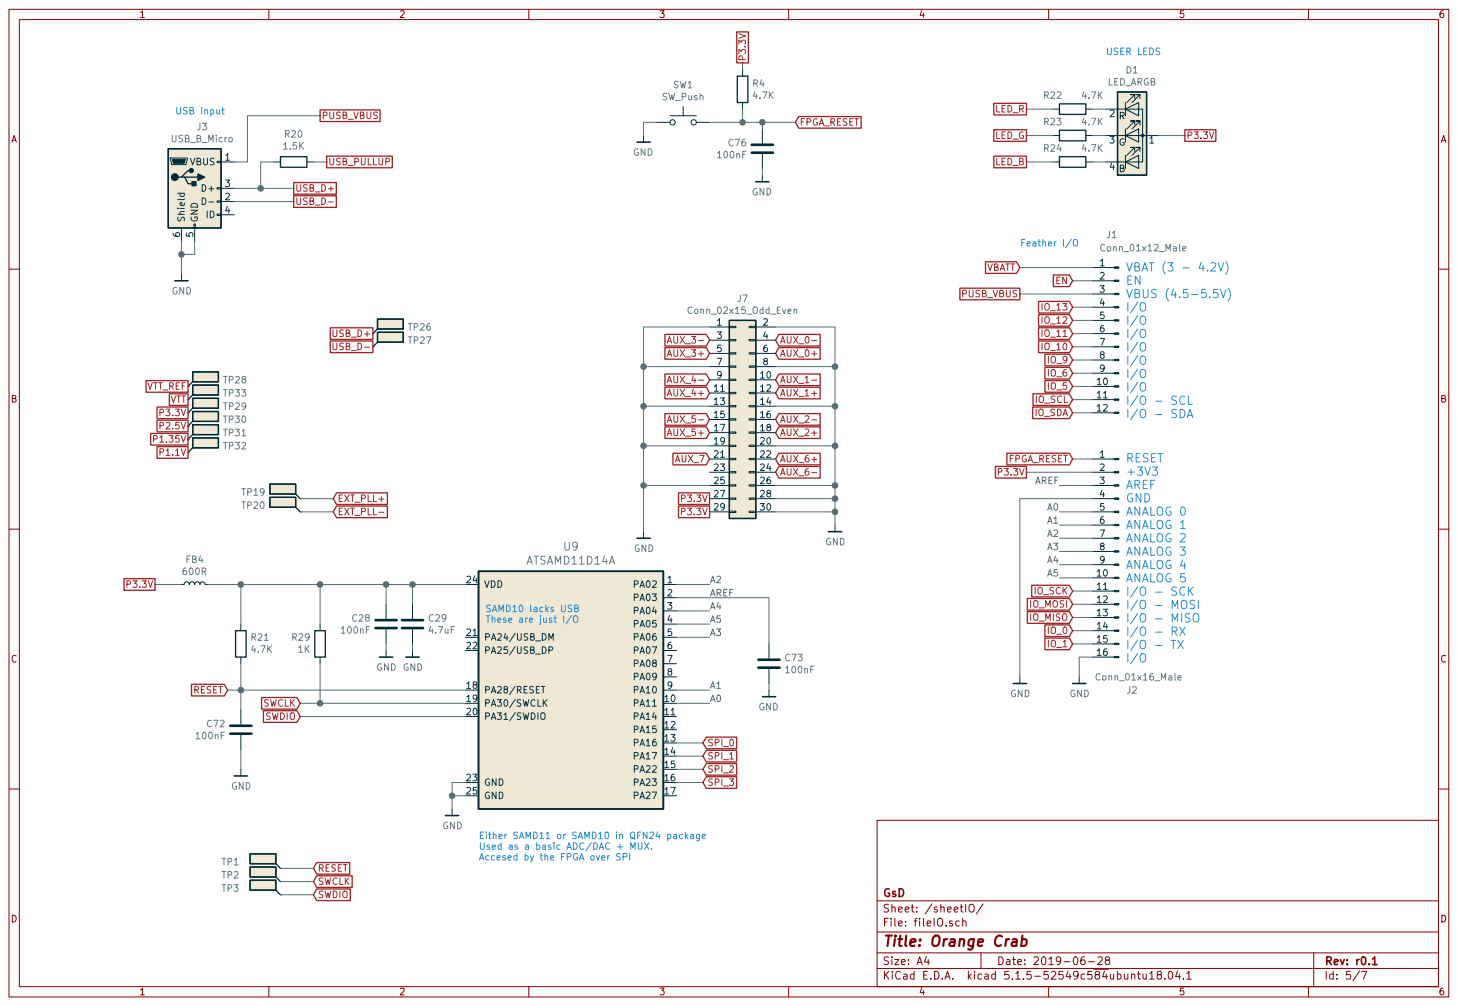
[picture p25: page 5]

19 | 2
293 11 13 | 10 12 14

Either SAMD11 or SAMD10 in QFN24 package Used as a basic ADC/DAC + MUX. Accesed by the FPGA over SPI

File: fileIO.sch Sheet: /sheetIO/ GsD

Id: 5/7 Title: Orange Crab

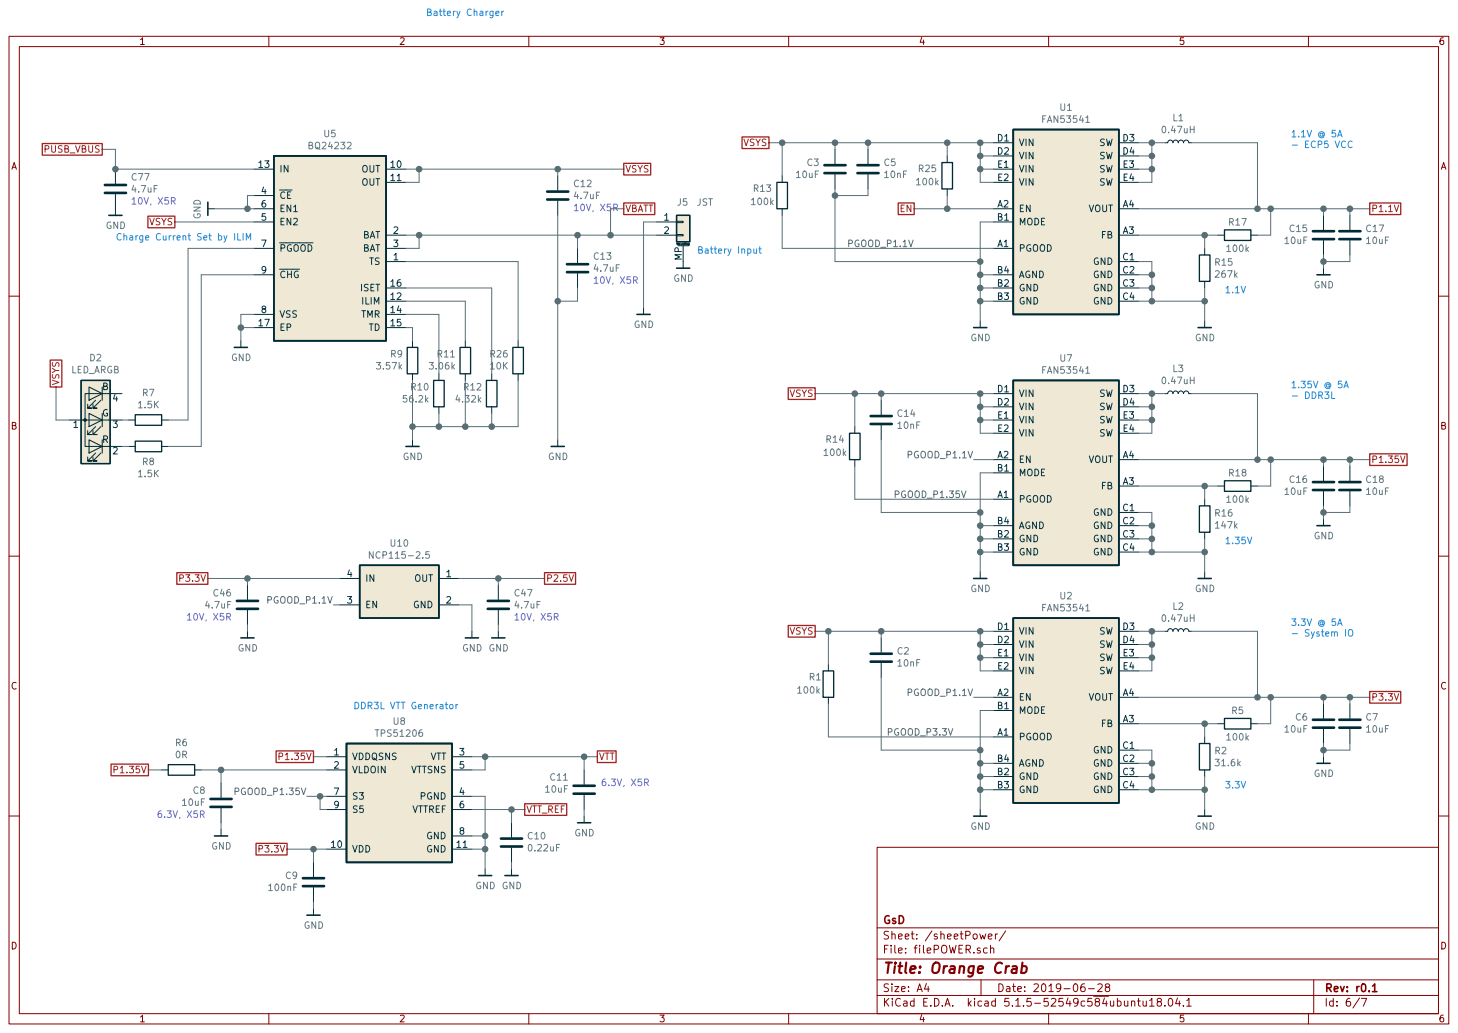
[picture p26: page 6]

GND
1.35V Charge Current Set by ILIM

4.32k R11
3.06k R10

File: filePOWER.sch Sheet: /sheetPower/ GsD

Id: 6/7 Title: Orange Crab

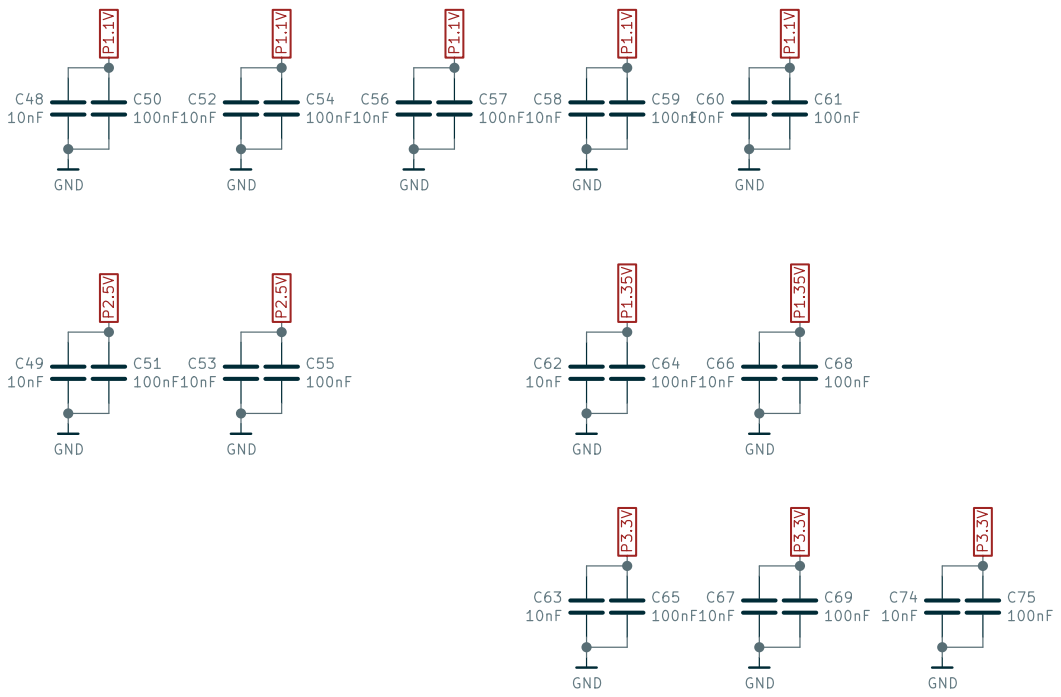
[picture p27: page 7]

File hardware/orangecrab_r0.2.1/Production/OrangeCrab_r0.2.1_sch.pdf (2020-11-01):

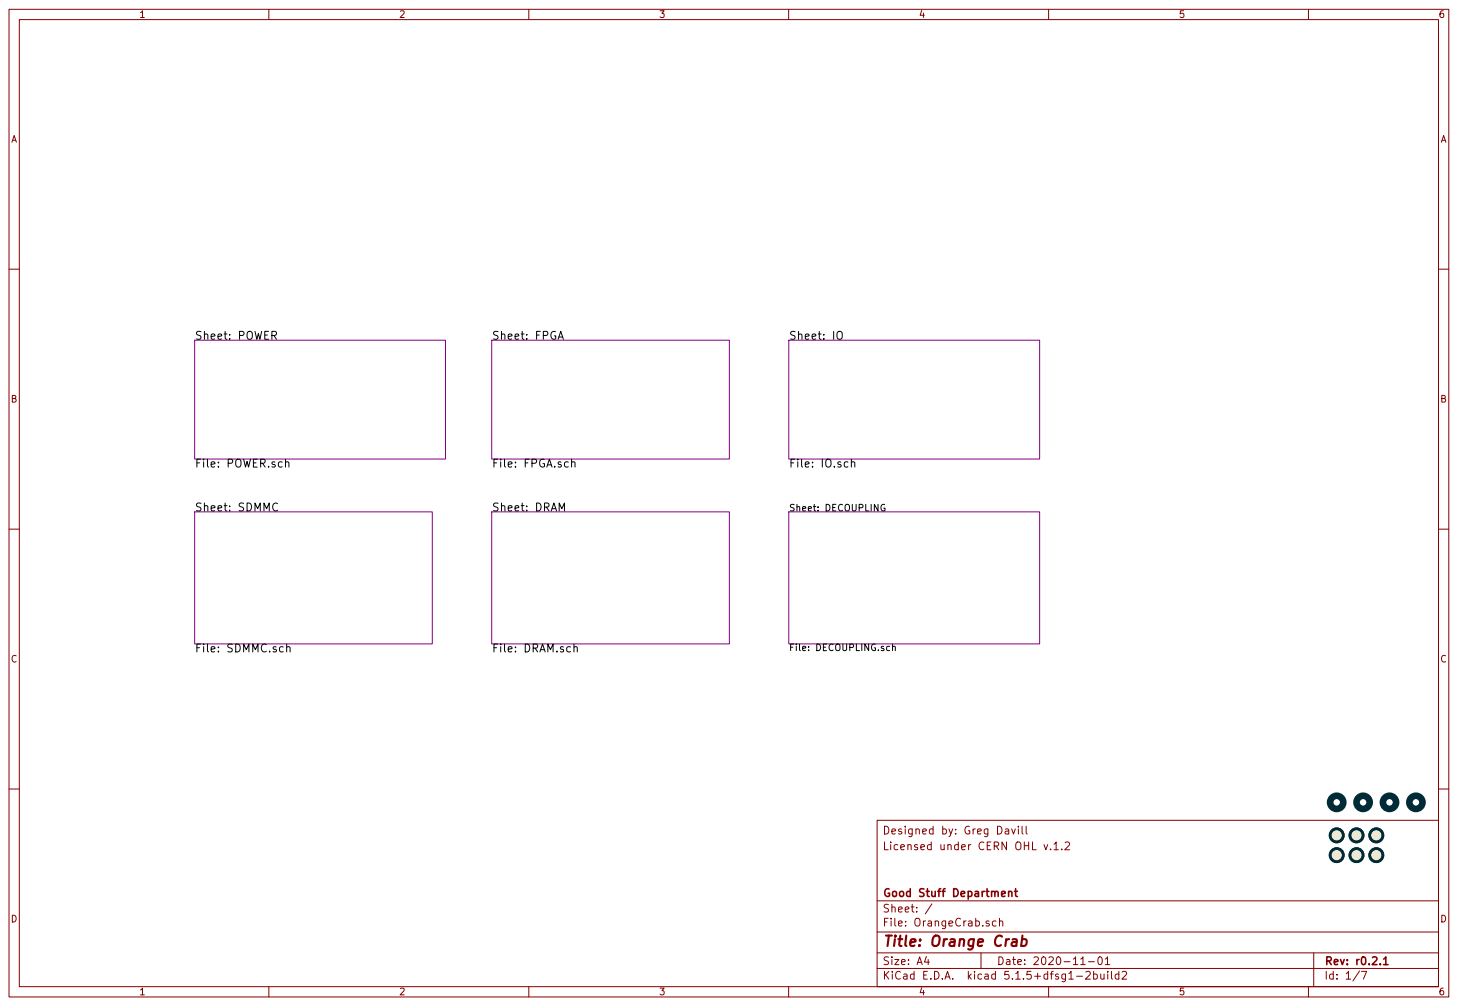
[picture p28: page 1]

File: DRAM.sch Sheet: SDMMC

File: OrangeCrab.sch Sheet: / Good Stuff Department Licensed under CERN OHL v.1.2 Designed by: Greg Davill

Id: 1/7 Title: Orange Crab

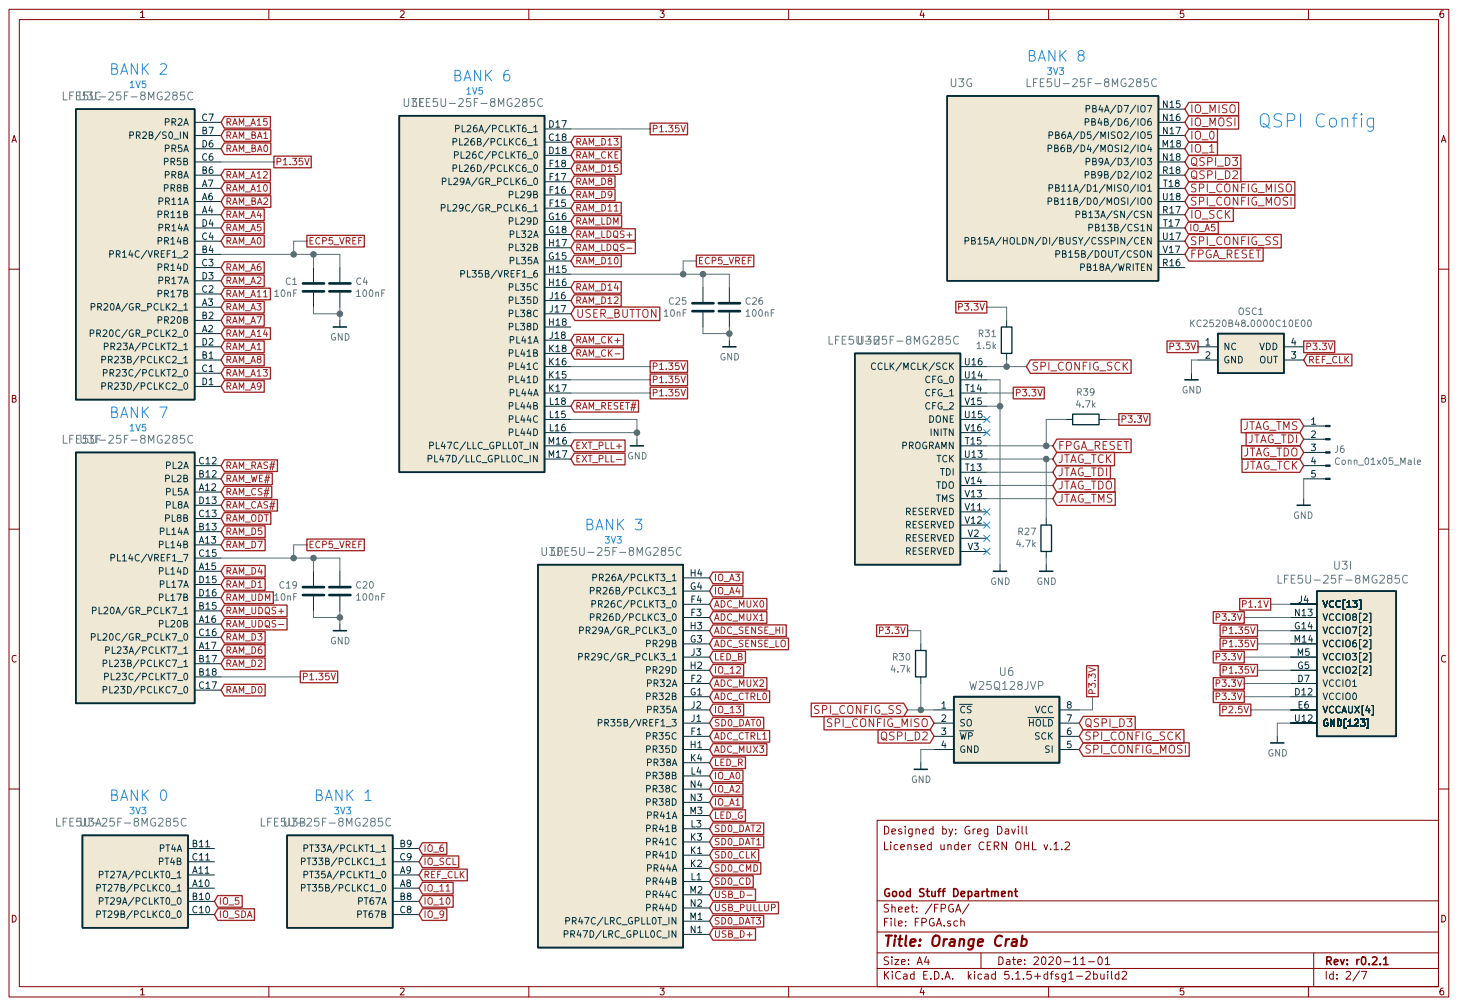
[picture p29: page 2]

Id: 2/7 Title: Orange Crab

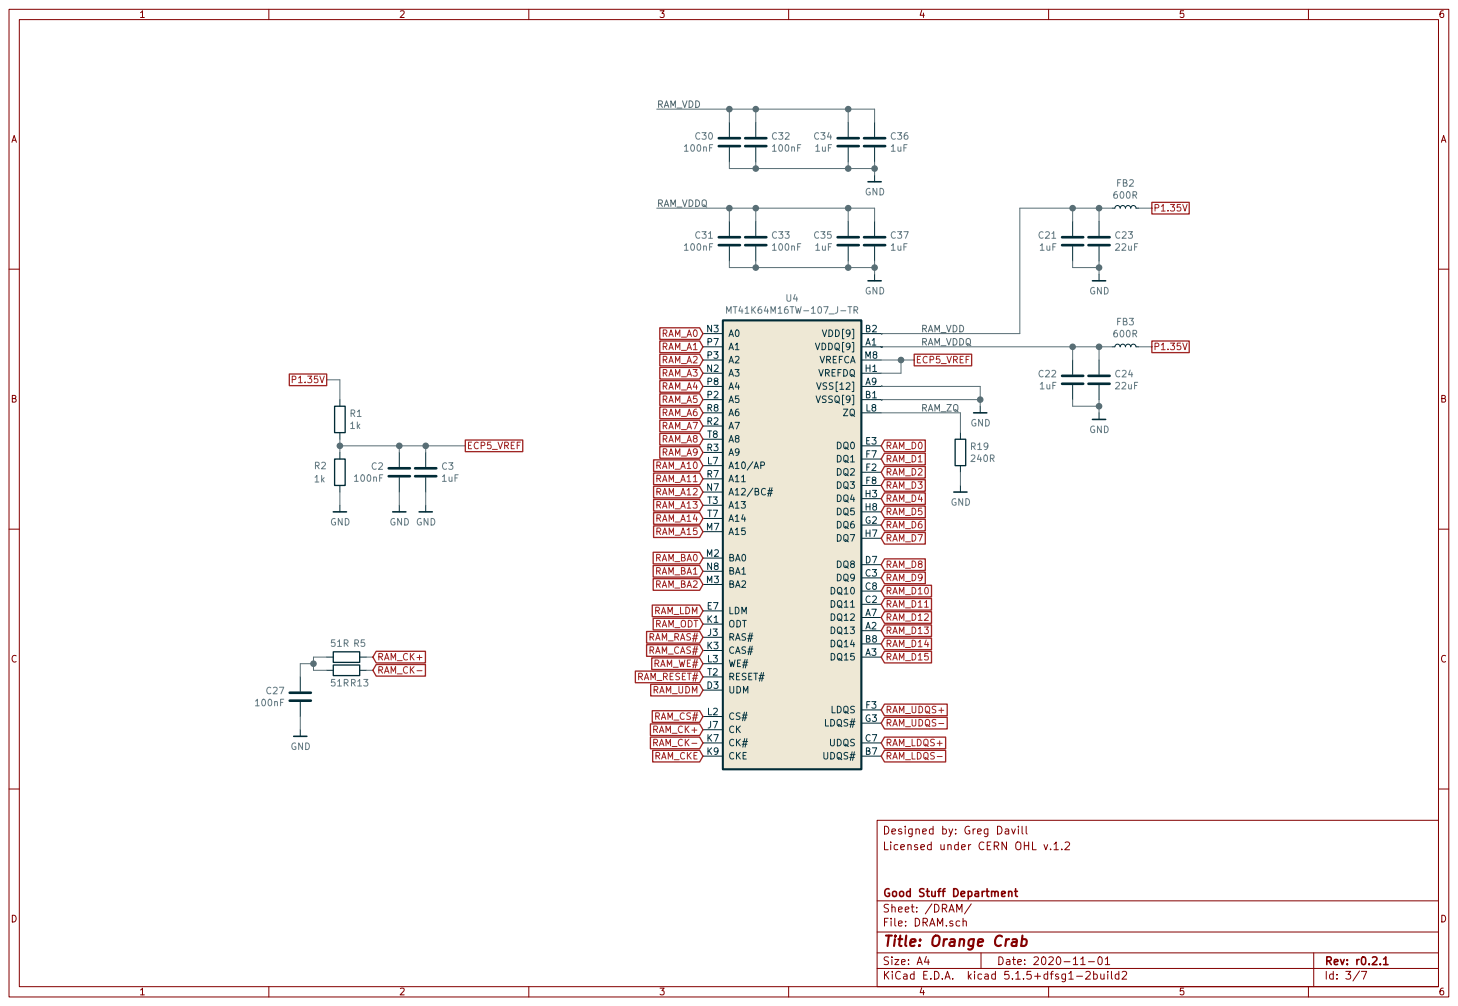
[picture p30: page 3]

RAM_VDD
1uF GND
File: DRAM.sch Sheet: /DRAM/ Good Stuff Department Licensed under CERN OHL v.1.2 Designed by: Greg Davill GND GND

Id: 3/7 Title: Orange Crab

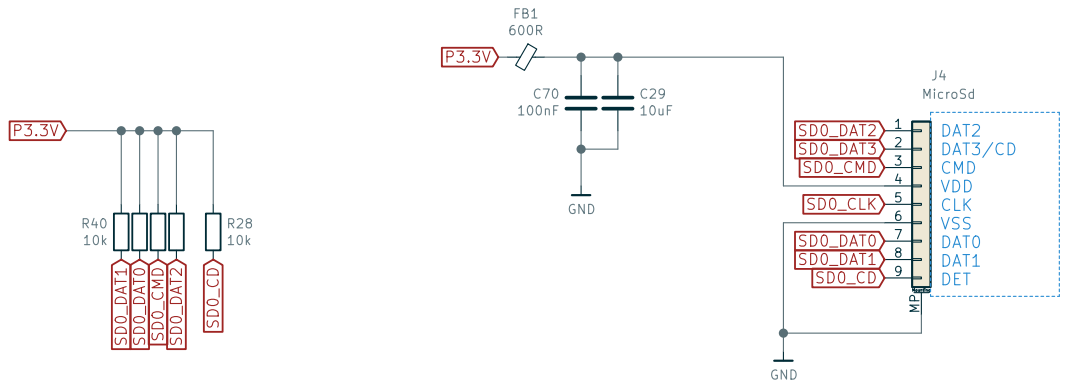
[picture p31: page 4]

File: SDMMC.sch Sheet: /SDMMC/ Good Stuff Department Licensed under CERN OHL v.1.2 Designed by: Greg Davill R40

Id: 4/7 Title: Orange Crab

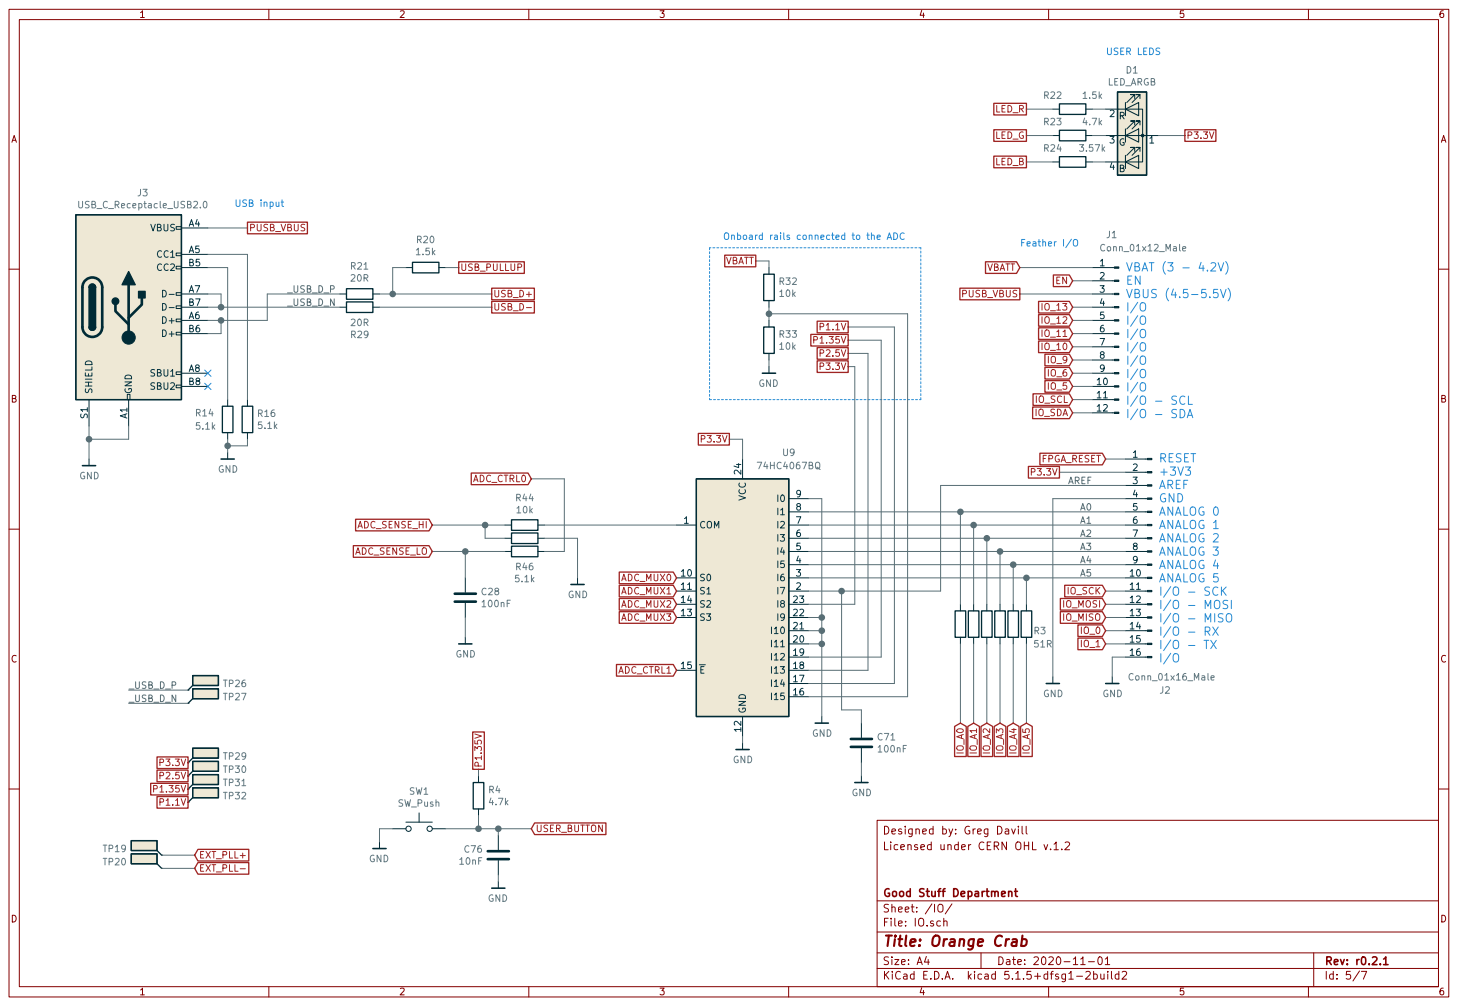
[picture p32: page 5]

Id: 5/7 Title: Orange Crab


2 VIN 3 SW 4 EN 5 U1 TLV62569DRL GND GND GND

2 VIN 3 SW 4 EN 5 U7 TLV62569DRL GND
Charge Current Set by ILIM

2 VIN 3 SW 4 EN 5 U2 TLV62569DRL GND GND

Green: USB present
Yellow: battery is charging

Id: 6/7 Title: Orange Crab


File: DECOUPLING.sch Sheet: /DECOUPLING/ Good Stuff Department Licensed under CERN OHL v.1.2 Designed by: Greg Davill GND

Id: 7/7 Title: Orange Crab

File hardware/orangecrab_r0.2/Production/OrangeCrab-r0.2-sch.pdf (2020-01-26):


File: OrangeCrab.sch Sheet: / Good Stuff Department Licensed under CERN OHL v.1.2 Designed by: Greg Davill

Id: 1/7 Title: Orange Crab


Id: 2/7 Title: Orange Crab


Sheet: /sheetHyperRAM/
File: fileHyperRAM.sch
Id: 3/7 Title: Orange Crab


File: fileSDMMC.sch Sheet: /sheetSDMMC/ Good Stuff Department Licensed under CERN OHL v.1.2 Designed by: Greg Davill C29

Id: 4/7 Title: Orange Crab


File: fileIO.sch Sheet: /sheetIO/ Good Stuff Department Licensed under CERN OHL v.1.2 Designed by: Greg Davill

Id: 5/7 Title: Orange Crab


GND
Charge Current Set by ILIM

File: filePOWER.sch Sheet: /sheetPower/ Good Stuff Department Licensed under CERN OHL v.1.2 Designed by: Greg Davill GND

Id: 6/7 Title: Orange Crab


Good Stuff Department Licensed under CERN OHL v.1.2 Designed by: Greg Davill GND

Sheet: /Decoupling/
File: decopling.sch
Id: 7/7 Title: Orange Crab




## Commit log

2019-06-27 Import existing layout experiments based off bfg.
    [bosonFrameGrabber.kicad_pcb, bosonFrameGrabber.sch, fileBoson.sch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]
2019-06-28 Update schematic
    [bosonFrameGrabber.sch, fileFPGA.sch, fileHyperRAM.sch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]
2019-06-28 Rename project files
    [OrangeCrab.kicad_pcb, OrangeCrab.sch]
2019-07-04 Initial Routing of Memory Traces. Wired up DCDC converters.
    [OrangeCrab.kicad_pcb, fileFPGA.sch, fileHyperRAM.sch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]
2019-07-05 Length matched DDR3 signals
    [OrangeCrab.kicad_pcb, fileFPGA.sch]
2019-07-05 Added SAMD11 to handle Analog I/O
    [OrangeCrab.kicad_pcb, OrangeCrab.sch, fileFPGA.sch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]
2019-07-05 Initial placement of SAMD11
    [OrangeCrab.kicad_pcb, fileFPGA.sch, fileIO.sch]
2019-07-06 Routed more FPGA signals
    [OrangeCrab.kicad_pcb, OrangeCrab.sch, fileFPGA.sch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]
2019-07-07 Added 2.5V regulator. Completed more routing
    [OrangeCrab.kicad_pcb, fileFPGA.sch, fileHyperRAM.sch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]
2019-07-10 Added loads of decoupling capacitors. Added SD card. Started planning out power plane
    [OrangeCrab.kicad_pcb, OrangeCrab.sch, decopling.sch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]
2019-07-12 Completed 99% of routing.
    [OrangeCrab.kicad_pcb, decopling.sch, fileFPGA.sch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]
2019-07-13 Updated RGB LED footprint
    [OrangeCrab.kicad_pcb, fileFPGA.sch, fileIO.sch]
2019-07-14 Updated RAM pins to be compatible with ECP5 rules.
    [OrangeCrab.kicad_pcb, fileFPGA.sch, fileHyperRAM.sch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]
2019-07-14 Completed DDR Routing Added logo to back of PCB Added Fiducials Neatened up power planes Generated Gerbers for PCB fab quote
    [OrangeCrab.kicad_pcb, fileFPGA.sch, fileIO.sch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]
2019-07-16 Fixed USB location Fixed LED positions to match Feather Specs Added Rev number Added Current Date
    [OrangeCrab.kicad_pcb]
2019-07-16 Adjusted Differential routing from ECP5 to DDR3.
    [OrangeCrab.kicad_pcb, fileFPGA.sch, fileHyperRAM.sch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]
2019-07-16 Added JTAG test points
    [OrangeCrab.kicad_pcb, fileIO.sch]
2019-07-16 Routed USB as 90 ohm diff. Added test points to USB
    [OrangeCrab.kicad_pcb, fileIO.sch]
2019-07-16 Added power rail test points
    [OrangeCrab.kicad_pcb, fileFPGA.sch, fileIO.sch]
2019-07-16 Added pulldown on TS pin to disable TS func. Added 4.7uF cap to USB input. Corrected Battery polarity Calculated correct DCDC Fb Added pullup to SWCLK Added Pulldown to TCK Added Pinout legend on top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
    [OrangeCrab.kicad_pcb, decopling.sch, fileFPGA.sch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]
2019-07-16 Corrected Mirrored footprint Removed some vias to reduce plane cutouts Completed majority of checklist items.
    [OrangeCrab.kicad_pcb, fileFPGA.sch]
2019-07-17 Updated Readme with images
    [OrangeCrab.kicad_pcb]
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2019-07-17 Fix stale comment on PSU voltage/subsystem
    [filePOWER.sch]
2019-07-17 Fixed TPS551206 regulator footprint 2x2 DFN10
    [OrangeCrab.kicad_pcb, filePOWER.sch]
2019-07-18 Rerouted User Io to provide a common connector. Diff pairs routed. Updated gkl to include new connector. Removed old test points Removed JTAG test points on bottom layer. Moved micro SD card Moved so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
    [OrangeCrab.kicad_pcb, fileFPGA.sch, fileIO.sch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]
2019-07-18 Shift MicroSD card socket away from USB by 0.3mm
    [OrangeCrab.kicad_pcb]
2019-07-18 Update date on back of PCB
    [OrangeCrab.kicad_pcb]
2019-07-20 Updated BOM fields in KiCad project Exported ibom Clarify fab notes
    [OrangeCrab.kicad_pcb, decopling.sch, fileFPGA.sch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]
2019-07-21 Changed FPGA part number. regen ibom with newest version
    [fileFPGA.sch]
2019-08-04 rev0.1: Updated stencil apertures on BGA parts.
    [OrangeCrab.kicad_pcb]
2019-08-04 Update PN/MFG of resistor packs
    [fileHyperRAM.sch, fileSDMMC.sch]
2019-09-17 r0.1 PCB: Switch P1.5 to P1.35V
    [OrangeCrab.kicad_pcb, OrangeCrab.sch, decopling.sch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]
2019-11-07 Added ddr3 test gateware
    [analyzer.csv, csr.csv]
2019-11-29 Updated Litex_DDR3Soc code, and readme
    [csr.csv]
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2019-12-04 Added OrangeCrab r0.1 Stencil/Gerbers/BOM
    [OrangeCrab.csv]
2019-12-07 hw: Initial import of OrangeCrab r0.2
    [OrangeCrab.kicad_pcb, OrangeCrab.sch, decopling.sch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]
2019-12-07 hw: Update I/O block routing new DDR3 signals.
    [OrangeCrab.kicad_pcb, fileFPGA.sch, fileHyperRAM.sch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]
2019-12-07 hw: update DDR3 signals
    [OrangeCrab.kicad_pcb, fileFPGA.sch, fileHyperRAM.sch]
2019-12-08 hw: Completed first pass of new DD3 routing.
    [OrangeCrab.kicad_pcb, fileFPGA.sch, fileHyperRAM.sch]
2019-12-08 hw: Update microSD card
    [OrangeCrab.kicad_pcb, fileHyperRAM.sch, fileSDMMC.sch]
2019-12-08 hw: Routed new FLASH footprint Working on new Analog domain
    [OrangeCrab.kicad_pcb]
2019-12-08 hw: Routed analog section General cleanup
    [OrangeCrab.kicad_pcb, fileIO.sch]
2019-12-08 hw: Update board with 3d models Finish pin-swaps and routing of open changes General cleanups
    [OrangeCrab.kicad_pcb, fileFPGA.sch, fileHyperRAM.sch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]
2019-12-08 hw: Route last FPGA I/O to A[0-5]
    [OrangeCrab.kicad_pcb, fileFPGA.sch, fileIO.sch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]
2019-12-08 hw: Update fiducials Add pullup to FLASH CS/SCK line Update BOM part numbers Fix Button pull-up voltage
    [OrangeCrab.kicad_pcb, OrangeCrab.sch, fileFPGA.sch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]
2020-01-06 hw r0.1: Update Part numbers, regenerate csv/ibom. Upload schematic
    [OrangeCrab.csv, OrangeCrab.sch, decopling.sch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]
2020-01-15 Use $KIPRJMOD for relative paths
    [OrangeCrab.kicad_pcb]
2020-01-15 hw.r0.2: fixed U10 3d model ref
    [OrangeCrab.kicad_pcb]
2020-01-25 hardware/orangecrab_r0.2: r0.2 Release
    Prepared KiCad files for release
    Create production folder
    Add pdf schematic
    [OrangeCrab-r0.2-bom.csv, OrangeCrab.kicad_pcb, OrangeCrab.sch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]
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2020-01-26 hardware/orangecrab-r0.2: Updated production files - Fixed fab attribute of some parts so they appear in positon file. - Regenerated outputs
    [OrangeCrab-r0.2-bom.csv, OrangeCrab.kicad_pcb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]
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2020-05-09 hw.r0_2: DFM changes to stencil layer
    [OrangeCrab.kicad_pcb]
2020-05-10 gateware: remove gateware example from this repo
    [analyzer.csv, csr.csv]
2020-05-27 mech: Add STLs for enclosure
    [Orange_Crab_Case_Bottom_v3.stl, Orange_Crabe_Case_Top_v4.stl]
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2020-09-22 hw.r0.2.1: Add design files for updated version
    [OrangeCrab.kicad_pcb, OrangeCrab.sch, decopling.sch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]
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2020-10-06 hw.r0.2.1: Update voltage divider values
    Change to r32 and r33 form 100k to 10k, and regenerate schematics.
    Fixes #30
    [DECOUPLING.sch, DRAM.sch, FPGA.sch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]
2020-11-01 hw.r0.2.1: Update BOM values
    I'd forgotten to update the part numbers for R32 and R33 in the last
    commit. These are now updated.
    Also regenerated PDF schematics
    Issue #30
    [DECOUPLING.sch, DRAM.sch, FPGA.sch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]
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2021-02-18 r0.2.1: Add csv pos files
    [OrangeCrab-bottom-pos.csv, OrangeCrab-top-pos.csv]
2021-08-06 r0.2.1: Update R15,R35
    Fix error in BOM part numbers for R15,R35.
    Fixes #40
    [OrangeCrab-bom.csv, POWER.sch]
2021-09-03 doc: Add battery info
    fixes #42
2021-12-04 contib: Add OpenOCD FTDI configs
    Closes #47
    [orangecrab-25f.cfg, orangecrab-85f.cfg]
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
